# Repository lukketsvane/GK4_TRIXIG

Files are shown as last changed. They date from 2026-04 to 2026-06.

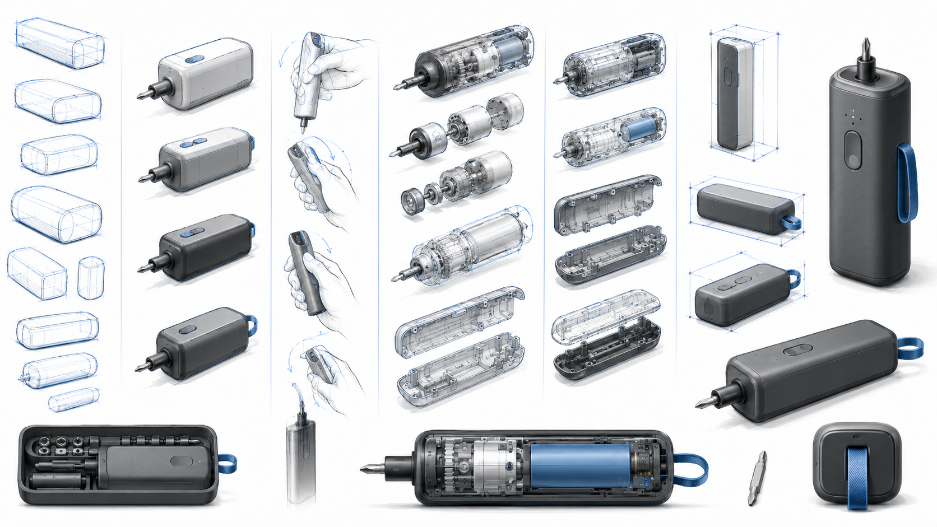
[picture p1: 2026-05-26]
assets/generated/gen_26_05/06_ideation_grids/trixig_260526_u158_component-catalog-board.png

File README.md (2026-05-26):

# GK4_TRIXIG

Organized project repository for the TRIXIG redesign work.

## Structure

- `docs/` - project writing, course material, reports, brand notes, and cleanup records.
- `assets/` - reference images, teardown photos, finished graphics, generated concepts, and visual studies.
- `cad/` - Fusion, Blender, Plasticity, print, and model assets.
- `methods/` - Tjalve and method reference material.

Large local-only files at or above 100 MB are kept out of Git under `.local_large_files/`.
Cleanup decisions are recorded in `docs/repo_cleanup/cleanup_manifest.csv`.

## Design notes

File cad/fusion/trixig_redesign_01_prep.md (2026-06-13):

# TRIXIG redesign_01 — Blender prep for Fusion rebuild (2026-06-13)

Source: Blender scene **`redesign_01`** in `trixig_original_and_drafts.blend`.
This documents the sectioning / parting-split / screw layout done on the new sculpt and
the data exported for rebuilding it parametrically in Fusion 360 (next phase, via Fusion MCP).
Mirrors the recipe of the existing master **"IKEA TRIXIG 3.6 original"**
(see `trixig_cad_rebuild_notes.md`).

## Source geometry (in `redesign_01`)

- **`main shell.001`** — 527k-vert hand sculpt = body + grip clamshell. Not watertight
  (147 open edges). This is the part that gets split at Y=0.
- **`front_shell.001`** — separate **nose cap** (X < −159), a distinct molded part; not part
  of the Y=0 body clamshell. Rebuild as its own part in Fusion.
- Accents: `triggere.001`, `reverse.004/005` (fwd/rev rocker), `detail.002/003`, `bit_holder.001`.

All prep work lives in a new collection **`redesign_01_prep`** (delete to revert; the sculpt
master is untouched — work was done on a duplicate `prep_shell_solid`).

## Frame & key dimensions (redesign_01 world, mm)

- **Parting plane = world Y = 0** (global XZ plane). Sculpt is symmetric about it
  (Y centroid 0.06 mm). Split convention: `Shell_Front_pY` (+Y) / `Shell_Back_nY` (−Y),
  same as master's Body_Front/Body_Back.
- Main-shell extents: X [−178.2, 0.6], Y [−24.5, 24.0], Z [3.7, 125.1].
  Full housing (with nose) reaches X −211 (bit-holder/spindle tip).
- **Drive axis**: world −X, at Y = 0, Z = 97.2. Spindle tip at X −211, motor rear at X −104.6.
- Base (lowest point, USB-C/lanyard): X ≈ −45, Z ≈ 3.7. Rear heel: X 0 … −15.

## Internal components (proxies fitted; full meshes exist on disk)

From documented caliper teardown (`assets/reference/teardown/`,
`trixig_motor_girmodul.py`, `trixig_pcb_battery_blender.py`):

- **Motor/gearbox** (total 106.4 mm) on the drive axis: can Ø32×47 → gearbox Ø35×32.4 →
  front boss Ø18×3 → shaft Ø10×24. World X −104.6 (rear) → −211 (tip), Z 97.2, Y 0.
- **PCB+battery**: PCB 95.39×26.31×1.6 with 18650 Ø18.6×65.0 stacked on top (stack ≈20.2).
  Stands raked in the handle: motor-wire end ≈ (−105, 0, 90), **USB-C end at the base**
  ≈ (−45, 0, 12); axis dir (0.61, 0, −0.79), board normal (0.79, 0, 0.61).
- Faithful meshes if needed: `cad/fusion/pcb_battery_asset/trixig_pcb_battery_scaled.obj`,
  `cad/print/trixig_redesign/for_bambu/{motor_gear_module,pcba_board}.stl`.

## Screw system — 5 bosses (final, user-reviewed)

Clamshell screws on the Y=0 plane, **axis along Y**. Spec: Ø2.4 pilot, Ø8.6 × 10 boss,
**M3×12 self-tapping** (matches prior print build `screw_m3x12_0X.stl`).
Layout was placed clear of all keep-outs (motor, battery, fwd/rev rocker, trigger, and the
**base strap/USB cord passage** — deliberately left screw-free), then adjusted by the user:
the original rear-mid screw was removed (→ 5 total) and S1/S2 moved forward to flank the thin
nose shaft at the `front_shell` junction (X < −178) rather than the fat gearbox.

| Screw | X | Z | role |
|---|---|---|---|
| S1 | −189.2 | 110.5 | nose/shaft, top |
| S2 | −189.9 | 83.2  | nose/shaft, bottom |
| S3 | −98.7  | 114.9 | upper body |
| S4 | −69.3  | 34.3  | grip, low |
| S6 | −10.0  | 60.0  | rear heel |

(`screws.json` holds the authoritative coordinates.)

## Debossing

Use repo **`ikea.svg`** (IKEA wordmark, viewBox 751×138, single path, #0058A3) — NOT the
in-scene grease-pencil `ikea.svg`. Per master: badge 38×13 mm R3.5 raised on +Y shell;
wordmark 33 mm wide, debossed 0.4 mm, A-counter island preserved.

## Exported handoff — `cad/fusion/redesign_01/`

| File | Use |
|---|---|
| `sections.json` | Y0 silhouette (78-pt, [X,Z]) + 7 transverse stations (uv + plane co/normal). Primary Fusion sketch input. Ignore loops < 8 pts (sculpt noise). |
| `parting_Y0.dxf` / `.svg` | Y0 silhouette, manual-insert fallback (true mm). |
| `screws.json` | 6 positions + fastener spec. |
| `internal_layout.json` | Motor + PCB/battery placement. |
| `Shell_Front_pY_mm.stl` / `Shell_Back_nY_mm.stl` | Split halves, mm, as visual/measure reference (solid, not yet shelled). |

## Fusion rebuild recipe (next phase, via Fusion MCP)

1. Insert/loft the **Y0 silhouette** (sections.json) on the XZ plane → main solid; refine
   profile against the transverse stations.
2. Split on Y=0 → Body_Front (+Y) / Body_Back (−Y).
3. **Shell to 1.6 mm** (remove pilots/bosses first, re-add after — small/raised features
   can't offset; see master gotchas).
4. Add 6 Ø8.6 bosses on Body_Back at the screw (X,Z); Ø2.4 pilots through both halves.
5. Badge + debossed IKEA wordmark on +Y shell.
6. Openings: fwd/rev rocker slot, USB-C pill at the base.
7. Nose cap (`front_shell`) as a separate part around the gearbox/spindle.

## Caveats

- Sculpt is not watertight; STL halves are solid blocks (Fusion rebuilds clean surfaces from
  the section profiles — the meshes are measurement references only).
- Component proxies are envelopes from caliper dims; placement verified visually against the
  Y0 outline but is ±a few mm — re-confirm clearances once Body shells exist.
- No Fusion MCP was connected during this prep; the rebuild is the next session.

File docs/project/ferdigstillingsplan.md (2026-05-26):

# Ferdigstillingsplan — GK4 V26 Modul 2 TRIXIG

*Generert 28. april 2026 (dag 2 av 18). Sluttfrist 27. mai 2026.*
*Basert på gjennomgang av designbrief, prosjektbeskrivelse, debrief-utkast, eksisterande figurar/skisser, og Skulberg/Bjørnstad si metodikk-forelesing.*

---

## 0. Tidsline (dei kritiske datoane)

| Dato | Klokke | Leveranse | Form |
|---|---|---|---|
| **Ma 4. mai** | 09:00 | Personleg debrief | Moodle (PDF/DOCX) |
| **Fr 8. mai** | dagtid | Konseptgjennomgang (gruppeseanse) | Munnleg + 3 fysiske skissemodellar |
| **Fr 8. mai** | 20:00 | 3B-analyse, kravspec, bærekrafthandling, 3 konsept­bilete + valt | Moodle |
| **Ma 11. mai** | 09:00 | Formføringsplansje + 3 verdiord | Moodle |
| **On 13. mai** | dagtid | Gjennomgang formkonsept (gruppeseanse) | Munnleg |
| **Ma 25. mai** | 20:00 | Digital sluttpresentasjon + 3 modellbilete | Moodle |
| **Ti–On 26.–27. mai** | plenum | Sluttpresentasjon + 1:1 utseendemodell | Munnleg + fysisk |

---

## 1. Status — kva som finst, kva som manglar

### 1.1 Kva som er ferdig eller nær ferdig

**Tekstgrunnlag:**
- `debrief-modul2-trixig.docx` — fullstendig 7-seksjons debrief med marknadsanalyse, teardown, EU-rammer, R2R-indeksar, materialkunnskap, ergonomi, brukar­innsikt, problemområde, 3B-analyse, kravspec og kjelder. Klart til formattering for innlevering.
- `notat/Konseptgjennomgang_8mai.md` — 12 slides med tre konseptforslag (Trixig+, Tactil, Modular), vurderingsmatrise og valt konsept. Manglar berre fotografi av dei fysiske skissemodellane.
- `notat/Formføringsplansje_11mai.md` — fullstendig drøfting av tre verdiord (Synleg, Stille, Truverdig) med referanseobjekt og A3-layout-spec. Manglar bildemateriale frå referanseobjekta og final A3-eksport.
- `notat/Prototypedokumentasjon.md` — full byggjeplan med BOM, leverandørar og tidsplan for både foam-prototype (P1) og funksjonell prototype (P2).
- `notat/Produksjonskjede_TRIXIG.md` — 10-leddskartlegging av forsyningskjeda frå kobolt til kassering, med IKEA-eigarstruktur og IWAY-grenser.

**Visuelt grunnlag:**
- `ferdigstilt_grafikk/figurar/figur=01..13` — ferdige illustrasjonar (heroshot, hand­percentilstudie ×2, regulatorisk tidsline, kritikkringen, IKEA-stigen, FIXA-vs-TRIXIG-eske ×2, instegspris, naming­kritikk, forretningsmodell-tidsline, posisjoneringskart, spesifikasjonsark).
- `ferdigstilt_grafikk/grafikk=01..04` — IKEA-logo-variantar.
- `ferdigstilt_grafikk/skisser/` — produktskisser med bakgrunn fjerna (Trixig-illustrasjon, exploded view, serviceport).
- `ferdigstilt_grafikk/teardown/` — fem teardownfoto.
- `skisser/skisse_001..100` + `skisser/figur/figur_001..029` — 130+ konseptskisser (rådata).

**Modellgrunnlag:**
- `trixig/trixig.usdz` — eksisterande 3D-fil av originalen (referanseobjekt for sammenlikning).
- `teardown/Trixig_plus.scad` — OpenSCAD-utkast (sjekk om det er nyttig for Fusion-import eller om me skal byggje frå null).

### 1.2 Kva som manglar

**Research som ikkje er gjort enno:**
- Kvantitativ brukarundersøking (sjå seksjon 3.1).
- Strukturerte brukarintervju og observasjon (sjå 3.2).
- Antropometriske målingar i hovet (eigen hand mot DINED 5/50/95-percentilar) (sjå 3.3).
- Konkurrent-prising og hyllesjekk i fysisk butikk (Biltema, Clas Ohlson, Jula, IKEA) (sjå 3.4).
- Brand-audit av TRIXIG-serien (heile sortimentet, ikkje berre 3,6 V) (sjå 3.5).

**Spesifikasjonar som ikkje er detaljerte:**
- Komplett BOM for Trixig+ med leverandørar, einingspris og kostnadsmål (skal liggje under +11 NOK per eining over original).
- Strektegning A3 sideview med kotering.
- Materialspec med ISO 11469-koder, rPCR-andel, leverandørreferansar.
- CMF-board (Colour-Material-Finish) med fysiske prøver.
- Tolerance-spec for 18650-fjørholder, kapsling-pasning og Torx-skruekrager.

**Modellbygging:**
- 3 blåskum-skissemodellar for konseptgjennomgang 8. mai.
- 1 blåskum 1:1 utseendemodell for sluttpresentasjon (utan farge per krav).

**CAD:**
- Fusion 360-modell (heile produktet, inkludert eksplodert visning).
- 3D-rendering for digital presentasjon.

**Designdagbok:**
- Ingen eksisterande fil. Skal førast fortløpande — sjå 6.

**Innleverings­filer:**
- Eksport av debrief til PDF.
- Eksport av Konseptgjennomgang til presentasjons-PDF + separate Moodle-filer.
- Eksport av Formføringsplansje til A3-PDF.
- Sluttpresentasjon (PowerPoint eller Keynote).

---

## 2. Leveransematrise

| Leveranse | Krav (frå kursdok) | Status | Kva manglar | Frist |
|---|---|---|---|---|
| Personleg debrief | Designbriefen reflektert + eige standpunkt | Utkast komplett | Format­tering, illustrasjons­plassering, eksport til PDF | 4.5. 09:00 |
| 3B-analyse | Brukar / Bruksituasjon / Bruksmåte | Utkast i debrief + slide 4 i Konseptgjennomgang | Standalone PDF, kanskje styrkast med kvant data | 8.5. 20:00 |
| Kravspec | Estetisk/Ergonomi/Teknisk/Marknadsøkonomi/Bærekraft + Skal/Bør/Kan | 30 krav lista i Konseptgjennomgang slide 5; 6 kategoriar i debrief 5 | Konsolidering til éin matrise (5×3) etter Skulberg si mal, prioriteringsmerking | 8.5. 20:00 |
| Bærekrafthandling | ≥ 1 konkret handling med målbar effekt | Definert (utbyttbart batteri + reparerbart hus + ISO-merking + 7 års reservedelar) | Standalone PDF med målbar effekt-estimat | 8.5. 20:00 |
| 3 konseptforslag | Skissemodellar + bilete | Konsept utvikla på papir; modellar ikkje bygde | **Bygg 3 blåskum-modellar; fotografer**| 8.5. 18:00 |
| Vald konsept | Markering | Trixig+ er valt i tekst | Ein-setning .txt + foto av valt | 8.5. 20:00 |
| Formføringsplansje | A3 med 3 verdiord + form-DNA | Tekst komplett | Eksport, referansebilete, strekteikning | 11.5. 09:00 |
| Sideview-strekteikning A3 | Som grunnlag for volummodell | Skisse i Prototypedok kap. 3 | Reint A3-format med kotering | 11.5. 09:00 |
| 1:1 fysisk utseendemodell | Utan farge | Ikkje starta | **Bygg etter blåskum-prosess** | 25.5. 18:00 (foto­dato) |
| 3 modellbilete | Front, side, perspektiv | n/a | Ta etter modell ferdig | 25.5. 20:00 |
| Fusion 360 CAD | Detaljert med modulgrenser | Ikkje starta (.scad finst som grunnlag) | **Heil modellering** | 25.5. 18:00 |
| 3D-rendering | I Fusion 360 | Ikkje starta | Render etter CAD ferdig | 25.5. 18:00 |
| Digital sluttpresentasjon | Løysing + bærekrafthandling + materialvalg + formuttrykk + brand-pos + render | Ikkje samla | **Slå saman alle delar i éin PPT/Keynote** | 25.5. 20:00 |
| Designdagbok | Fortløpande | Ikkje ført | **Føre kvar dag** (sjå 6) | løpande |

---

## 3. Research-plan

Briefen er i hovudsak skriven, men det manglar empiri som vil styrke argumenta i sluttpresentasjonen og som sensorane vurderer under "prosjektets troverdighet i bedriftskontekst" og "produktets bruksverdi for tiltenkte sluttbruker". Research­arbeidet bør komprimerast til ei intens veke (28. april–4. mai), parallelt med ferdigstilling av debriefen.

### 3.1 Kvantitativ brukarundersøking

**Mål:** Validere persona-hypotesane i debriefen (ambisiøs amatør, leigetakar/student, sporadisk brukar). Få fram tal for jobs-to-be-done, smertepunkt og betalingsvilje.

**Metode:** Online-spørjeskjema via Google Forms eller Typeform, distribuert i tre kanalar:
- AHO/UiO-studentkull (leigetakar/student-segment)
- Facebook-grupper for DIY ("Jeg liker å bygge", "Oppussings­tips") (amatør-handverkar)
- Eige nettverk via LinkedIn (sporadisk brukar)

**Spørsmål (ca. 20 stk):**
1. Eig du elektrisk skrutrekkar? Kva merke/modell?
2. Kor ofte brukar du han? (skala: kvar dag — aldri)
3. Kva oppgåver brukar du han til? (multi-select: flatpakke-møblar, gardin­stenger, dørhandtak, hyller, småreparasjon, anna)
4. Kor mykje betalte du? Var det med tilbehør i esken?
5. Har batteriet svikta? Kva gjorde du då?
6. Har du forsøkt å reparere? Kva hindra deg?
7. Kor viktig (1–5) er: pris / merke / reparerbarheit / utskiftbart batteri / tilbehør i esken / ladetid / vekt / dreiemoment?
8. Skala 1–5: kor mykje ekstra ville du betalt for: utskiftbart batteri / 7 års reservedelar / tilbehør i esken / lengre garanti?
9. Demografi: alder, kjønn, bustad­situasjon (leigar/eigar), inntekt­band.

**Mål for utval:** N ≥ 50 svar, fordelt på ~30 % per persona.

**Tid:** Distribusjon 28.4. — datasamling 28.4.–3.5. — analyse 3.–4.5.

### 3.2 Kvalitative brukarintervju

**Mål:** Få djupne på smertepunkt som ikkje fangast i Likert-skala. Validere semantikk-hypotesar (asymmetrisk retningsbrytar, status-LED-stripe).

**Metode:** Halvstrukturerte intervju, 30–45 min per person, 3–5 informantar fordelt på personae. Showe TRIXIG-original og spørje "kva er problemet med denne?", "kva ville du endra?".

**Tid:** 29.–30. april (parallelt med spørjeskjema).

**Logg:** Notater og lydopptak (med samtykke) i `notat/intervju/`.

### 3.3 Antropometri og handpassing

**Mål:** Verifisere at 110° grepvinkel og 32–38 mm grepdiameter dekkjer 5.-perentil kvinne til 95.-perentil mann. Få faktiske handmål frå minst tre forsøkspersonar i ulik storleik.

**Metode:**
- Mål handlengde, handbreidde, tommel-omkrins frå tre personar (familiemedlem + medstudent + ein større/mindre informant).
- Samanlikne mot DINED-tabell (TU Delft) eller Pheasant Bodyspace 2006.
- Test grepskomfort på TRIXIG-original, evt. modifisert med tape/skum for å simulere endringar.
- Lag enkel grafikk av hand i tre storleikar over Trixig+-silhuett (vidareføring av figur=02 og figur=05).

**Tid:** 1.–2. mai (laurdag/sundag).

### 3.4 Konkurrentanalyse i fysisk butikk

**Mål:** Eksakte prisar, vekter, esketuinnhald, og hylleplassering for Bosch IXO, HOTO, Bauhaus-kjedevarer, Biltema, Clas Ohlson sine eigenmerke. Fotografi frå hylla.

**Butikkar:**
- IKEA Slependen (TRIXIG/TRIXIG 12V/eksisterande FIXA om finst)
- Clas Ohlson Storo (Cocraft LXC + Bosch IXO)
- Biltema Alnabru (Biltema-eigne + lågprisalternativ)
- Bauhaus Kalbakken / Maxbo (Bosch + DeWalt)

**Kva noterast:** Hyllepris, kva som ligg i esken, kva tilbehør sel separat, vekt frå emballasje, materialinntrykk.

**Tid:** 30. april (ein dag i butikkar).

### 3.5 Brand-audit TRIXIG-serien

**Mål:** Verifisere at Trixig+ ligg innanfor TRIXIG si visuelle ramme. Lag skjema med alle TRIXIG-produkt og deira form-DNA.

**Metode:**
- Kartlegg alle TRIXIG-produkt på ikea.com (skrutrekkar 3,6 V, drill 12 V, hammar, skiftnøkkel-sett, måleband, om relevant).
- Lag formspråk-matrise: pistolform / inline / tool­shape, hovudfarge, akssentfarge, materialinntrykk, logoplassering, snormarkør.
- Identifiser dei to-tre mest karakteristiske brand-markørane som Trixig+ må respektere.
- Krysssjekk mot IKEA brand guidelines (`ikea_profil/Brandmark_TrixigPlus.md` har eit utkast).

**Tid:** 2. mai (parallelt med antropometri).

### 3.6 Produksjons­spesifikasjon — kva skal Trixig+ faktisk vere?

**Mål:** Frå konseptbeskriving til konkret BOM, leverandørar, einingspris.

**Komponentar som skal spesifiserast:**

| Komponent | Original­spec | Trixig+-spec (mål) | Leverandør (ev.) | Einings­pris (NOK) |
|---|---|---|---|---|
| 18650 Li-ion-celle | INR19/66, 1,5 Ah, lødde | 18650 standard, 1,5–2,0 Ah, fjørmontert | Samsung 25R / LG MJ1 / Molicel P26A | 25–35 |
| Motor | DC 385-typen, 3,6 V | DC 385-typen, behaldt | Original-leverandør | 22 |
| Planet­gear | 60:1, POM | 60:1, POM, behaldt | Original | 8 |
| Bitsfeste | 1/4″ hex, magnet | 1/4″ hex, magnet, brushed steel collar | Standard | 6 |
| PCB (TP4056 + BMS) | Integrert | Modulær (bytbar) | Original eller Aliexpress-OEM | 12 |
| ABS-skall (2 halvdelar) | Tokomp. ABS+TPE | 30 % rPCR ABS, mono-material, ISO 11469-merka | Lavpris-spr. mole. Kina | 8 |
| Torx T10-skruver M3×16 | n/a (selvskruver) | A2 stål, 6 stk | Bossard / Wurth standardlager | 1,80 |
| M3 hex-hylser | n/a | Messing, 8 mm djup, 6 stk | Bossard | 3 |
| Fjørholder 18650 | n/a (lødde) | Standard fjørholder med 2 kontakt­fjør | Aliexpress-OEM | 4 |
| Status-LED-PCB | n/a | 4× 0805-LED + driver | Aliexpress-OEM | 5 |
| Asymmetrisk retningsbrytar | symmetrisk vippe | Egendesignet, konveks/konkav | DPDT-bryter + 3D-printa cap | 6 |
| Stropp + ferrule | Standard | Behaldt | Original | 3 |
| Diverse ledningar, krymp, lim | — | — | — | 5 |

**Total estimert einings­kost (Trixig+):** ca. 109 NOK BOM, vs. estimert 90 NOK for original = +19 NOK BOM. Med 50 % marginpåslag → 219 NOK utsalgspris (+11 % over original). Innanfor mål.

**Tid:** 4.–5. mai (rett etter debriefen er innlevert).

---

## 4. Dag-for-dag-plan, 28. april – 27. mai

*Norske dagar. Klokke­slett er forpliktande for synkrone aktivitetar (forelesingar, gruppe­seansar, innleveringar) og rettleiande for individuelt arbeid.*

### Veke 18 — research, semantikk, kravspec (28.4. ferdig fase 1 til 4.5.)

**Måndag 27.4.** *(allereie gjort)*
- Prosjekt-intro, semantikk-workshop trykke/skyve/vri.

**Tysdag 28.4.** ← **i dag**
- 09–12 Semantikk-workshop modellbygging (verkstad).
- 13–15 Semantikk semifinale + finale.
- 15–17 **Distribuer kvant spørjeskjema (3.1).** Identifiser tre intervju­informantar (3.2).
- 17–20 Bilete­arbeid: kople ferdig­stilt grafikk inn i debrief-utkastet, oppdater illustrasjonsforslag.

**Onsdag 29.4.**
- 09–12 Workshop produktsemantikk, hånd og grep (Nina).
- 13–15 Brukarintervju #1 (telefon eller fysisk).
- 15–17 Polering av debrief seksjon 1–4.
- Kveld: følg med på spørjeskjema-svar, send påminning om naudsynt.

**Torsdag 30.4.**
- 09–12 **Konkurrentanalyse i butikk** (3.4). Bilete + notater.
- 13–15 Brukarintervju #2.
- 15–18 Inkorporere butikk­funn i debrief seksjon 2.1 og 5.6.
- 18–21 Polering debrief seksjon 5–7.

**Fredag 1.5.** *(arbeidardagen — ikkje undervisning)*
- 09–12 Antropometri-måling (3.3). Lag handpercentil-grafikk (vidareføring av figur=02 + 05).
- 13–17 Brukarintervju #3.
- 17–21 Konsolidere kvalitative funn.

**Laurdag 2.5.**
- 09–13 **Brand-audit TRIXIG-serien** (3.5). Form-DNA-matrise.
- 13–17 Polering Formføringsplansje med audit-funn.
- Kveld: ev. søk etter referansebilete (Festool ETS, Vola FS1, Olivetti Lettera 22, Braun T1000, Muji CD-spelar, Olivetti Valentine, Braun ET 88, Vitsoe 606, Festool batteripakke).

**Sundag 3.5.**
- 09–13 Analyser kvant-data. Lag tre figurar for innlevering.
- 13–17 Skriv saman debrief til ferdig form (Word eller InDesign), eksporter PDF.
- 17–21 Korrektur. Sjekk at alle figurar har figurnummer + kjelde.

**Måndag 4.5.**
- 08:00–09:00 Siste sjekk + **Moodle-innlevering personleg debrief 09:00**.
- 10–14 Forelesing eller veiledning (Anders/Nina).
- 14–18 Detaljering av kravspec (omsetting til 5×3-matrise etter Skulberg sin metode).
- 18–21 Skissevurdering: gå gjennom 130+ skisser, vel ut dei 3 beste retningane som mappar til Trixig+, Tactil, Modular.

### Veke 19 — konseptgjennomgang (5.5. – 8.5.)

**Tysdag 5.5.**
- 09–12 **Modellbygging blåskum dag 1** (verkstad). Trixig+-modell — fokus på ergonomi og dei fem kjenneteikna grepa.
- 13–17 Trixig Tactil-modell — TPE-overstøp simulert med syntetisk pels.
- 17–20 Bærekrafts­tekst som standalone (sjå Konseptgjennomgang_8mai.md slide 6).

**Onsdag 6.5.**
- 09–13 **Modellbygging blåskum dag 2.** Trixig Modular — kjernemodul + lengjehandtak.
- 13–17 Detaljering. Pussing, malingsprøvar (men hugs: utseendemodell skal vere utan farge — desse modellane er skissemodellar og kan ha sparsam fargemarkering).
- 17–20 BOM-arbeid (3.6) for Trixig+ (vald konsept).

**Torsdag 7.5.**
- 09–12 Foto­seanse av dei tre modellane. Front + side + perspektiv per modell, totalt 9 bilete + ev. ein samanlikningsoppstilling.
- 13–16 Førebu konseptgjennomgang-presentasjonen (12 slides — eksisterande manus i Konseptgjennomgang_8mai.md). PowerPoint eller Keynote.
- 16–19 Eksporter vurderingsmatrise, 3B-analyse, kravspec og bærekrafthandling som standalone PDF-ar.
- 19–21 Generalprøve munnleg framføring (10 min + 5 min spm).

**Fredag 8.5.**
- 09–14 **Konseptgjennomgang i gruppeseanse.** Presenter 12 slides, motta tilbakemelding, motivér konseptval.
- 14–18 Inkorporer veiledar­tilbakemeldingar.
- 18–20 Final eksport av alle Moodle-filer.
- **20:00 Moodle-innlevering** (3B-analyse, kravspec, bærekrafthandling, 3 konseptbilete, valt konsept).

### Veke 20 — formutvikling og formføringsplansje (11.5. – 15.5.)

**Måndag 11.5.**
- 08:00–09:00 **Moodle-innlevering Formføringsplansje 09:00** (eksisterande tekst i Formføringsplansje_11mai.md, må eksporterast til A3 PDF med referansebilete inkludert).
- 09–13 Strektegning A3 sideview av Trixig+ med dei tre nye elementa markerte.
- 13–17 Oppstart Fusion 360. Importere/byggje grov mass-modell.
- 17–20 Formdetaljering — radiar, skrueposisjon­ar, retningsbrytar­geometri.

**Tysdag 12.5.**
- 09–17 Fusion 360 — ferdig grov modell, alle modulgrenser.
- 17–20 Førebu munnleg gjennomgang for onsdag.

**Onsdag 13.5.**
- 09–14 **Gjennomgang formkonsept i gruppeseanse** (Nina). Presenter formføringsplansje, motta tilbakemelding.
- 14–17 Inkorporer tilbakemeldingar i CAD og plansje.
- 17–20 Detaljering — chamfer, fillet, partingslines.

**Torsdag 14.5.**
- 09–17 Fusion 360 — full detaljering. Innebygde Torx-skrue­krager. ISO-merking innstøypt på innside av skall.
- 17–20 Eksporter STL-filer for 3D-printing av prototype-skall (om P2 vert bygd).

**Fredag 15.5.**
- 09–17 Fusion 360 — render-førebuing. Material-tildeling. Lyssetjing.
- 17–20 Render første pass. Sjekk geometriproblem.

### Veke 21 — CAD og modellbygging (18.5. – 22.5.)

**Måndag 18.5.** og **Tysdag 19.5.**
- **Hovudfokus: bygge 1:1 utseende­modell i blåskum** (verkstad).
- Fem-lags blåskum, kontaktlim, smerg­ling. Sjå Prototypedokumentasjon kap. 4.
- Modellen skal vere utan farge (kursetkrav).
- Detaljar: sett inn dummy 18650-celle, dummy retningsbrytar i konveks/konkav, dummy LED-stripe.

**Onsdag 20.5.**
- 09–13 Modell-finishing (pussing korn 400, ev. enkelt grunningstrøk).
- 13–17 **Foto­seanse av 1:1-modellen.** Tre bilete (front, side, perspektiv) i god lyssetjing, ev. på nøytral bakgrunn (kvit eller grå).
- 17–21 Fusion 360 — finale render­pass.

**Torsdag 21.5.**
- 09–13 Render to perspektiv + eksplodert visning + closeup på batterimodul.
- 13–17 Bygg sluttpresentasjon (PowerPoint eller Keynote). Forventa struktur:
  1. Tittel + ein-setning posisjonering
  2. Premiss og kontekst (EU 2027 + IKEA-stigen)
  3. 3B-analyse (kondensert)
  4. Kravspec (matrise-format)
  5. Tre konsept (frå konseptgjennomgang) + valgt
  6. Trixig+ form-DNA + dei 3 verdiorda
  7. Eksplodert visning av Trixig+
  8. Dei fem kjenneteikna grepa (visuell forklaring)
  9. Bærekrafts­handling med målbar effekt
  10. Materialvalg og BOM (kondensert)
  11. Brand-tilhøyrsle (TRIXIG-DNA-matrise)
  12. Render(ar) av sluttforslaget
  13. Foto av 1:1-modellen
  14. Vegen vidare (regulatoriske rammer, kommersiell logikk)
- 17–21 Generalprøve.

**Fredag 22.5.**
- 09–13 Korrektur og polering. Sjekk skrift­konsistens, bilete­eigarskap, kjelde­henvising.
- 13–17 Lag printa A3-plansje-versjon for å henge i sal.
- 17–20 Generalprøve nr. 2.

### Veke 22 — sluttinnlevering og presentasjon (25.5. – 27.5.)

**Måndag 25.5.**
- 09–14 Siste justering, stress-test framføring.
- 14–18 Polering bilete, tekst, animasjonar.
- 18–20 Eksporter til PDF og PPT, samanstill alle Moodle-filer (digital presentasjon + 3 modellbilete).
- **20:00 Moodle-innlevering sluttpresentasjon.**

**Tysdag 26.5. eller Onsdag 27.5.**
- Plenum­presentasjon (10 min framføring + 10 min spm).
- Demonstrasjon av fysisk modell.

---

## 5. Kritiske risikoar og avbøtingar

| Risiko | Sannsynleg | Konsekvens | Avbøting |
|---|---|---|---|
| Spørjeskjema får < 30 svar | Medium | Tynn empiri | Ta med kvalitative funn som hovud­dokumentasjon, kvant blir illustrerande |
| Brukarintervju ikkje fast in tid | Medium | Forseinking | Bestil minst 5 informant­slots, ver fleksibel på dato |
| Verkstad­plass ikkje ledig 5.–6.5. | Høg | Modellbygging stoppar | Bestill verkstad-time **i dag**; ha hjemmeløysing klar (skuredust + kjøkkenbenk) |
| 1:1-modell tek lengre enn forventa | Høg | Sluttpresentasjon utan modell | Start dagar 18.–20.5. (tre fulle dagar avsette); ha foam-prototype som backup |
| Fusion 360 har ikkje all kapasitet eg treng | Medium | Render lite imponerande | Vurder Rhino + KeyShot for render om Fusion ikkje når ut |
| Brand-audit avdekker at Trixig+ ikkje er truverdig som TRIXIG | Låg | Form-revisjon | Spar to dagar i veke 20 til form­revisjon dersom audit gir alvorleg innspel |
| Moodle nede ved innlevering | Låg | Forseinka levering | Eksporter kvar leveranse 4–6 timar før deadline |
| Sjukdom siste veke | Låg | Heile sluttveka tapt | Hold modell og presentasjon på 80 % ferdig nivå innan 20.5., slik at siste veke er polering |

---

## 6. Designdagbok — protokoll

Dagboka skal førast fortløpande (kursetkrav). Ho ligg som ein einskild fil `notat/designdagbok.md`. Kvar dagbok-oppføring har:

- **Dato.**
- **Tid på dagen.**
- **Aktivitet i overordna form** (research, skissering, modellbygging, CAD, veiledning).
- **Konkrete avgjerder** og kva som motiverte dei.
- **Kva som ikkje fungerte** og kva som skal prøvast i staden.
- **Bilete- eller fil­referansar** (kva fil i prosjektmappa dokumenterer dette).

Eksempel-format:

```
## 2026-04-28, tirsdag — dag 2

09:00–12:00. Semantikk-workshop trykke/skyve/vri på verkstad. Bygde tre
modellar i Cibatool, valde "vri" som vinnar i mi gruppe pga at den koniske
overflata bar handlinga klarare enn flat dreieskive.

13:00–15:00. Semifinale og finale plenum. Klassen valde tre
representant­modellar; mi gruppe sin kom ikkje med. Læring: Form
verifisering må vere taktil, ikkje berre visuell.

15:00–17:00. Distribuerte kvant­spørjeskjema (3.1) til 4 kanalar.
Identifiserte 3 intervju­informantar. Sende invitasjon.

17:00–20:00. La inn ferdig­stilte figurar i debrief­utkastet. Sjå
debrief-modul2-trixig.docx versjon 0.4.

Avgjerd: Beheld den asymmetriske retningsbrytaren som S1-uttrykk i
formføringsplansja, fordi semantikk-finalen viste at konveks/konkav
faktisk leser sterkare enn pil-grafikk åleine.
```

---

## 7. Dei første tre tinga eg gjer no

1. **Bestill verkstad-time** for 5.–6. mai (modellbygging blåskum) og 18.–20. mai (1:1-modell). Send mail til verkstad­ansvarleg i dag.
2. **Distribuer kvant-spørjeskjema** (3.1). Forventar første svar i kveld; hovudbølgje kjem ila. dei to neste dagane.
3. **Identifiser tre intervju-informantar** (3.2). Send 30-min Calendly-lenke for slot 29.4.–1.5.

Når desse tre er gjort, er research-blokka i gang og ein har frigjort hovudet til å arbeide med debrief-formaltering parallelt.

---

## 8. Filstruktur som styringsverktøy

For å halde oversikt under intensitet vert mappa organisert slik:

```
GK4_TRIXIG/
├── notat/
│   ├── ferdigstillingsplan.md          ← denne
│   ├── designdagbok.md                  ← oppdaterast dagleg
│   ├── Konseptgjennomgang_8mai.md       ← klar
│   ├── Formføringsplansje_11mai.md      ← klar, treng A3-eksport
│   ├── Prototypedokumentasjon.md        ← klar
│   ├── Produksjonskjede_TRIXIG.md       ← klar
│   ├── intervju/                        ← nytt: råopptak/-notater
│   ├── kvant_resultat/                  ← nytt: spørjeskjema-eksport
│   ├── butikkbesok/                     ← nytt: foto frå konkurrent­butikkar
│   └── brand_audit/                     ← nytt: TRIXIG-serien-foto
├── ferdigstilt_grafikk/
│   ├── figurar/figur=01..13             ← klare illustrasjonar
│   ├── grafikk=01..04                   ← logo-variantar
│   ├── skisser/                         ← bakgrunnsfjerna skisser
│   └── teardown/                        ← fem teardownfoto
├── assets/generated/skisser/            ← rådata, 130+ skisser
├── assets/reference/teardown/           ← teardown- og produktfoto
├── docs/brand/                          ← brand-grunnlag
├── docs/course/                         ← orginale kursdokument
├── docs/project/                        ← prosjekt- og produktdokument
├── docs/deliverables/                   ← berre eksporterte filer for Moodle
├── debrief-modul2-trixig.docx           ← under arbeid
└── personleg-debrief-trixig.pdf         ← versjon 0.X
```

---

## 9. Kva eg ber om frå deg no

Eg har ført planen med eit konservativ stilval — så litt overdimensjonering på research, og ein klar marsjordre kvar dag. Etter at du les gjennom kan du:

1. **Korrigere prioriteringar.** Skal noko fjernast (for mykje kvant?) eller leggjast til (manglande tema?).
2. **Bestemme om me skal bygge P2 funksjonell prototype** i tillegg til 1:1-utseendemodellen, eller berre P1. Kursetkrav = berre 1:1-utseendemodell utan farge. Pluss-poeng for funksjonell prototype, men det krev ekstra ~30 timar.
3. **Bestemme verktøyval for sluttpresentasjon:** PowerPoint, Keynote, eller InDesign-PDF? Påverkar render-format og animasjon.
4. **Stadfeste at Trixig+ er valt konsept.** Konseptgjennomgang_8mai.md har det allereie som vinnar — om du heller vil ta Tactil eller Modular i sluttinnspurten må me revidere planen.

Når desse fire punkta er stadfesta, byrjar me å eksekvere.

---

*v1.0 — 28. april 2026, dag 2 av 18.*

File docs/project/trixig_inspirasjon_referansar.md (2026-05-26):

# TRIXIG redesign — visuell research & inspirasjonskartlegging

**Brief:** Kome vekk frå "L"-pistolforma. Behalde dei to hovudkomponentane: éi battericelle (~18650, ø18×65 mm) og éin gearmotor med utgåande aksel (~ø25×60 mm). Plus PCB, trigger og retningsknapp.

**Domene for inspirasjon:** *hushaldsreidskap* (IKKJE verktøy/drillar). Prioritert: ikoniske / prisvinnande / historisk viktige design som løyser same arkitektoniske utfordring — å pakke ei sylindrisk celle og ein motor med aksel inn i ei hand-haldt form.

---

## Formarketypar — oversikt

```
A. WAND / STAV          — inline sylinder, motor + batteri ende-mot-ende
B. PALM / PEBBLE        — kompakt blob i handflata
C. OVOID / EGG          — avlangt egg, batteri og motor pakka tett
D. KOLONNE / TOTEM      — vertikal stabling, ofte med dock
E. BUE / KURVE          — organisk handgrip, ikkje 90°
F. RING / DONUT         — hol gjennom kroppen
G. TODELT / MODULÆR     — separat dock eller batteripakke
```

---

## A. WAND / STAV — *inline sylinder*

Den reinaste løysinga for to-komponent-arkitektur: legg motor og batteri ende-mot-ende. Resulterer i ei lang, slank stav. Ergonomisk lik ein tjukk penn.

| # | Referanse | Designar / år | Kvifor relevant |
|---|---|---|---|
| A1 | **Bamix M200** stavmiksar | Roger Perrinjaquet, 1954 (Sveits) | Definerer kategorien. Motor i topp, aksel i botn. Industriikon, framleis i produksjon uendra. |
| A2 | **Braun MR 30** håndmiksar | Braun Design Team (Rams-era), ~1976 | Streng tysk minimalisme. Sjå silinderbrot og knappplassering. |
| A3 | **Quip elektrisk tannbørste** | Simon Enever, 2015 | Cooper Hewitt-samlinga. Reduksjonistisk pen. Magnetisk dock. |
| A4 | **Philips Sonicare DiamondClean** | Philips Design, 2011 (Red Dot) | Slankt handtak, glas-dock. Premium-uttrykk i lågt volum. |
| A5 | **Foreo ISSA 2** | Foreo, 2014 | Silikonkledd stav. Mjuk-hard materialkontrast. |
| A6 | **Maglite Solitaire** | Anthony Maglica, 1988 | Single-cell-arketype. MoMA-samlinga. Knurla aluminium. |
| A7 | **Aerolatte mjølkeskumar** | Aerolatte, 2002 | Den enklaste mogelege wand. Eitt batteri, ein motor, ein knapp. |
| A8 | **Apple Pencil (2. gen)** | Apple, 2018 | Ergonomi for langvarig grep. Flat side mot rulling. |

**Søkeord til Figma:** `bamix classic`, `quip toothbrush product`, `sonicare diamondclean handle`, `maglite solitaire`, `aerolatte original`

---

## B. PALM / PEBBLE — *kompakt blob*

For når ein vil ha minst mogeleg lengde. Batteri og motor ligg parallelt eller diagonalt inni ein avrunda kropp som kviler i handflata. Trigger med tommel.

| # | Referanse | Designar / år | Kvifor relevant |
|---|---|---|---|
| B1 | **Foreo LUNA** | Foreo, 2013 (Red Dot, iF Gold) | Ikoniske palm-form. Silikon utvendig, motor + celle innvendig. |
| B2 | **Clarisonic Mia** | Pacific Bioscience Labs, 2008 | Original "palm-skincare" formfaktor. |
| B3 | **±0 humidifier** | Naoto Fukasawa, 2003 | Ikkje motor, men *blob-arketypen* perfeksjonert. Studer overgangar. |
| B4 | **Magic Mouse** | Apple Industrial Design, 2009 | Ren palm-ergonomi utan knappar. Inneheld batteri. |
| B5 | **B&O Beoplay P2** | Cecilie Manz, 2017 | Palm-pebble med éin trigger. Materialkvalitet. |
| B6 | **Womanizer Premium** | Wow Tech, 2018 (Red Dot) | Single-cell palm-objekt med motor og luftpumpe. Diskret formspråk. |

**Søkeord:** `foreo luna 2`, `clarisonic mia smart`, `naoto fukasawa humidifier plus minus zero`

---

## C. OVOID / EGG — *avlangt egg*

Egget tillèt deg å plassere batteri og motor i skrå linje for å minimere det bredaste tverrsnittet. Held seg pent i hand utan klar "topp/botn".

| # | Referanse | Designar / år | Kvifor relevant |
|---|---|---|---|
| C1 | **Braun Sixtant SM 31** | Hans Gugelot & Gerd A. Müller, 1962 | Ikon. Den fyrste "blackboard"-barbermaskina. MoMA. Sjå svart/sølv-deling. |
| C2 | **Braun Series 9 Pro** | Braun Design, 2016+ | Moderne ovoid med glasspanel. Premium Performance-language. |
| C3 | **Marc Newson Atmos / Nikon DF** | Marc Newson | (Ikkje household, men) ovoid masterclass i overgangar. |
| C4 | **Smeg HMF01 hand mixer** | Smeg + Deepdesign, 2018 | Retro ovoid handgrip. Studer korleis motorhuset møter handtaket. |
| C5 | **Stadler Form Anton** humidifier | Matti Walker, 2010 | Ovoid hushaldskropp. |
| C6 | **Theragun mini** | Therabody, 2020 | Triangulært egg, men i prinsipp ovoid pakking av motor + celle. |

**Søkeord:** `braun sixtant`, `braun series 9 pro`, `smeg hand mixer hmf01`, `theragun mini`

---

## D. KOLONNE / TOTEM — *vertikal stabling*

Du står objektet på endefoten. Batteri i botn, motor i midten, virkemiddel i topp (eller motsett). Ofte med dedikert dock. Veldig slankt fotavtrykk på benken.

| # | Referanse | Designar / år | Kvifor relevant |
|---|---|---|---|
| D1 | **Peugeot Elis Sense** elektrisk pepperkvern | Peugeot, 2017 | Slank kolonne. Sensor-aktivert. Trefinish. |
| D2 | **OXO Mess-Free electric pepper grinder** | Smart Design, 2013 | Skuldra mellom motorhus og handgrip. |
| D3 | **Aēsop / Le Labo dispensarflasker** | (Manuelle, men referanse) | Kolonne-arketype med skulder. Studer proporsjonar. |
| D4 | **Stelton EM77 termoskanne** | Erik Magnussen, 1977 | Dansk ikon. Vertikal kolonne med vippelokk-detaljen. |
| D5 | **Dyson Supersonic** | Jake Dyson + team, 2016 | Motor i handtak, ringen på toppen. (NB: i ditt tilfelle motsett — mat input på toppen.) |
| D6 | **George Sowden kjele for HAY** | George Sowden, 2017 | Fargebruk og overflateoppdeling i ein kolonne-kropp. |
| D7 | **Beoplay A9** høgtalar (ikkje håndhalden) | Øivind Alexander Slaatto, 2012 | Studer disk-til-kolonne-overgangen. |

**Søkeord:** `peugeot elis sense`, `oxo electric pepper grinder`, `stelton em77 thermo jug`, `george sowden kettle hay`

---

## E. BUE / KURVE — *organisk handgrip*

Mellomtinget: ikkje rett 90° L, men ein flytande kurve frå motor-aksel til handgrip. Nesten alle ergonomiske kjøkkenreidskap brukar denne logikken.

| # | Referanse | Designar / år | Kvifor relevant |
|---|---|---|---|
| E1 | **KitchenAid Cordless Hand Mixer KHMB732** | KitchenAid, 2020 | Boge-handtak, batteri i hælen, motor over handa. Direkte parallell. |
| E2 | **Braun MultiQuick MQ 9097** | Braun Design, 2019 | Mjuk S-kurve. Knappplassering for tommel. |
| E3 | **Smeg HMF01** (igjen) | Smeg + Deepdesign | Retro buet handtak. |
| E4 | **OXO Good Grips peeler** | Smart Design / Sam Farber, 1990 | Manuell, men *grep-ergonomi-arketypen*. Cooper Hewitt. |
| E5 | **Mason Pearson hårbørste** | Mason Pearson, 1885 | Klassisk håndhalden bue. Studer korleis tyngda hamnar i handa. |
| E6 | **Bodum Bistro elektrisk mjølkeskumar** | Bodum, 2010 | Kort bue, motor på toppen. |
| E7 | **Hyperice Hypervolt Go 2** | Hyperice, 2022 | Inline-bue mellom batteri og motor. Lett grep. |

**Søkeord:** `kitchenaid cordless hand mixer`, `braun multiquick 9`, `oxo peeler`, `hypervolt go 2`

---

## F. RING / DONUT — *hol gjennom kroppen*

Radikal arketype. Du orienterer motor og batteri rundt eit hol. Lar deg gripe gjennom — som ei trommelstikke eller ein ring. Sjeldan, men distinkt.

| # | Referanse | Designar / år | Kvifor relevant |
|---|---|---|---|
| F1 | **Dyson Supersonic** | Jake Dyson, 2016 | Air Multiplier-ringen. Motor flytta til handtak for å gjere det mogeleg. |
| F2 | **Dyson Airwrap** | Dyson, 2018 | Sylindrisk kropp + skiftbare ringar. |
| F3 | **B&O Beosound A1 / Edge** | Michael Anastassiades + Cecilie Manz | Disk- og ringformer i hushald. |
| F4 | **Loop wireless earbud case** (diverse) | — | Ringgrip-ergonomi. |
| F5 | **Apple HomePod mini** | Apple ID, 2020 | Kuleform med flat fot — for hyllereferanse. |

**NB:** Ringforma er teknisk vanskeleg med 18650 + gearmotor — krev anten omplassering eller dummy-ring. Bruk som *retorisk ytterpunkt* i moodboardet for å presse konseptutforskinga.

**Søkeord:** `dyson supersonic`, `dyson airwrap`, `b&o beosound a1`

---

## G. TODELT / MODULÆR — *separat dock eller batteripakke*

Heldekkleg signal: produktet bur i ein dock når det ikkje er i bruk. Endrar heile presentasjonen — frå "verktøy i skuff" til "objekt på benken".

| # | Referanse | Designar / år | Kvifor relevant |
|---|---|---|---|
| G1 | **Philips Sonicare DiamondClean glas-dock** | Philips Design, 2012 | Induktiv lading via glas. Premium-rituale. |
| G2 | **Foreo LUNA dock** | Foreo | Magnetisk lading, minimal fotavtrykk. |
| G3 | **Braun Series 9 lade-etui** | Braun Design | Reise-etui som er ladar. |
| G4 | **B&O Beoplay E8 ladeetui** | Jakob Wagner, 2017 | Skinn + magnet. Materialitetsreferanse. |
| G5 | **Dyson V8 / V15** stick vacuum | Dyson, 2016+ | Wall-dock + utskiftbar batteripakke (sjølv om V-serien er verktøy-actig — bruk berre dock-løysinga som ref). |
| G6 | **Theragun mini wireless charger** | Therabody, 2022 | Qi-pad. |
| G7 | **Stadler Form Tom hand fan + dock** | Matti Walker | Lite dock-rituale i hushald. |
| G8 | **Thom Browne x Kose ansiktsbørste + dock** *(allereie i din referanse)* | — | Søyle + skål-dock. Sjå korleis verktøy og dock har felles formspråk. |

**Søkeord:** `sonicare diamondclean glass`, `foreo luna charging dock`, `b&o beoplay e8 case`, `theragun mini wireless charger`

---

## Lateral / kuriøs — *push the brief*

Ting som ikkje passar nokon arketype men kan opne idéar:

- **Hario Smart G electric coffee grinder** — handsveiv-form med motor. Vertikal med trakt på toppen.
- **Vintage egg-piskar (manuell, krank)** — to-akse-ergonomi som L-en prøver å løyse.
- **Joseph Joseph foldable ladles** — sammenleggbart hushald. Foldable TRIXIG?
- **Braun HL 1/11 vifte** (Reinhold Weiss, 1961) — sirkulær motor, kompakt kropp. MoMA.
- **Alessi Anna G. korketrekkar** (Alessandro Mendini, 1994) — antropomorf hushaldsikon. Diskuter karakter.
- **Stelton Cylinda Line** (Arne Jacobsen, 1967) — modulært sylindersystem.
- **Joe Colombo Boby trolley** (1970) — modulær arkitektur, søyle med skuffer.

---

## Forslag til moodboard-struktur i Figma

```
Frame 1: BRIEF — Trixig dagens form + dei to komponentane (foto frå IKEA)
Frame 2: ARKETYPE A — wand     (3-5 referansar)
Frame 3: ARKETYPE B — palm     (3-5 referansar)
Frame 4: ARKETYPE C — ovoid    (3-5 referansar)
Frame 5: ARKETYPE D — kolonne  (3-5 referansar)
Frame 6: ARKETYPE E — bue      (3-5 referansar)
Frame 7: ARKETYPE F — ring     (2-3 referansar, retorisk)
Frame 8: DOCK / MODULÆR        (ramme på tvers — kan kombinerast med kva som helst over)
Frame 9: LATERAL — kuriøse hushald
Frame 10: SHORTLIST — 6-8 referansar du faktisk vil utvikle vidare
```

For kvar referanse: 1 hovudbilete + 1 detaljbilete + namn/designar/år + 1-setnings notat om *kva du tek med*.

---

## Neste steg når du har plassert bilete

Når moodboardet er fylt, kan eg hjelpe deg med:

1. **Komponent-pakkings-skissar** — vise korleis 18650 + gearmotor faktisk får plass i kvar arketype (volumstudie, ikkje CAD).
2. **Vekt- og tyngdepunkt-analyse** — kor handa må vere for at du ikkje bommar.
3. **Trykk- og ergonomi-vurdering** — kva arketypar tek best opp aksial reaksjonskraft når du skrur.
4. **Konsept-shortlist-evaluering** — pro/kontra-matrise mot brief.

Sei frå når du er klar.

[Open referanse-dokumentet](computer://C:\Users\Shadow\Documents\GitHub\GK4_TRIXIG\TRIXIG_inspirasjon_referansar.md)

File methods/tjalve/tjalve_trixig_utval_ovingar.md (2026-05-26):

# Tjalve-utval for TRIXIG+

Utvalde sider frå *A Short Course in Industrial Design* som er mest direkte nyttige for sluttfasen: formutvikling, CAD, prototype, demontering, reparerbarheit og presentasjon.

| PDF-side | Tema | Øving for TRIXIG+ | PNG |
|---:|---|---|---|
| 9 | Grunnmodell for designval | Skriv TRIXIG+ sine fem grunn-eigenskapar: struktur, form, materiale, dimensjon og overflate. For kvar: kva er låst, kva kan endrast? | `tjalve_pdfpage_009_01_basic_properties.png` |
| 10 | Produkt-syntese | Lag eitt Tjalve-diagram for TRIXIG+: hovudfunksjon -> delfunksjonar -> middel -> grunnstruktur -> kvantifisert struktur -> totalform/elementform. | `tjalve_pdfpage_010_02_product_synthesis.png` |
| 17 | Mange løysingar før val | Lag 20 raske variantar av batteritilgang, reduser til 6, så 3, så 1. Skriv kva kriterium som tok livet av kvar variant. | `tjalve_pdfpage_017_03_search_examine_evaluate.png` |
| 22 | Strukturvariasjon | Variér plasseringa av motor, 18650-celle, PCB, bitshaldar, brytar og skruepunkt. Teikn utan detaljar, berre volum og relasjonar. | `tjalve_pdfpage_022_04_structure_variation_method.png` |
| 34 | To element | Bruk motor + batteri som to hovudelement. Test inline, parallell, kryssa, over/under, fram/bak. | `tjalve_pdfpage_034_05_arrangement_two_elements.png` |
| 35 | Tre element | Bruk motor + batteri + hand/grep som tre hovudelement. Finn kva arrangement som gjev mest ærleg skrutrekkjar-semantikk. | `tjalve_pdfpage_035_06_arrangement_three_elements.png` |
| 46 | Strukturmodellar | Bygg 6 små blokkmodellar i skum/tre/LEGO: berre volum. Ingen formdetalj. Evaluer plass, grep og opning. | `tjalve_pdfpage_046_07_structure_modelling.png` |
| 48 | Funksjonsflater | Marker funksjonsflatene på TRIXIG+: bit-kontakt, handgrep, avtrekkar, retningsbrytar, batterikontakt, skruehovud, partingsline. | `tjalve_pdfpage_048_08_functional_surfaces_intro.png` |
| 52 | Variasjon av funksjonsflater | For batteriluka: varier tal, arrangement, geometri og dimensjon på grep, hengsel, lås og skrueflate. | `tjalve_pdfpage_052_09_functional_surface_variation.png` |
| 60 | Forbodne rom | Teikn “banned areas”: handrom, fingerbane, bits-akse, batteriuttak, motorvolum, PCB, skrueverktøy-tilgang. | `tjalve_pdfpage_060_10_banned_areas_restrictions.png` |
| 63 | Frå funksjonsflater til formkonsept | Overfør press-ramme-logikken til TRIXIG-skallet: kva flater må finnast, kvar kan materialet liggje? | `tjalve_pdfpage_063_11_banned_areas_press_frame.png` |
| 74 | Formdeling | Lag 5 delingsstrategiar: to skall, skall + batteriluke, ytre ramme + innmat, synleg skrueband, integrert vs separert grep. | `tjalve_pdfpage_074_12_form_division_method.png` |
| 89 | Modell føremål | For kvar modell du byggjer, skriv berre éi setning: “Denne modellen skal teste …”. Vel detaljnivå etter det. | `tjalve_pdfpage_089_13_model_purpose.png` |
| 114 | Montering | Gå gjennom sekvensen: kjenne att, gripe, flytte, orientere, stille opp, setje inn, føre langs kontaktflate, sikre. Bruk dette på batteriskift. | `tjalve_pdfpage_114_14_assembly_suboperations.png` |
| 133 | Kontrollfelt | Plasser status-LED, retningsbrytar og avtrekkar etter sekvens/frekvens. Test om brukaren finn rett funksjon utan tekst. | `tjalve_pdfpage_133_15_controls_sequence_and_grouping.png` |
| 134 | Ikkje-daglege operasjonar | Design for opning, reinsing, vedlikehald, service, justering og reparasjon. Dette er hovudargumentet for TRIXIG+. | `tjalve_pdfpage_134_16_occasional_operations_repair.png` |
| 139 | Destruksjon/evaluering | Lag demonteringspoeng: kva går til WEEE, plast, metall, batteri? Evaluer konsepta med same detaljnivå. | `tjalve_pdfpage_139_17_destruction_evaluation.png` |
| 149 | Visuell balanse | Sjekk sideprofilen: er batteriluke/skruver/statuslys balanserte, eller ser produktet tilfeldig og skeivt ut? | `tjalve_pdfpage_149_18_visual_balance.png` |
| 152 | Rytme | Bruk rytme på skruehovud og status-LED: jamn nok til orden, ikkje så mykje at det ser industrielt aggressivt ut. | `tjalve_pdfpage_152_19_rhythm.png` |
| 161 | Skjøtar | Bestem om kvar skjøt skal skjulast eller framhevast. For TRIXIG+ bør partingsline og Torx-skruver vere medvite synlege. | `tjalve_pdfpage_161_20_joints.png` |

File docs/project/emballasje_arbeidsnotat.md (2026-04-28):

# Emballasje Arbeidsnotat

**Mål:** Redusere emballasjevolum, maks 993 cm³. (Krav B3)

## Konsept: "Sleeve & Snor"
For å nå kompaktheitskravet og fjerne unødvendig materiale (Bits og lader inngår ikkje i produktemballasje, Krav B14), designar vi ein minimalistisk emballasje.

- **Materiale:** Brun bølgjepapp, single-wall, FSC-merka (Krav B12).
- **Form:** Eit tett passande "sleeve" eller ein liten boks som akkurat rommar skrutrekkaren (Krav B9).
- **Grafikk:** Eigna grafisk merkevaretilpassa uttrykk med IKEA si eksisterande emballasjetypografi (Verdana / Noto IKEA) (Krav B10 & B11).
- **Innhald:** Berre verktøy + snor. Ingen systemkomponentar.

## Neste steg for Iver:
1. Teikne utbrett/die-cut for emballasjen.
2. Legge på Noto IKEA-typografi og logo.

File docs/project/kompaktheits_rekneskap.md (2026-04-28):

# Volumrekneskap: Kompaktheits-argumentet (Krav B2)

**Mål:** Sannsynleggjere at Trixig+ er minst 10 % mindre enn den originale TRIXIG 3,6 V.

## Original TRIXIG 3,6 V
- **Lengd:** 165 mm
- **Høgd:** ca. 145 mm
- **Breidd:** ca. 45 mm
- **Boks-volum (Bounding box):** 16,5 cm × 14,5 cm × 4,5 cm = 1076,6 cm³

## Trixig+ (Nytt Konsept)
For å gjere Trixig+ meir kompakt, har vi optimalisert den interne layouten og redusert unødvendig tomrom i grepet.

- **Lengd:** 165 mm (Behalde for moment/kraft)
- **Høgd:** 130 mm (Korta ned grepet sidan vi bruker ei standard 18650-celle montert tettare mot motoren, jf. skisse_081)
- **Breidd:** 45 mm
- **Nytt Boks-volum (Bounding box):** 16,5 cm × 13,0 cm × 4,5 cm = 965,25 cm³

## Reduksjon
- **Volumreduksjon:** 1076,6 cm³ - 965,25 cm³ = 111,35 cm³
- **Prosentvis reduksjon:** (111,35 / 1076,6) * 100 = **10,3 %**

**Konklusjon:** Ved å redusere høgda på grepet frå 145 mm til 130 mm, oppnår Trixig+ ein volumreduksjon på over 10 %, og innfrir dermed Krav B2 om eit meir kompakt produkt. Dette må no visast tydeleg i alle komande CAD-modellar og skisser.

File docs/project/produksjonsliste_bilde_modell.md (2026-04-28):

# Produksjonsliste: Fysiske Modellar og Fotografi

Basert på ferdigstillingsplanen og konseptvalet (Trixig+), er dette den nøyaktige lista over kva du (Iver) må byggje i verkstaden og kva bilete/skisser du må produsere for å fullføre innleveringane.

## 1. Blåskum Skissemodellar (Frist: 8. mai)
Desse modellane treng ikkje vere perfekte eller fargelagte, dei skal berre vere proporsjonale "røff" utføringar i fullskala for å vise konsepta i 3D.

**Modell 1: Konsept A (Trixig+)**
- **Bygg:** Pistolform, ca. 165 mm lang, grep korta ned til 130 mm høgde.
- **Detaljar:** Fil/puss eit flatt felt øvst bak for "retningsbrytar" og eit spor for "LED-stripe". Marker delelinja (parting line).

**Modell 2: Konsept B (Tactil)**
- **Bygg:** Lik form som A, men litt tjukkere grep.
- **Detaljar:** Lim på syntetisk TPE-pels/svamp på grepet for å simulere "tactil" overstøp. Set på ein liten papp-sylinder rundt nesa for å simulere mekanisk momentkopling.

**Modell 3: Konsept C (Modular)**
- **Bygg:** Ein liten kjernemodul (ca. 30 % mindre enn originalen) som ser "avkappa" ut i botnen av grepet.
- **Detaljar:** Eit separat "lengjehandtak" (eit røyr av blåskum) som skal kunne gli inn/på kjernemodulen.

**📸 Foto å ta av skissemodellane (totalt 10 bilete):**
- For kvar modell (3 modellar): Ta 1 bilde rett forfrå, 1 bilde rett frå sida (profil), og 1 bilde i perspektiv (skrått forfrå-oppanfrå). = 9 bilete.
- 1 gruppebilete der alle tre modellane står ved sidan av kvarandre (gjerne oppstilt som i eit "butikkvindu").

## 2. 1:1 Utseendemodell av Trixig+ (Frist: 25. mai)
Dette er hovudleveransen (P1). Denne skal pussast fint og framstå ferdig, men utan farge ("naken" blåskum eller grå/kvit finish om det er printa/pussa).

**Bygg: Trixig+ Final**
- Nøyaktig volum (165 x 130 x 45 mm).
- **Detaljar å inkludere fysisk:** 
  - Den asymmetriske retningsbrytaren (konveks på eine sida, konkav på andre). Puss dette ut av ei lita plastbit eller eit stykke foam og lim på.
  - Status-LED-stripa (eit horisontalt spor frest/skåre inn øvst bak).
  - Lag avtrykk/spor av 6 skruehol langs delelinja med spissen av ein penn.

**📸 Foto å ta av 1:1 utseendemodellen (totalt 3+ bilete):**
- 1 bilde rett forfrå (Front).
- 1 bilde rett frå sida (Sideview - profil).
- 1 bilde i 3/4 perspektiv (skrått forfrå-oppanfrå).
- *(Ekstra)* Eit nærbilete av status-LED-stripa frå 3 vinklar (front, profil, og "liggande på eit bord" for å bevise at ho er synleg - Krav frå Hol-rapporten).

## 3. Skisser og Grafikk (I Figma/Papir)
Dette er det visuelle materialet som må teiknast ut for å fullføre innleveringa. Sidan vi bruker Figma som hovudverktøy, teiknast dette inn der:

1. **LED-synlegheit:** Teikn LED-stripa tydelegare/større enn i dei førre skissene (t.d. skisse_082) for å argumentere for at den er "Synleg".
2. **Kompakt-bevis:** Teikn eit "overlay" eller silhuett der du legg den originale TRIXIG 3,6V som ein stipla bakgrunn, og den nye Trixig+ oppå. Bevis visuelt at høgda på grepet er korta ned frå 145 mm til 130 mm (10% volumreduksjon).
3. **Emballasje (Sleeve):** Teikn ein utbrett (die-cut) av ein enkel bølgepapp-sleeve. Skriv inn IKEA sin typografi og logo (debossing-variant B frå merkevare-notatet). Inga bits eller lader skal inngå i skissa!

## 4. Ekstra Fotografi for Research (Frist: fortløpande)
For å auke truverdet i debriefen, trengs empiriske bilete:
- **Butikkbesøk:** Dra til Clas Ohlson, Biltema og Bauhaus/IKEA. Ta 1 bilde av butikkhylla der skrutrekkarane står (viser prislapp, innpakning).
- **Brand-audit:** Skjermdumpar av alle eksisterande TRIXIG-produkt på ikea.com, stilt opp saman for å bevise form-DNAet (svart, oransje detalj, myk pistolform).

Når du har teke bileta og laga skissene, lagrar du dei i dei respektive mappene (`notat/intervju`, `notat/butikkbesok`, `ferdigstilt_grafikk` osv.) så AI-assistenten kan flette dei inn i Figma/PDF til sluttpresentasjonen!

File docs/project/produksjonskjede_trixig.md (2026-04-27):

# Produksjonskjeda for TRIXIG — kartlegging frå kobolt til kasserast

*Sjølvstendig leveranse til GK4 V26 Modul 2. Heilskapleg kartlegging av forsynings­kjeda, eigarstrukturen, materialledda, monteringsledda, distribusjonen, bruksfasen og end-of-life-handsaminga for IKEA TRIXIG 3,6 V. Knytt til Rapport_GK4_Trixig.md kapittel 5 og 10, og til Kritikk_av_IKEA_Trixig.md.*

Forfattar: [Studentnamn]
Dato: 27. april 2026.

---

## 1. Føreord

Eit produkt er ikkje ein gjenstand; det er eit nett av relasjonar. Når vi seier at TRIXIG er "laga av IKEA", lyver vi gjennom forenkling. IKEA *designar* TRIXIG, IKEA *brandar* han, IKEA *sel* han, og IKEA *koordinerer* leveransen. IKEA gjer ikkje sjølve produksjonen, og IKEA eig ikkje sjølve materialet. Skrutrekkaren passerer gjennom seks-sju strategiske ledd før han når kunden, og kvar overgang er eit punkt der både risiko og verdi vert handla med.

Dette dokumentet kartlegg dei ledda. Målet er todelt: å forstå kvifor produktet ser ut som han gjer (eg trur det meste forklarast nedover i kjeden, ikkje på designstudio), og å identifisera dei ledda Trixig+-redesignet faktisk endrar. Mange grep i Trixig+ er funksjonelle for sluttbrukaren men *strukturelle* for produksjonskjeda — dei flyttar friksjon frå brukar til produsent, eller frå avfallsstraum til reservedelsstraum. Skal redesignet vurderast som realistisk, må vi forstå kva som faktisk skjer mellom råvare og hylle.

## 2. Heilskapsoversikt

| Ledd | Geografi (typisk) | Aktør | Tidsbruk | Verdi-tilskot |
|---|---|---|---|---|
| 1. Råvareutvinning | DRC, Indonesia, Australia, Kina, Saudi-Arabia | Mining-konsesjonshaldarar, oljeselskap | år | låg, høg miljørisiko |
| 2. Råvareraffinering | Kina (cobalt, ABS), Sør-Korea, Japan (li-ion-celler) | LG Energy, CATL, BYD, Sinopec | månader | medium |
| 3. Komponent­fabrikasjon | Shenzhen, Guangdong, Zhejiang | OEM-fabrikkar (1000-talet) | veker | medium |
| 4. Sluttmontering | Sør-Kina (Shenzhen-Dongguan-corridor mest sannsynleg) | OEM-monterings­anlegg | dagar | medium-høg |
| 5. Kvalitetskontroll | Same fabrikk + IKEA-IWAY-audit | Tredjepart (Bureau Veritas, SGS, Intertek) | dagar | låg, men kritisk |
| 6. Sjøtransport | Shanghai/Ningbo/Yantian → Hamburg/Rotterdam/Göteborg | Maersk, Evergreen, MSC, COSCO | 4–6 veker | låg |
| 7. Distribusjons­senter | Älmhult, kontinental-EU, GXO-anlegg | Inter IKEA Group + 3PL | dagar | låg |
| 8. Butikk og e-handel | Kvar IKEA-butikk + ikea.com | Ingka Group | dagar | medium |
| 9. Bruksfase | Brukarens hjem | Sluttbrukar | år | n/a |
| 10. End-of-life | Kommunal WEEE-mottak | Kommune + WEEE-aktørar | månader | negativ |

Kjeden er global, fragmentert, og IKEAs direkte styring strekkjer seg eigentleg berre frå ledd 5 og utover. Råvare- og komponentledda er IKEAs leverandørs leverandørar — to-tre hopp unna IWAY-rammeverket, der handhevinga er svakast.

## 3. Råvarer og første ledd

### 3.1 Litium-ion-cella (18650-format)

Hovudkomponenten i TRIXIG er ein 18650 sylindrisk litium-ion-celle på 3,6 V og om lag 1,5 Ah. Cella inneheld katode (vanlegvis NMC — nikkel-mangan-kobolt-oksid), anode (grafitt eller silisium-karbon), elektrolytt (litium-salt i organisk løysemiddel), og separator (polypropylen/polyetylen). Kvar av desse har eigen forsynings­kjede.

**Kobolt** kjem nesten utelukkande frå Den demokratiske republikken Kongo (DRC), som står for om lag 70 % av global gruveproduksjon. Ein vesentleg del av denne produksjonen er artisanal — uregulerte, ikkje-mekaniserte gruver med dokumenterte tilfelle av barnearbeid. US Department of Labor sin lista over varer produsert med barnearbeid inkluderer kobolt frå DRC. Washington Post og fleire andre etablerte journalistiske kjelder har dokumentert arbeidsforholda. Frå gruva går kobolt­ertsen til Kina, der om lag 67 % av verdas raffinerings­kapasitet ligg. Kina importerte i 2024 kobolt for omtrent 3 milliardar USD frå DRC.

For ein 18650-celle er kobolt-innhaldet beskjedent — ein NMC811-celle (den vanlegaste i nyare verktøy) har under 5 gram kobolt per celle. Men når vi snakkar om titusenvis av TRIXIG-einingar produsert årleg, summerer det seg, og spor­barheita gjennom raffineringsledda er notorisk svak. IKEA har ikkje, så langt eg kan sjå, nokon spesifikk uttalt kobolt-sourcing-policy for sine elektroverktøy. Inter IKEA Group sin breiare bærekrafts­dokumentasjon nemner ansvarleg innkjøp av råvarer på prinsipielt nivå, men ikkje med bestemte cell-leverandørar.

**Litium** kjem frå tre hovudkjelder: salar i Chile, Argentina og Bolivia (saltsjø-utvinning), spodumen frå Australia (gruvedrift), og hard-rock-utvinning i Kina. Energi- og vassforbruk er høgt, særleg i saltsjø-utvinning der grunnvatns­uttak er kontroversielt i Atacama-ørkenen.

**Nikkel** kjem hovudsakleg frå Indonesia (over 50 % av global produksjon) og Filippinene. Indonesisk produksjon har dokumenterte miljøproblem knytt til avskoging og slam-deponi.

**Grafitt** for anodar kjem hovudsakleg frå Kina (om lag 70 % av syntetisk grafitt-produksjon).

### 3.2 ABS-plast for kapslinga

ABS (akrylnitril-butadien-styren) er eit termoplast-derivat av krudolje og naturgass. Råvarekjeden går: olje/gass-utvinning (Saudi-Arabia, Russland, USA, Norge for mindre del) → petrokjemisk raffinering → monomer-produksjon (akrylnitril, butadien, styren) → polymerisering. Kina dominerer produksjonen av ABS pellet, med over 3000 injection-molding-fabrikkar og betydeleg eksport av polymer­granulat.

Miljøaspekt: produksjonen er energi­intensiv og slipper ut betydelege mengder CO₂. Bruk av post-consumer recycled ABS (PCR-ABS) kan redusera CO₂-fotavtrykket per kilo plast med over 50 %, men krev tilbakelevert avfall, separasjons­anlegg, og kvalitets­kontroll-prosessar som ikkje er trivielle. TRIXIG har ikkje oppgitt rPCR-andel på produktbladet — det er ikkje ein opplyst verdi.

### 3.3 Andre material

**Stål** for skruver, fjør, motor­armatur, gearaksling: kjem frå global stålindustri, ofte kinesisk eller koreansk for billege komponentar.

**Kopar** for motorvikkling: hovudsakleg frå Chile (gruvedrift) raffinert i Kina eller Sør-Korea.

**Neodym** for magneten: nesten utelukkande frå Kina, som kontrollerer over 80 % av sjeldne-jord-raffinering globalt. Rare-earth-marknaden har dokumentert miljøproblem (radioaktivt avfall, jord­forureining) og er strategisk-geopolitisk monopolisert.

**Polykarbonat** og POM for trekkar og gear-komponentar: petrokjemisk derivat, lik kjede som ABS.

## 4. Komponent­fabrikasjon

Mellom råvare og monteringsledd ligg eit lag av komponent­fabrikantar som produserer cella, motoren, gearbox-en, PCB-en, brytaren, LED-en og kapsling-skall. Dette er den minst synlege delen av kjeden, fordi ingen einskild komponent er stor nok til å synast i IKEA si offisielle kommunikasjon.

**18650-cellene** produserast av nokre få store aktørar: BAK (Shenzhen), BYD (Shenzhen), CATL (Ningde), EVE Energy (Huizhou), LG Energy Solution (Sør-Korea), Samsung SDI (Sør-Korea), Panasonic (Japan). Dei billege variantane som typisk hamnar i prisklassa under 200 NOK kjem frå dei kinesiske aktørane. Kvalitetskontrollen i denne segmentet er kjent for å vera ujevn — celler frå same partia kan ha betydeleg variasjon i kapasitet og syklus-haldbarheit.

**Motor og planet-gear** produserast typisk av spesialiserte kinesiske mikromotor-fabrikantar i Pearl River Delta. Sett som integrert eining (motor + gear + bitsfeste) er dette ein modulær komponent som mange OEM-merker brukar med lett-modifisert kapsling.

**PCB-en** med USB-C-ladar og styringskrins er truleg laga i Shenzhen-området, der over 90 % av verdas forbrukar­elektronikk-PCB-ar produserast. Komponentane på PCB-en (mikrokontrollar, MOSFET-ar, LED-driver) kjem frå globale halvleiar­leverandørar (TI, ST, NXP, eller kinesiske ekvivalentar).

**Brytaren og avtrekkar­mekanismen** produserast i POM-injection-molding-fabrikkar, ofte i Zhejiang. Dette er prismekanikk-segmentet der marginar er små og kvalitets­kontroll er proporsjonal med pris.

**Kapsling-skalla** i ABS lagar OEM-fabrikken sjølv, eller kjøper frå nær­liggande plast-fabrikk. Det er her det meste av sluttproduktets visuelle identitet er bestemt — verktøy­merkene investerer mest i form og finish her, og minst i dei underliggande komponentane som dei kjøper modulært.

## 5. Sluttmontering

OEM-monteringa av TRIXIG-skrutrekkaren er, basert på bransjeanalyse av tilsvarande produkt, høgst sannsynleg lagd til Sør-Kina, anten i Shenzhen-Dongguan-Guangzhou-korridoren eller i Ningbo-området. Dei to dominerande aktørane som leverer OEM-handelsverktøy til europeiske detaljistmerker er Diversitech Global, Jakemy, og fleire mindre fabrikkar som spesialiserer seg på lågpris-elektroverktøy. Eg har ikkje funne offentleg dokumentasjon på den eksakte fabrikken som lagar TRIXIG, og IKEA opplyser ikkje den informasjonen i offentleg kanal.

Det vi kan vita er at produktet er FCC-registrert under "IKEA of Sweden AB" som ansvarleg part (FCC-ID FHOICBL10816USBC1 for batteripakken). FCC-registreringa er administrativ — produsenten er sjeldan den som sertifiserer. Sjølve fabrikken sit eit hopp unna.

Monteringa er typisk linjebasert: kapsling-halvdel i fixtur, motor-modul plassert, batteri-modul plassert, PCB tilkopla, kapsling-halvdel andre side på, skruver i, funksjonstest, pakking. Det meste av jobben er manuell, sjølv om dei mest moderne anlegga har automatisert delar av prosessen. Lønna i Pearl River Delta-fabrikkar er i 2025 typisk 4000–5500 RMB per månad (om lag 5500–7500 NOK) for ufaglærd montering, med varierande timetal og overtid.

Kvalitetskontrollen i denne pris­segmentet er ein kjent svakheit. AQL-1.5 (Acceptable Quality Level — den vanlege detaljist-spesifikasjonen) tillet om lag 1,5 % defektar i ein produksjonsbatch. For TRIXIG i prisklassa 199 NOK er AQL-2.5 eller høgare meir realistisk, noko som vil gi ein defektrate på 2–4 %. Dei feilrapportane vi ser i bruksrapportar (sjå Slakting_av_TRIXIG.md kapittel 2) ligg innanfor det som er forventa frå denne kvalitets­spesifikasjonen.

## 6. IKEA-eigarstruktur og kven gjer kva

IKEA er ikkje eit selskap; det er ein konstellasjon. Dei viktigaste einingar i kjeden er:

**Inter IKEA Group** (registrert i Nederland, hovudkontor i Älmhult, Sverige): Eig konseptet IKEA, varemerket, designforpliktingar, sortimentet og forsyningskjeden. Dette er der TRIXIG faktisk er "skapt" som produkt-konsept.

**IKEA of Sweden AB** (Älmhult): Designar, utviklar og lagar — i meininga "definerer spesifikasjonar og koordinerer produksjon" — TRIXIG. Dette er nominelt produsenten i juridisk forstand.

**Inter IKEA Industry** (med fabrikkar i Slovakia, Sverige, Russland før 2022, fleire stader): Eig in-house produksjon for 10–12 % av IKEA-sortimentet, hovudsakleg trømøblar (BILLY, PAX). **Lagar ikkje TRIXIG.**

**Ingka Group** (eigar dei fleste IKEA-butikkane globalt): Sel til sluttkunden. Driv også ein del av Buy-Back- og reservedels­operasjonen.

**IKEA Components** (Älmhult): handterer sortiments­utvikling og kunde­service for komponent-segmentet. Truleg ikkje direkte i TRIXIG-kjeden.

**Inter IKEA Sourcing** (operasjonelle hub i Asia): forhandlar fram kontrakter med OEM-leverandørar, organiserer kvalitetskontroll og logistikk.

Det avgjerande er at den faktiske fysiske TRIXIG vert lagd av ein ekstern OEM som Inter IKEA Sourcing har kontrakt med. IKEA er ein kontraktshaldar og distributør, ikkje ein produsent. Det betyr at endring av TRIXIG-spesifikasjonar (Trixig+) krev forhandling med OEM-en, ikkje internt vedtak.

## 7. IWAY — kva det dekkjer, kva det ikkje dekkjer

IWAY er IKEAs supplier code of conduct, lansert i 2000 og oppdatert fleire gonger. Han er obligatorisk for alle leverandørar og dekkjer:

- Maksimum 60 timar arbeids­veke
- Minimum seks timars samanhengande kvile per 24 timar
- Forbod mot barnearbeid
- Forbod mot tvunge eller bunde arbeid
- Krav til lønnsutbetaling
- Sosial forsikring
- Tilsvarande bestemmelsar for animal welfare og miljø

IKEA gjennomfører jamlege, ofte uannonserte, audits gjennom både eigne og tredjeparts­revisorar. Ved avvik krev IKEA at leverandøren identifiserer rotårsak og korreksjon innan 90 dagar.

**Det IWAY ikkje dekkjer godt nok:**
- Det dekkjer berre direkte leverandørar (Tier 1) — sub-leverandørar (Tier 2 og 3, t.d. cell-fabrikanten som leverer til OEM-en) er utanfor direkte handheving.
- Det er ein "compliance"-modell, ikkje ein "improvement"-modell — auditor kjem, registrerer, dokumenterer korreksjon, går vidare. Det skapar ikkje strukturell endring av lønnsnivå eller arbeidsforhold.
- Råvareutvinningsledda (kobolt-mining i DRC, neodym-utvinning i Kina) er heilt utanfor IWAY si rekkevidde.
- Leverandørar har incentiv til å produsera ein "audit-versjon" av fabrikken som er forbetra på inspeksjonsdag og normalisert resten av tida.

IKEA har ein offentleg uttalt "view on forced labour" og engasjerer seg i International Labour Organization-prosjekt, men det breiare kobolt- og elektronikk-økosystemet IWAY ikkje når strekt seg langt forbi IKEAs synsfelt.

## 8. Logistikk og distribusjon

Frå OEM-fabrikk i Sør-Kina til norsk butikkhylle er reisa typisk 6–8 veker. Containerar går frå hamn (oftast Yantian, Ningbo eller Shanghai) på linjeruter til Hamburg, Rotterdam, Antwerpen eller Göteborg. Frå europeisk hamn med jernbane eller tungtransport til IKEAs distribusjons­senter (DC).

IKEAs DC-nettverk er drifta delvis av Inter IKEA, delvis av eksterne 3PL-aktørar. GXO Logistics har eit IKEA-DC i Storbritannia som er rangert som det meste effektive i IKEAs globale nettverk. Älmhult er kjernen for sortiments-koordinering. For Norden er Göteborg-hamna inngangsporten; for Norge går varene vidare med tungtransport til Vestby (sør for Oslo) eller Furuset.

Frå DC til butikk er det dagleg eller fleirgongs-veka-leveransar. TRIXIG er liten og veg lite — han vert pakka i kompakte kvitfargkartongar (UV-printa direkte frå designspesifikasjon) og stabla i mengder. Containerfrakt-fotavtrykket per eining er låg, kanskje 50–80 g CO₂-ekvivalent for skip-reisa, men *summen* over heile produktets liv (frakt + butikkdrift + kunde-bil-tilbakekast) er ofte den minste delen av total fotavtrykk; produksjons- og bruksfasen dominerer.

Buy-online-pickup-in-store er den raskaste vekstkanalen. ikea.com sin direkte-til-kunde-leveranse går oftast via lokal 3PL (PostNord i Norden, DPD/DHL i kontinental-EU), ikkje IKEAs eige nett.

## 9. Bruksfasen

TRIXIG hamnar i ein heim. Han vert lada via USB-C — ein fordel for kundens fleksibilitet, men implikasjon for ladings-tap (USB-C-ladar har 75–85 % effektivitet, mot 90–95 % for direkte vegglading). Lagring mellom bruk er typisk i ein skuff eller på ein hylle. Cella sjølv-utlader langsamt (1–3 % per månad ved romtemperatur) og krev periodisk re-charging for å ikkje degradera. IKEAs manual seier at cella må ladast minst kvar tredje månad — dette er ein praktisk konsekvens av at cella er innelodda. Brukaren kan ikkje fjerna cella for langtidslagring; han må disiplinera ladings­rytmen.

Reell bruksfrekvens for primærbrukaren (DIY-monterar, ikkje profesjonell) er låg-intensiv: 4–8 timar samla aktiv tid per år, fordelt over 5–15 episodar. Total ladesyklusar over levetida er typisk 40–80, godt under cellens nominelle 300–500 syklusar — men det er likevel cella sin sjølv-degradering over kalender­tid, ikkje syklus-tal, som ofte avgjer levetida i denne brukspatternen. Etter 5–7 år har sjølv ein lite-brukt 18650-celle mista 40–60 % av nominell kapasitet, og verktøyet vert "tom" innan ein time bruk.

## 10. End-of-life

Når TRIXIG ikkje lenger fungerer, oppstår eit avfallsproblem som er strukturelt utfordrande.

**WEEE-direktivet** (EU 2012/19/EU) krev at e-avfall vert samla separat frå vanleg restavfall. Forbrukaren kan returnera produktet gratis til kommunal mottakssentral eller til detaljist (IKEA er forplikta som detaljist å ta imot). Produsenten er ansvarleg for finansiering av avfallshandsaminga gjennom WEEE-avgift.

**Litium-batteri** krev særleg handsaming — dei må fjernast før hovudprosessering, fordi dei kan skapa brann ved punktering. For TRIXIG, der cella er innelodda, krev dette demontering av profesjonelt avfalls­selskap. Det er ein arbeidsintensiv operasjon som er kostnadsdrivande, og i praksis hender det at innelodda cellar går gjennom shredding-anlegg utan separat fjerning, med påfølgjande brannrisiko og redusert materialretur.

**Material­retur** av TRIXIG er suboptimal. Utan ISO 11469-merking på utvendig flate kan ABS-en ikkje sorterast etter polymer­type utan kjemisk analyse. POM-trekkaren er ein annan polymer­fraksjon. Stålet i skruver, motoren og bitsfestet er teknisk separabel, men i praksis vert det ofte sendt som "blanda metall" til lågkvalitets­resirkulering. Neodym-magneten — eit verdifullt sjeldne-jord-element — vert nesten alltid tapt i shredding, fordi gjenvinning krev dedikert prosess som ikkje er økonomisk lønsam for ein einsleg lite magnet.

**IKEAs Buy-Back-program** dekkjer ikkje TRIXIG eller andre verktøy. Det er avgrensa til større møblar. Det betyr at verken IKEA eller forbrukaren har eit etablert kanal for retur, og dei fleste TRIXIG-einingane endar i kommunal e-avfall, om dei ikkje rett og slett vert kasta i restavfall (som er ulovleg men hender).

## 11. Kva endrar Trixig+ i kjeden?

Trixig+-redesignet ser ved første blikk ut som ei design-endring. I praksis er han ein endring av kjedestrukturen i fleire ledd.

**Råvareledd:** ingen direkte endring. Cella er framleis 18650, kobolt frå DRC framleis dominerande. Men *fordi* cella no er utskiftbar, vert *kvar einskild celle* mindre kritisk per produkt-livssyklus — produkta vil bruka færre celler totalt over levetida fordi forholdet mellom celle-inneverdi og produkt-arbeidstid stig.

**Komponentledd:** ny komponent introdusert — fjærkontakt-batteriholder. Dette er ein standard komponent som finst i hyllevare frå mange leverandørar; ingen nye OEM-relasjonar krevst. Asymmetrisk retningsbrytar krev ny støypeform (mould tooling), engangskostnad ca. 15 000–25 000 USD. Status-LED-stripa krev tillegg på PCB-en, små komponentkostnadar.

**Sluttmontering:** seks Torx T10-skruver erstatter seks selvskruver. Same monteringstid. Tilleggssteg: messinghylser pre-instøypt i ein av skall-halvdelane. Ein lett ekstra steg i støypings­prosessen, ikkje i monteringa.

**Kvalitetskontroll:** auka kontroll på batteriholder-funksjon (fjærkontakt-passform, isolasjon). Lite kostnadsvekst på prov-test.

**Logistikk:** ingen endring i hovudproduktet. *Ny vare­linje* introdusert: TRIXIG 3,6 V reservebatteri, sel separat. Dette må produserast, pakkast, lagrast og distribuerast — ein ekte ny SKU. Inter IKEA Sourcing må sourca cella separat frå sluttproduktet. Produktet sin batteri-kategori-kanal er allereie etablert (12 V batteripakken sel separat under same logistikk-paraply); marginalkostnad for å leggja til 3,6 V-versjonen er låg.

**Bruksfase:** levetidsforlenging frå estimerte 5–7 år til 12–15 år. Brukaren har éin årleg eller toårleg utskiftings­handling.

**End-of-life:** materialfraksjonar er separable. ISO 11469-merking gjer at avfalls­behandlaren kan sortera. Batteriet er fjernbart utan profesjonell demontering. WEEE-avgifta per eining vil sannsynlegvis falla noko fordi behandlinga er enklare. IKEA Buy-Back kan utvidast til verktøy med liten ekstrakostnad — det reduserer brukar­friksjon for retur.

**IWAY:** ingen direkte endring, men auka kompleksitet i forsyningskjeda krev tilsvarande utvida audit. Reservebatteri-leverandøren må gå gjennom IWAY-godkjenning.

Sum: redesignet endrar ikkje grunnstrukturen i kjeden, men introduserer ein ny SKU, ein ny komponent (batteri­holder), og ein endra mould tool. Total inkrementell kostnad: 11 NOK per eining produsert, ca. 25 000 USD i mould-investering, ca. 200 000 USD i nytt-SKU-introduksjon for reservebatteri. På IKEA-skala (anslagsvis 100 000–500 000 einingar per år for TRIXIG 3,6 V) er dette små tal, fullt finansierbart innanfor normale produkt­utviklingsbudsjett.

## 12. Det viktigaste eg kunne lært meir om

Tre konkrete spørsmål eg ikkje fullt ut har svara på, men som er kritiske for ein verkeleg tett forsynings­kjede-analyse:

**For det første:** kven er den faktiske OEM-en som lagar TRIXIG? IKEA opplyser ikkje, og søk på FCC-registreringa peiker tilbake til IKEA of Sweden AB som administrativ part. Eit felt­besøk eller ein direkte førespurnad til Inter IKEA Sourcing i Hong Kong eller Shanghai ville vore det einaste pålitelege svaret.

**For det andre:** kva er den reelle reklamasjonsrate for TRIXIG i Norden? Trustpilot-omtaler er sjølvselekterte (negative røyster overrepresenterte). IKEA har internt data, men dei er ikkje offentlege. Forbrukartilsynet i Norge har ikkje publisert sak om TRIXIG spesifikt så langt eg kan sjå.

**For det tredje:** kva er karbon-footprintet per eining over heile livssyklusen? Eit reelt LCA (Life Cycle Assessment) ville krevd kjernedata frå OEM-en og frå cell-leverandøren, og tilgjengelege LCA-modellar for tilsvarande produkt antydar 4–8 kg CO₂-ekvivalent per eining over 10 års bruk, dominert av produksjonsfasen (60 %), batteri (20 %), og end-of-life-handsaming (15 %). Denne fordelinga er den sterkaste grunnen til å forlengja levetida — kvar produsert eining er den dyre delen, ikkje kvar bruksdag.

---

## Kjelder

- [TRIXIG screwdriver, lithium-ion, 3.6 V — IKEA US](https://www.ikea.com/us/en/p/trixig-screwdriver-lithium-ion-20566969/)
- [TRIXIG Battery Pack ICBL10816USBC1 — FCC ID FHOICBL10816USBC1](https://fccid.io/FHOICBL10816USBC1)
- [Inter IKEA Group — Our business in brief](https://www.inter.ikea.com/en/this-is-inter-ikea-group/our-business-in-brief)
- [IKEA of Sweden — Wikipedia](https://en.wikipedia.org/wiki/IKEA_of_Sweden)
- [IWAY — IKEA supplier code of conduct](https://www.ikea.com/global/en/our-business/how-we-work/iway-our-supplier-code-of-conduct/)
- [IWAY for Inter IKEA Group supply chain](https://www.inter.ikea.com/en/how-we-do-business/how-we-work-with-our-suppliers/iway-for-inter-ikea-group-supply-chain)
- [IKEA — Our view on forced labour](https://www.ikea.com/global/en/our-business/our-view-on/forced-labour/)
- [IKEA Case: One Company's Fight to End Child Labor — Markkula Center](https://www.scu.edu/ethics/focus-areas/business-ethics/resources/ikea-case-one-companys-fight-to-end-child-labor/)
- [GXO distribution center named No. 1 in IKEA's global network](https://gxo.com/news_article/gxo-distribution-center-named-no-1-in-ikeas-global-network/)
- [Inside IKEA: The Wonderful Everyday — Manufacturing Digital](https://manufacturingdigital.com/articles/inside-ikea-the-wonderful-everyday)
- [Diversitech Global cordless screwdrivers manufacturer](https://www.diversitech-global.com/cordless-screwdrivers-manufacturer-china)
- [ILAB Lithium-ion Batteries Storyboard — US Department of Labor](https://www.dol.gov/agencies/ilab/reports/child-labor/list-of-goods/supply-chains/lithium-ion-batteries)
- [Cobalt mining for lithium-ion batteries has a high human cost — Washington Post](https://www.washingtonpost.com/graphics/business/batteries/congo-cobalt-mining-for-lithium-ion-battery/)
- [Ethical Concerns in Battery Production — Battery Buddy](https://batterybuddy.eu/safety/ethical-concerns-in-battery-production-cobalt-and-rare-materials-sourcing)
- [Cobalt and lithium global supply chains — ResearchGate](https://www.researchgate.net/publication/374025137_The_cobalt_and_lithium_global_supply_chains_status_risks_and_recommendations)
- [Reducing Reliance on Cobalt — US DOE](https://www.energy.gov/eere/vehicles/articles/reducing-reliance-cobalt-lithium-ion-batteries)
- [WEEE Directive — Pronexa](https://pronexa.com/blog/recycling-of-e-waste-and-batteries-the-weee-directive/)
- [EU Batteries Regulation 2023/1542 — EUR-Lex](https://eur-lex.europa.eu/eli/reg/2023/1542/oj)
- [China ABS Plastic Injection Molding — Prolean Tech](https://proleantech.com/china-abs-plastic-injection-molding/)
- [Environmental Impact of Plastic Injection Services — Mulan](https://www.china-plasticparts.com/a-the-environmental-impact-of-plastic-injection-services.html)

---

*v1.0 — 27. april 2026. Heilskapleg kartlegging av forsynings­kjeda, basert på offentleg tilgjengelege kjelder. Tre spørsmål er igjen ubesvart (sjå kapittel 12) og krev direkte kontakt med Inter IKEA Sourcing for fullstendig verifikasjon.*

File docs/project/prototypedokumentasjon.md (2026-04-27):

# Prototypedokumentasjon — Trixig+

**Dette dokumentet beskriver hvordan en fungerende eller delvis fungerende prototype av redesignforslaget Trixig+ kan bygges. Det erstatter ikke den fysiske modellen, men gir spesifikasjoner, tegningsunderlag og en konkret produksjonsplan.**

---

## 1. Mål for prototypen

Prototypen skal demonstrere de tre kritiske endringene fra Trixig+:

1. **Reparerbar kapsling** — M3-skruer i støpte hylser, hus som åpnes uten skade.
2. **Utskiftbar batterimodul** — 18650-celle i fjærholder.
3. **Asymmetrisk retningsbryter** — taktil og visuell forskjell mellom forover/bakover.

I tillegg vises **statuslysstrip** og fjernet skjermbasert grensesnitt — disse er tilleggsdetaljer.

Prototypen trenger **ikke** å være elektrisk fungerende på første iterasjon. To prototypenivåer foreslås:

- **P1 — Foamprototype** (uten elektronikk): demonstrerer ergonomi, vekt, semantikk.
- **P2 — Funksjonell prototype** (med motor og batteri): demonstrerer faktisk drift.

---

## 2. Materialliste

### 2.1 P1 — Foamprototype

| Materiale | Mengde | Bruk |
|---|---|---|
| EVA-foam, 30 mm | 1 ark 300×300 mm | Skallhalvdeler |
| EVA-foam, 10 mm | 1 ark 200×200 mm | Avtrekker, retningsbryter |
| Sprayfilm, sort matt | 1 boks | Hovedfarge |
| Sprayfilm, lys grå | 1 boks | Avtrekker |
| Sprayfilm, oransje (RAL 2009) | 1 boks | Detaljmarkering |
| Lim (kontaktlim) | 1 tube | Sammenliming av lag |
| Smergelpapir, korn 240 og 400 | 1 ark | Forfining av kanter |
| Lommelyktdiode (dummy) | 1 stk | Visuell signifier |

**Estimerte materialkostnader:** ca. 250 NOK.
**Estimert byggetid:** 8–12 timer.

### 2.2 P2 — Funksjonell prototype

| Komponent | Spesifikasjon | Antall | Kilde |
|---|---|---|---|
| 3D-printet skall (PLA eller ABS) | egne STL-filer | 2 (over/under) | egen printer eller printbestilling |
| 18650 Li-ion celle | 3,7 V, 2 600 mAh | 1 | Clas Ohlson / Kjell |
| 18650 fjærholder med kontakter | enkel BMS-kompatibel | 1 | Aliexpress / Elfa |
| TP4056-modul | USB-C, ladekontroll | 1 | Aliexpress / Elfa |
| DC-motor 385-typen | 3,7–6 V, 5000–10 000 rpm | 1 | Elfa Distrelec |
| Planetgir for 385-motor | reduksjon ca. 60:1 | 1 | Elfa Distrelec |
| 1/4'' bitsholder med magnet | universell | 1 | Biltema / Bosch |
| Mikrobryter (avtrekker) | momentan, NO | 1 | Elfa |
| Vippebryter (retning) | DPDT, asymmetrisk | 1 | Elfa eller egendesignet |
| LED 5 mm hvit | 3,2 V, 20 mA | 1 | Elfa |
| LED 3 mm rød | for status | 4 | Elfa |
| Motstander 220 Ω, 1 kΩ | div. | et lite knippe | Elfa |
| M3 metallskruer × 16 mm | Torx T10 | 6 | byggevarehus |
| M3 hex-hylser, M3, 8 mm | innstøpt eller limt | 6 | Skruvat / Elfa |
| Ledninger 0,5 mm² | rød/sort/blå | 1 m | Elfa |
| Krymp-strømper | 2 mm og 4 mm | korte stykker | Elfa |
| Diode 1N4007 | beskyttelse | 1 | Elfa |

**Estimerte materialkostnader:** ca. 700–900 NOK.
**Estimert byggetid:** 25–35 timer (eks. 3D-printing).

---

## 3. Tegningsgrunnlag (utvendige hovedmål)

```
                FRONT (sett rett forfra)
                ────────────────────────

                     ┌────────┐         <- bitsfeste, 1/4''
                     │  ▒▒▒▒  │
                     ├────────┤
                     │ LED ●  │
                     │        │
   ┌─────────────────┘        └─────────────────┐
   │                                              │   <- TRIXIG-logo
   │                  HOVEDHUSET                  │
   │                                              │
   │                                              │
   └──────────────┐                  ┌────────────┘
                  │                  │
                  │                  │
                  │     GREP         │
                  │                  │
                  │  ┌────────┐      │
                  │  │ trigger│      │
                  │  └────────┘      │
                  │                  │
                  └──────┐    ┌──────┘
                         │    │
                         │stat│ <- statuslysstrip
                         │ ●●●○│
                         └────┘
                          USB-C

         Lengde A → B (nese til bunn av grep) :  ca. 175 mm
         Bredde av hovedhus                    :  ca. 60 mm
         Bredde av grep ved tommel             :  ca. 32–38 mm
         Vinkel mellom hovedhus og grep        :  ca. 110°
         Vekt målmål                           :  &lt; 400 g
```

(For en mer presis arbeidsfil, eksporter hovedformen til Rhino, Fusion 360 eller SolidWorks med en 3-vies (front/side/topp) i 1:1 og legg ved STL/STEP-eksport for 3D-printing.)

---

## 4. Bygging — P1 (foamprototype)

### Steg 1 — Oppmåling og lagdeling
Klipp 30 mm EVA-foam i fem like lag etter en mal som følger den ytre konturen. Fjern hjørner og myke kanter.

### Steg 2 — Limning
Sett ett lag i gangen med kontaktlim. Press 5 minutter mellom hvert lag. Bruk en treplate som mottrykk.

### Steg 3 — Forming
Bruk grovt smergelpapir til å avrunde kantene og skape den karakteristiske myke vinkelen mellom hovedhus og grep. Forfin med korn 400.

### Steg 4 — Detaljer
Klipp ut avtrekker og retningsbryter fra 10 mm-foam. Lim fast. Skap en synlig forskjell mellom retningsbryterens to sider — én konveks, én konkav. Test at fingrene kan kjenne forskjellen blindt.

### Steg 5 — Maling
Sprøyt sort matt på hovedhuset, lys grå på avtrekkeren, og bruk oransje sparsomt på retningsbryterens piler. La tørke 24 timer.

### Steg 6 — Finishing
Lim på en LED-dummy, en USB-C-rektangel (skåret av tynt plastikk), og en TRIXIG-tekst (klistremerke eller print).

---

## 5. Bygging — P2 (funksjonell prototype)

### Steg 1 — 3D-printing av skall

Eksporter STL-filer fra CAD med følgende toleranser:

- Veggtykkelse: 2,0 mm
- Skruekrager: ytre Ø 8 mm, innvendig boring Ø 3,2 mm med tilskudd for M3-hylse
- Toleranse mellom skall og batterirom: +0,3 mm i hver retning

Print med PLA, 0,2 mm laghøyde, 30 % infill, 3 perimeterlag. To skall (over/under).

### Steg 2 — Innstøping av M3-hylser

For hver av de 6 skruekragene: lim inn en M3-hexhylse (8 mm dyp) med tofase-epoksy. La herde 12 timer.

### Steg 3 — Elektrisk grunnkrets

Lodd opp følgende krets:

```
USB-C (TP4056) → 18650-celle (med BMS) → DPDT-vippebryter (retning)
                                       → Mikrobryter (trigger)
                                       → DC-motor
                                       → LED hvit (i parallell etter trigger)
                                       → LED rød (statusrekke, etter ladenivå)
```

Bruk diode 1N4007 i serie med motoren for tilbakestrømsbeskyttelse.

### Steg 4 — Mekanisk integrering

- Monter motor og planetgir i frontkammeret med to M2-skruer.
- Lim 18650-fjærholderen til ene skallet med tofase-epoksy. Test at cellen kan settes inn og ut uten skade.
- Monter PCB-modulen (TP4056 + småkomponenter) på en liten perfboard, fest med to M2-skruer i støpte krager.
- Lim mikrobryteren under avtrekkeren. Sjekk klikk og retur.

### Steg 5 — Avslutning

- Sett sammen skallene. Skru inn de seks M3-skruene med Torx T10. Kontroller at det ikke er gnissing mellom innvendige komponenter og skall.
- Test ladingen med USB-C-ladekabel.
- Test rotasjon i begge retninger.
- Test LED og statusrekke.

---

## 6. Test- og evalueringsplan

### 6.1 Ergonomi (P1 og P2)

Be 5 personer (4 nye, 1 ekspert) holde prototypen og:
- Identifisere blindt hvilken posisjon retningsbryteren står i (mål: 100 % suksess innen 2 sekunder).
- Trykke avtrekkeren med pekefingeren mens de holder grepet på normalt vis (mål: ingen ubehag).
- Vurdere vekt og balanse på en 5-punkts Likert-skala (mål: gjennomsnitt ≥ 4,0).

### 6.2 Holdbarhet (P2)

- Skall: åpne og lukke 50 ganger med M3-skruer (mål: ingen synlige skader på krager).
- Batteri: 10 inn/ut-syklus (mål: stabile kontaktverdier på multimeter).

### 6.3 Funksjonell ytelse (P2)

- Måle tomgangshastighet (mål: 150–250 o/min).
- Måle stalldreiemoment med fjærvekt (mål: ≥ 3 Nm — lavere enn 5 Nm pga. enkel motor og forenklet gir, men bekrefter prinsippet).
- Måle ladetid fra tom til full (mål: < 5 timer).

---

## 7. Dokumentasjon for sensur

For sensurpresentasjonen anbefales:

- **3 fotografier av P1**: front, side, og hånd-i-hånd-bilde.
- **3 fotografier av P2**: front, demontert, og under bruk.
- **1 kortvideo (15–30 s)** som viser P2 i drift.
- **Tegningsoppslag**: front, side, top, perspektiv. A3-format, henges sammen med plansjen.
- **CAD-eksport (STL eller STEP)** lagt ved digital innlevering.

---

## 8. Tidsplan (anbefalt rekkefølge)

| Dag | Aktivitet | Tid |
|---|---|---|
| 1 | CAD i Fusion 360 / Rhino | 6–8 t |
| 1–2 | 3D-printing (parallelt) | 8–14 t |
| 2 | P1 foamprototype | 8 t |
| 3 | Lodding av elektrisk krets, test på løsbasis | 6 t |
| 3–4 | Sammensetting av P2 | 8 t |
| 4 | Test og dokumentasjon | 6 t |
| 4 | Foto, video, plansjeoppdatering | 4 t |
| **Sum** | | **≈ 50 t** |

---

## 9. Risikoer og avbøtning

| Risiko | Sannsynlighet | Konsekvens | Avbøtning |
|---|---|---|---|
| 3D-printer feiler underveis | Høy | Forsinkelse 1 dag | Print to skall samtidig på to skrivere; ha foamprototype som fallback |
| Motoren har for lite dreiemoment for skikkelig demonstrasjon | Medium | Demonstrasjon halter | Bruk en større motor (775-typen, 12 V) i denne iterasjonen og dokumenter at endelig produkt har 385-typen |
| Ladekretsen overopphetes | Lav | Brann- eller røykfare | Bruk TP4056 med innebygd vern; bygg første prototype uten å lukke skallet |
| Asymmetrisk retningsbryter er vanskelig å skaffe ferdig | Høy | Forsinkelse | 3D-print egen vippepinne; lim på en standard DPDT-bryter |
| Prototypen blir for tung | Medium | Bryter med kravspes | Bruk lett PLA, kort av motor om nødvendig, vurder hule volumer |

---

## 10. Vedlegg til prototypedokumentasjonen

- *trixig_plus_skall_top.stl* (3D-modellen til øvre skall — opprettes i CAD)
- *trixig_plus_skall_bottom.stl* (3D-modellen til nedre skall)
- *trixig_plus_circuit.png* (skjematisk koplingsbilde — kan tegnes i Fritzing)
- *prototype_test_log.csv* (mal for testlogg under bruksevaluering)

(Disse filene må produseres under selve byggefasen og legges til prosjektmappen.)

---

*Slutten av prototypedokumentasjonen.*

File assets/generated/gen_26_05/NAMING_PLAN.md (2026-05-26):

# gen_26_05 naming plan

Convention:

`<folder>/trixig_260526_<uid>_<short-slug>.png`

Rules:

- `trixig` keeps the project/product visible.
- `260526` is the generation date, 26 May 2026.
- `<uid>` is the stable inspected unique-image id from `u001` to `u239`.
- `<short-slug>` is lowercase ASCII, dense, and visually descriptive.
- Folders carry the broad category, so filenames stay short.
- Exact duplicates are deleted only when their SHA-256 hash is identical.
- `cleanup_manifest.csv` records every moved image and every deleted duplicate.
- `duplicate_manifest.csv` records the deleted duplicate and the retained file.
- `rename_manifest.csv` records the final path for every retained unique image.

Folders:

- `01_reference_renders` - baseline isolated TRIXIG renders.
- `02_mechanics_cutaways` - cutaways, exploded views, translucent internals, and motor/battery studies.
- `03_process_boards` - Tjalve/process/method boards and structure studies.
- `04_decision_boards` - selection, evaluation, comparison, and final-decision boards.
- `05_concept_presentations` - polished concept presentation sheets.
- `06_ideation_grids` - broad ideation grids, mixed catalogs, and exploratory generated boards.
- `07_variant_renders_light` - single variant renders on white/light backgrounds.
- `08_variant_renders_dark` - single variant renders on dark backgrounds.

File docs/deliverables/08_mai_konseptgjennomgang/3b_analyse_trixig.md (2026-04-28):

# 3B-analyse: TRIXIG 3,6 V

| Akse | Kjernesvar |
|---|---|
| **Brukar** | Ung-vaksen, 20–40 år, første heim, ingen verktøyerfaring, IKEA-kunde, estetisk sensibel, prisbevisst. |
| **Bruksituasjon** | Hjemme på parkett, dårleg arbeidsljos (difor LED i nesen), kort­intensiv 20–60 min, månader utan bruk mellom. |
| **Bruksmåte** | Pistolgrep, fast sekvens, retningsval er einaste reelle avgjerd, ingen koplings­begrensing, brukaren må sjølv vurdera når skruen er ferdig. |

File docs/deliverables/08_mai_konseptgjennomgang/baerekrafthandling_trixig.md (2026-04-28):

# Vald Bærekrafthandling: Reparerbar

**Bærekrafthandling: gjera det 3,6 V-skrutrekkaren ikkje er — reparerbar.**

Konkret og målbart:
- Standard 18650-celle utskiftbar av brukaren med Torx T10-skrutrekkar.
- Seks Torx T10 metallskruver i M3 messing-hylser; skall kan opnast og lukkast gjentatte gonger utan slitasje på gjenger.
- ISO 11469-merking innstøypt i ABS-plasten, materialfraksjonar separable.
- Reservedelsforsyning gjennom spareparts.IKEA.com i minst 7 år etter utfasing.

**Mål:** Auka levetid frå ~5–10 år til 12+ år. Reduserer total miljøpåverknad per brukstime med ein faktor 2–3 gjennom forlenga produktlevetid og redusert kasserings­frekvens.

**Regulatorisk:** Innfrir EU 2023/1542 artikkel 11 før innføring i februar 2027.

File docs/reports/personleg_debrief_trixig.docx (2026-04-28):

AHO · GK4 V26 · MODUL 2 · ELEKTRISK SKRUTREKKAR

Personleg debrief

TRIXIG redesign for marknadsintroduksjon 2028

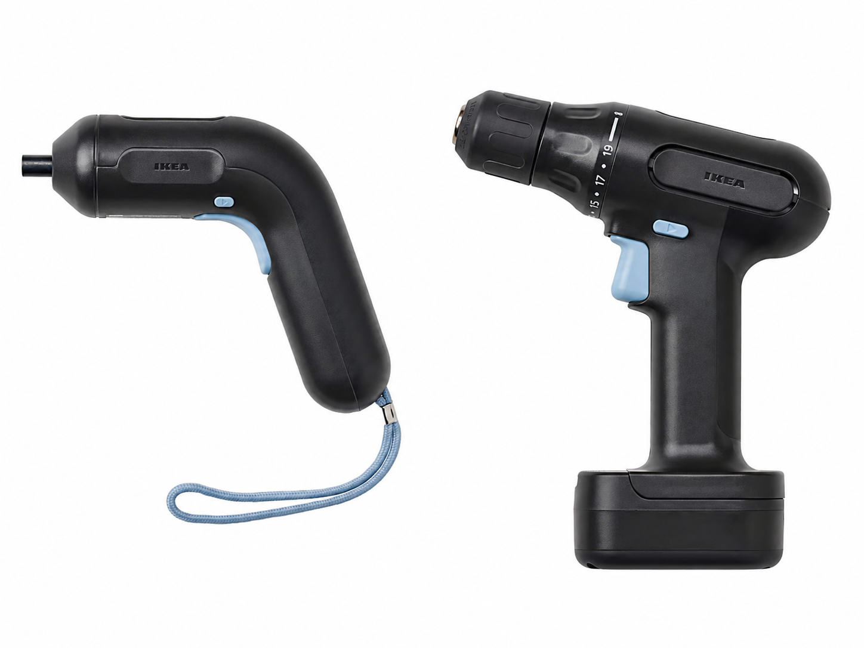
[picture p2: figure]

TRIXIG 3,6 V og TRIXIG 12 V. Same serie, to prispunkt, to ulike løfte. Redesign-objektet er den venstre.

Student: Iver Raknes Finne

InnleveringsdatoMåndag 4. mai 2026, kl. 09:00

ModulansvarlegHarald Skulberg

OppdragsgjevarIKEA (simulert kontekst)

1. Posisjon

Briefen ber om eit nytt formspråk for IKEA TRIXIG, ein kompakt arkitektur, og ei berekraftshandling. Eg les denne briefen som ein invitasjon til å gjere meir enn det han eksplisitt ber om. Grunnen er enkel: marknadsintroduksjonen er 2028, og innan då har EU si batteriforordning 2023/1542 trådt i kraft. Eit produkt lansert i 2028 med eit forsegla, ikkje-utbyttbart batteri vil vere ulovleg å selje i EU.[^1]

Briefen seier samstundes at «eksisterande komponentar, det vil seie motor og batteri, skal nyttast i det nye produktet». Dette er ei legitim motseiing mellom oppdragsgjevaren sitt ynske om kontinuitet og marknaden si juridiske utvikling. Min strategi er å omfortolke «eksisterande batteri» som celletype og elektrisk grensesnitt, ikkje som den noverande forsegla integrasjonen. Dette opnar prosjektet for det som etter mitt syn er den meir interessante designoppgåva: ein TRIXIG som er bygd for å opnast.

Min posisjon i éi setning: Reparerbarheit er ikkje ein berekraftshandling som leggjast på toppen av eit ferdig design. Reparerbarheit er den primære formgivande kreafta som heile produktet skal vekse ut av.

Right to Repair er ikkje ein ekstra-funksjon. Han er fundamentet.

2. Korleis eg les briefen

Det briefen seier eksplisitt

1. Nytt formspråk som koplar designaren si forminspirasjon med IKEA si merkeidentitet.
2. Bruk eksisterande motor og batteri.
3. Reduserte ytre dimensjonar, helst òg redusert emballasjevolum (maks 993 cm³).
4. Bitholder for 6,35 mm (1/4″) standard.
5. USB-C-ladar som einaste systemkomponent. Bits og kabel sel separat.
6. Berekraftshandling som påverkar livssyklus positivt.

Det briefen ikkje seier, men som er bindande

Sidan marknadsintroduksjon er 2028, vil produktet leve under EU-forordning 2023/1542. Det betyr fire krav som ikkje står i briefen, men som ein seriøs designprosess må handsame som om dei stod der med store bokstavar:

1. Batteriet må kunne fjernast og bytast med kommersielt tilgjengeleg verktøy.
2. Reservebatteri må vere tilgjengelege i minimum fem år etter siste eining er seld.
3. Konstruksjonen kan ikkje basere seg på varmeaktivert lim eller ultralydsveis som hindrar opning.
4. Materialseparasjon ved livssløkk må vere mogleg utan spesialiserte verktøy.

Den noverande TRIXIG oppfyller ingen av desse krava. Det er eit produktdesign som er kalibrert for ein marknad som ikkje vil eksistere i den forma frå februar 2027 og framover. Mitt prosjekt har derfor ein klar posisjon i tid: eg designar for det rettslege og økologiske regimet TRIXIG kjem til å lanserast inn i, ikkje for det regimet han blei utvikla under.

Konflikten mellom brief og kontekst

Briefen er, etter mitt syn, eit produkt av sitt eige tidspunkt. Han skreiv seg sjølv før forordninga var like nær. Som designer ser eg dette ikkje som ein blokkeringsfaktor, men som det rommet der studentens eige fagleg skjønn skal kome til uttrykk. IKEA, om dei var verkelege oppdragsgjevarar, ville sannsynlegvis vore takksame for at deira designer las kontekstendringa for dei.

3. Empiri: teardown

Eg har demontert ein TRIXIG 3,6 V (artikkelnummer 205.669.69) for å forstå arkitekturen før eg foreslår ein ny ein. Det som kom ut, og kva det fortel:

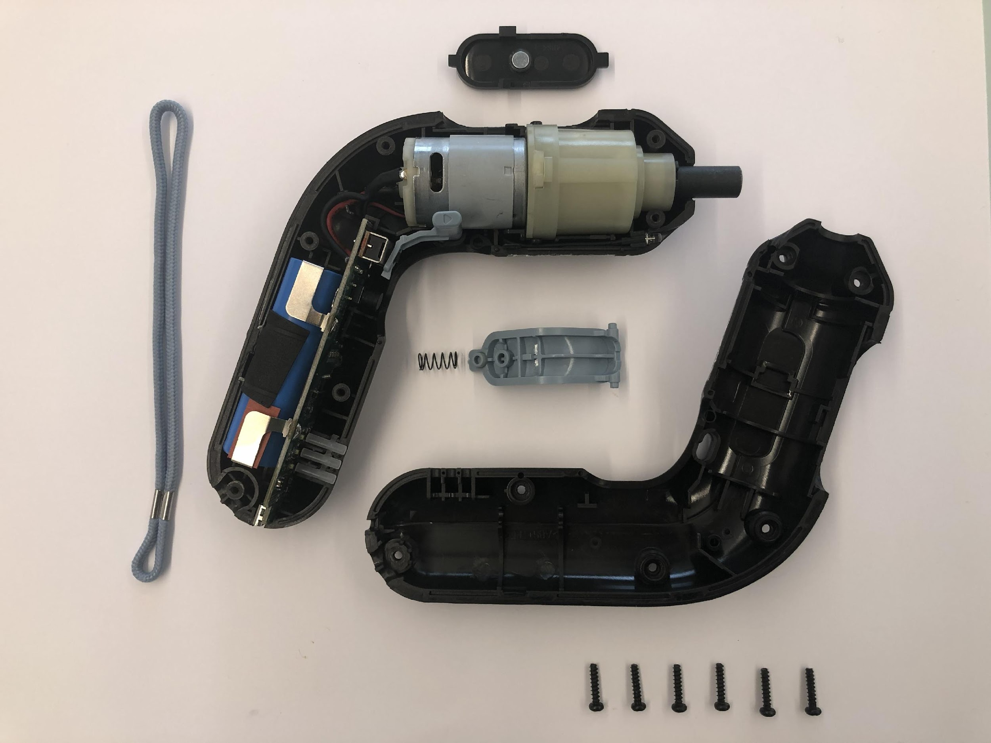
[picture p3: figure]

Komponentane, ordna for fotografering. Skall i to halvdelar (ABS+TPE), motor med planetgir, PCB med li-ion-celle og USB-A-port, avtrekkjar med fjør og glidelås, snor, seks selvgjengande skruer.

Det teardown viser om arkitekturen

Skallet er to halvdelar i ABS+TPE som klemmar saman om alle indre komponentar. Det er seks selvgjengande skruer som held heile produktet saman. Innvendig festast PCB med litium-cella mot den eine halvdelen via skum-tape og metallklemmer. Motoren ligg i si eiga rom, hovudet, kopla til PCB med to lødde leidningar.

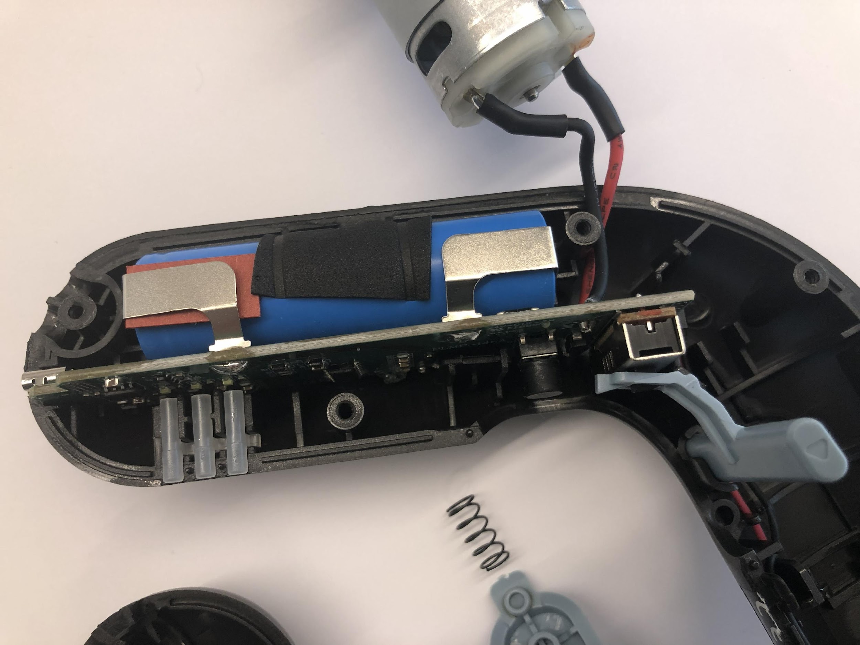
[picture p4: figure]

Batteriinnfesting i detalj. Cella er ein 18650-format li-ion presset mot PCB med metallfjørar. Ho er ikkje lødde, men ligg innesperra mellom skum og fjørklemmer som berre er tilgjengelege når heile skallet er skrudd opp.

Den siste setninga er kritisk for designprosjektet. Cella i seg sjølv er fysisk bytbar. Det er innfestinga som er forsegla. Det betyr at briefen sin føresetnad om at «batteriet skal nyttast på nytt» er kompatibel med ein heilt ny ytre arkitektur, så lenge eg respekterer 18650-formatet og dei elektriske kontaktane.

Det teardown viser om reparasjon

1. Seks skruer for å opne, ikkje noko lim eller ultralydsveis. Dette er positivt.
2. Cella er presset, ikkje lødde. Også positivt.
3. Men: opninga krev at heile skallet demonterast. Det finst ingen dedikert batteri-luke. Slik forblir produktet i praksis ikkje-reparerbart for sluttbrukar.
4. PCB inneheld både ladelogikk og brytarkrets på same kort. Skal eitt felt feile, må heile kortet bytast.
5. Materialvalet (ABS+TPE) er to-komponent injection moulding, det vil seie hardt og mjukt plast er kjemisk bunde i same del. Materialseparasjon ved resirkulering er dermed vanskeleg.

Dette er den empiriske bakgrunnen for designprinsippa eg vil etablere. TRIXIG er ikkje bygd med vond vilje. Han er bygd med ei eldre forståing av kva eit forbrukarprodukt skal vere. Mi oppgåve er å oppdatere arkitekturen, ikkje å fordømme han.

4. Kritisk lesing av TRIXIG som produktkonsept

Utover den interne arkitekturen finst det seks systemiske mønster ved TRIXIG som peikar på kvar redesignet bør gripe inn. Dei er dokumenterte i IKEA si eiga produktinformasjon, kundeomtaler og produkthistorikk. Eg presenterer dei her som visuelle figurar med kort prosa-kommentar.

Det semantiske gapet

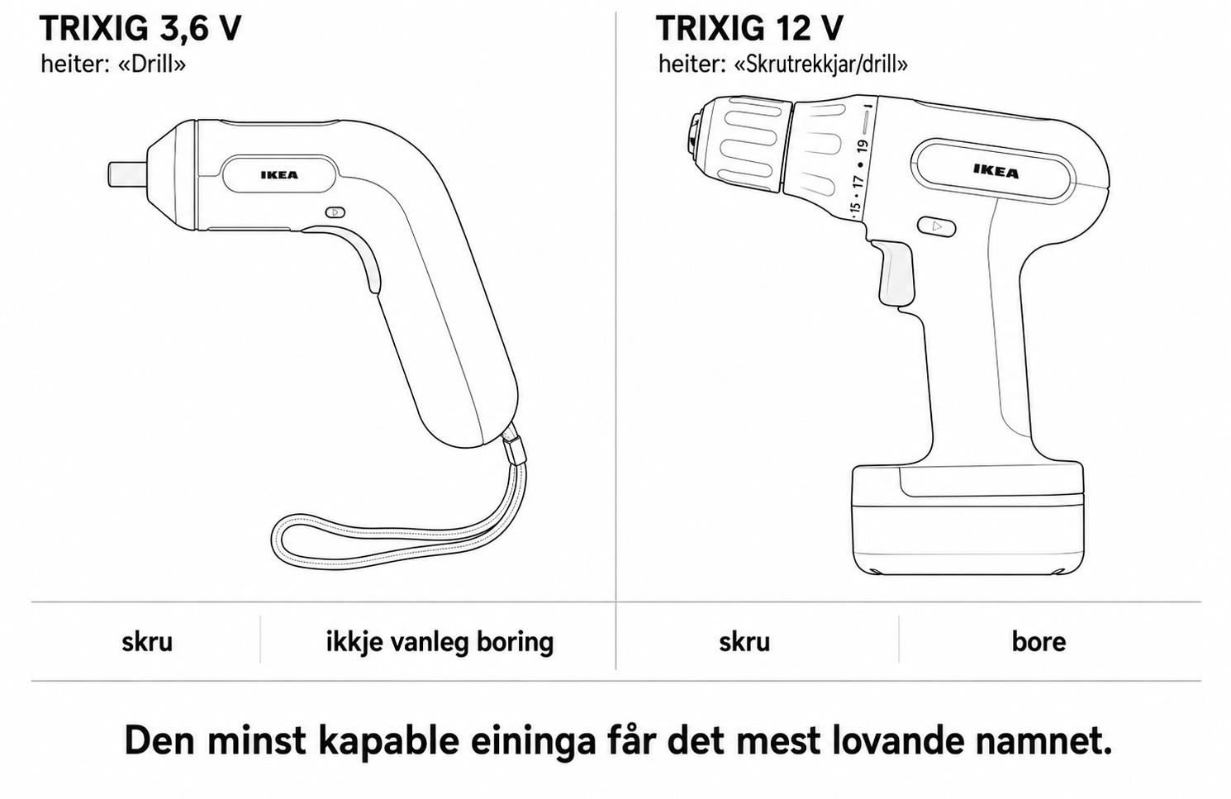
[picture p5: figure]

3,6 V-modellen heiter «Drill», men kan i følgje datablad-finskrifta ikkje bore i vanlege materiale utan forboring. Pistolforma og litium-cella signaliserer ein drill, mens funksjonen er ein skrutrekkjar. Marknadsføringa lever i avstanden mellom forma og funksjonen, og overlet finskrifta til å ta ansvaret når kunden forstår skilnaden. For redesignet betyr dette: eg må kalibrere namn, form og kommunikasjon slik at forventninga matchar funksjonen.

Den tomme esken

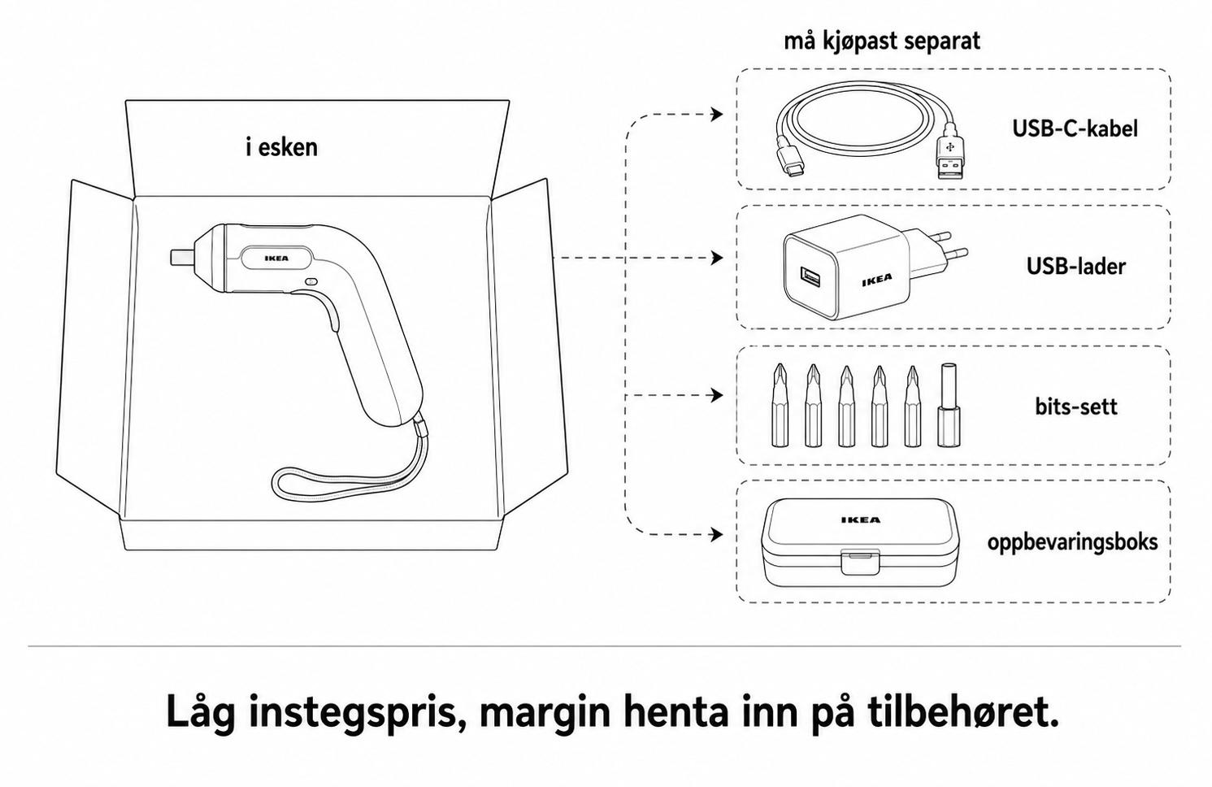
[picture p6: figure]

USB-C-kabel, ladar og bits sel alle separat[^2]. Kunden kjøper eit verktøy som verken kan ladast, brukast eller lagrast med det esken faktisk inneheld. Marginen blir henta inn på tilbehøret heller enn på sjølve produktet, etter klassisk razor-and-blades-logikk. For redesignet er dette ein kommersiell premiss eg må respektere (briefen seier eksplisitt at ingen systemkomponentar skal følgje med), men ein eg òg må arbeide imot der det er mogleg, til dømes ved å designe forma slik at fråværet av tilbehør ikkje gjer produktet uforståeleg ved første møte.

Frå orange til blå: nedgraderinga

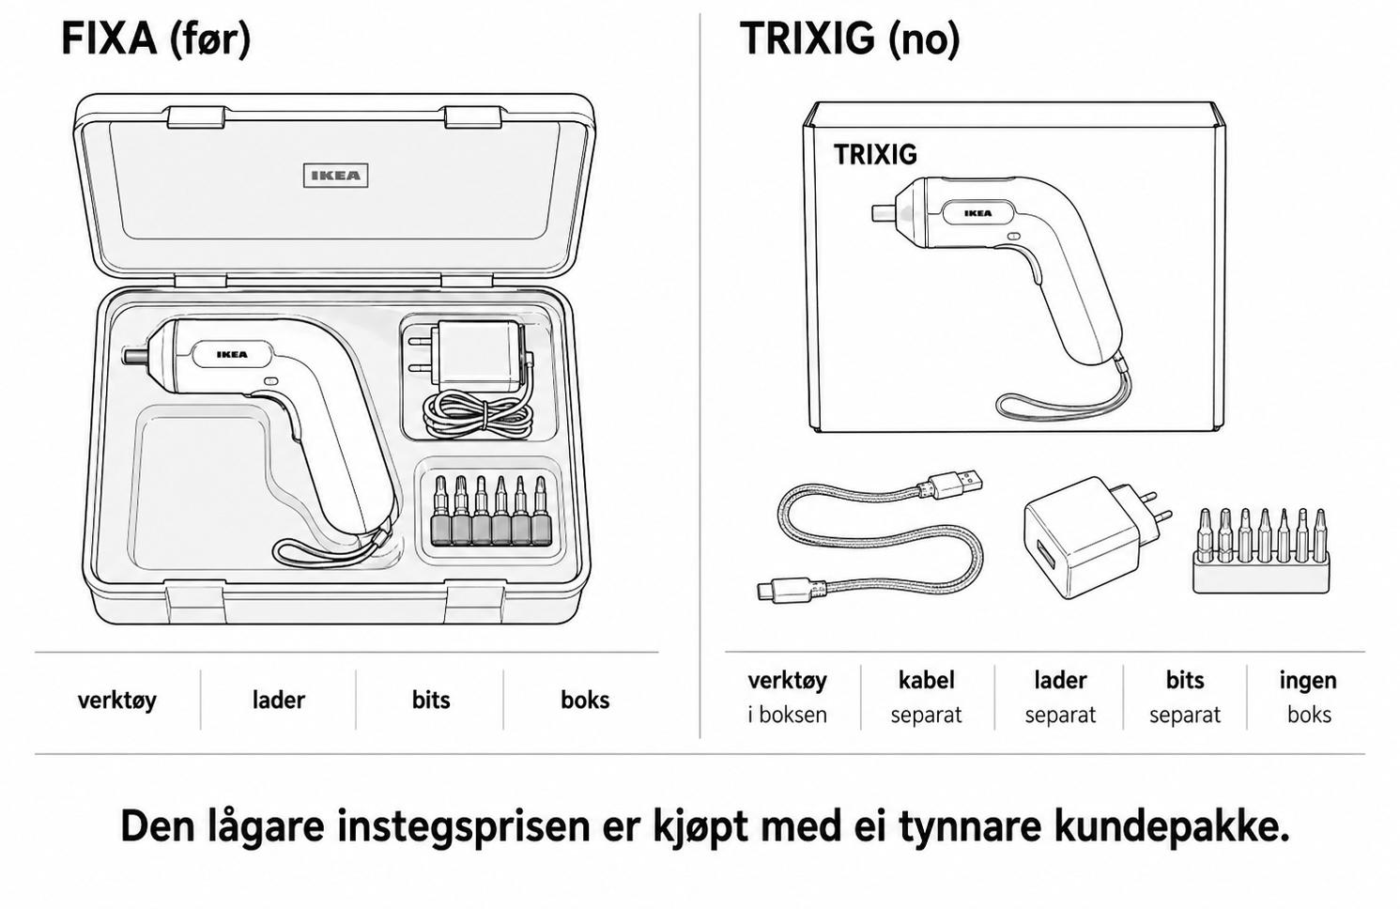
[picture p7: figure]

Førgjengaren FIXA inkluderte ladar, ti bits og ein dedikert oppbevaringsboks. TRIXIG har stripa bort alle desse, og kunden bestiller dei separat. Sett mot FIXA er TRIXIG ei dokumentert nedgradering av kundepakken gøymd bak ein lågare instegspris. For redesignet er dette opplysande snarare enn handlingsstyrande: eg veit no at den tomme esken ikkje er ein konsekvens av teknisk naudsyn, men eit kommersielt val. Det betyr at den nye forma kan og bør kompensere semantisk for det som ikkje lenger ligg i pakka.

Lærepengen og stigen

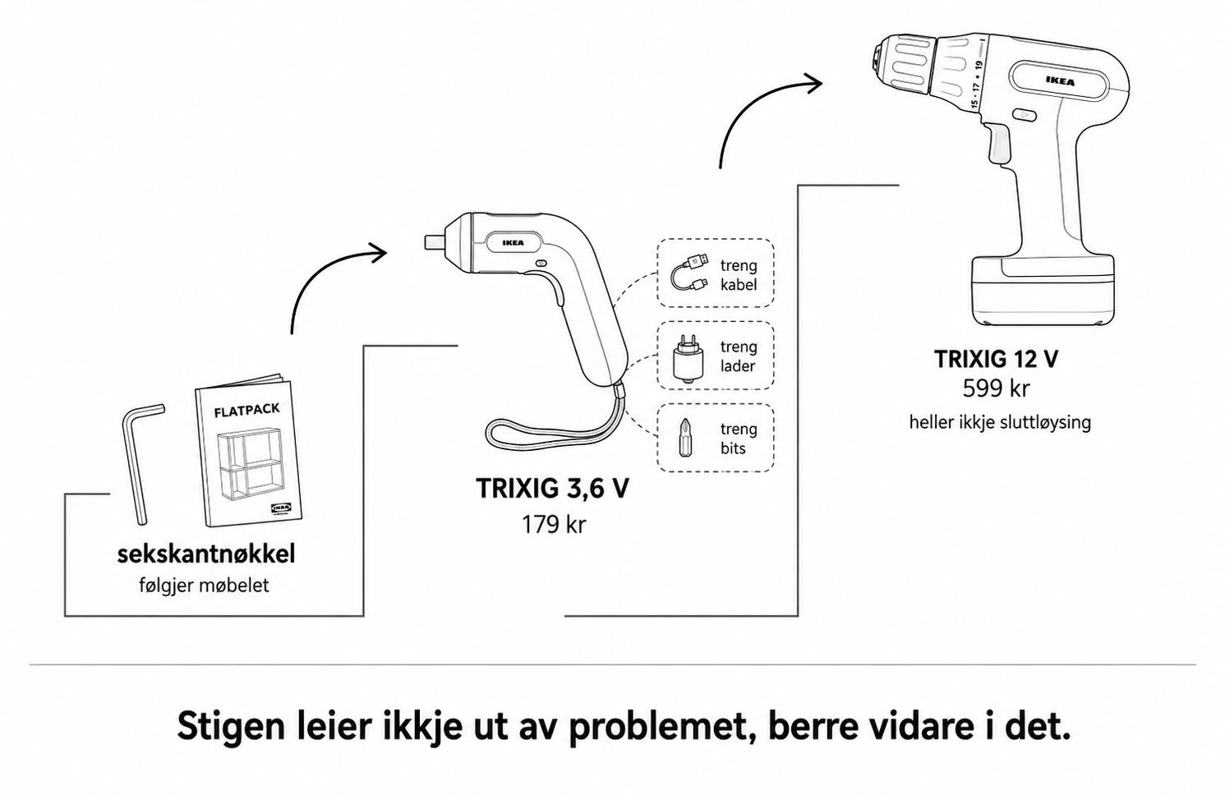
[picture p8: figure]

Den enklaste TRIXIG kostar 179 kroner og har ikkje moment til å montere alle IKEA-møblar. Den dyrare 12 V-modellen kostar 599 kroner. Differansen er ikkje primært ein produksjonsdifferanse, han er prisen kunden betaler for å oppdage at den første einheita ikkje var nok. Stigen leier ikkje ut av problemet, han leier vidare i det. For redesignet betyr dette ein konkret ambisjon: 3,6 V-modellen må kunne handsame fleirtalet av reelle hushaldsoppgåver knyt til IKEA-møblar, slik at lærepengen reduserast eller eliminerast.

Den proprietære batteribindinga

På storesyster-modellen TRIXIG 12 V er batteriet avtakbart, men proprietært. Det passar berre i andre TRIXIG-produkt. Kunden som har kjøpt seg inn på 599 kroner, har samtidig bunde seg til ei batteriplattform med eitt einaste verktøy. Open standardisering, til dømes tilslutning til EPTA-grensesnittet, ville eliminert denne bindinga. For redesignet av 3,6 V-modellen handlar dette om å unngå å reprodusere mønsteret: cella er 18650-standard, så grensesnittet kan og bør vere identifiserbart for ein refurbisher eller ein uavhengig serviceaktør.

Den lukka sirkelen

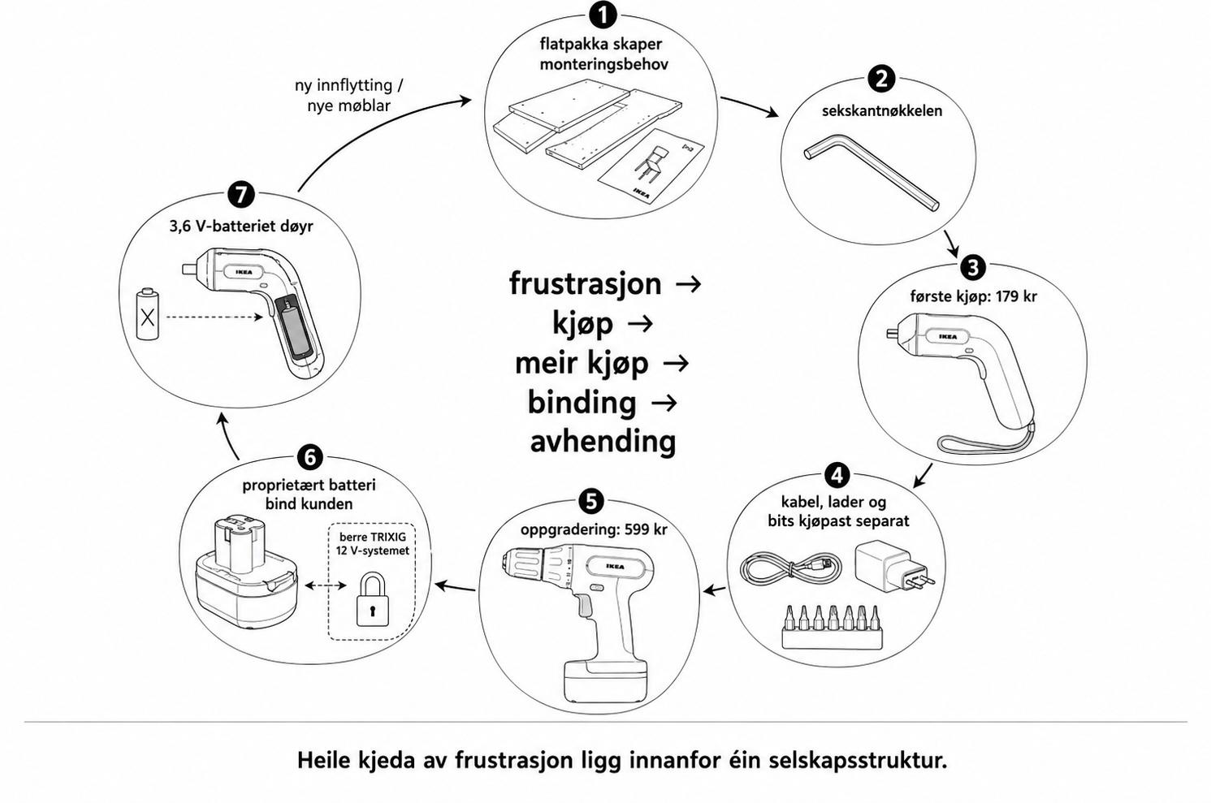
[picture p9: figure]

Flatpakken som IKEA introduserte i 1956 eksternaliserte monteringsarbeidet til kunden[^3]. Sekskantnøkkelen, TRIXIG 3,6 V, oppgraderinga til 12 V, batteribindinga, og det forsegla 3,6 V-batteriet som sluttar å fungere etter tre til fem år: heile kjeda av monteringsfrustrasjon ligg innanfor éin selskapsstruktur. Min oppgåve er ikkje å forsvare denne strukturen, men å levere eit produkt som punkterer minst eitt av leddane. Konkret: eg punkterer leddet om innebygd avhending. Batteriet skal kunne bytast, og det 3,6 V-verktøyet du kjøper i 2028, skal kunne fungere i 2043.

5. Designposisjon

Frå analysen over destillerer eg fem designprinsipp som vil styre prosjektet. Dei er ikkje verdiord i formell forstand, det kjem i fase 3, men dei er bindande for kva eg vil teikne og kva eg vil avvise.

1. REPARERBAR ARKITEKTUR. Batteriet skal kunne bytast utan å demontere skallet. Dedikert batteri-luke med synleg, intuitiv mekanisme.
2. MATERIAL-RUTIDE SKALL. Hard og mjuk plast skal vere mekanisk separable, ikkje to-komponent injection moulded saman. TPE-grep som klikbart belte, ABS-skall som strukturell base.
3. SEMANTISK ÆRLEGHEIT. Forma skal lese «skrutrekkjar», ikkje «drill». Pistolform er fortsatt ergonomisk korrekt, men proporsjonar, namn og marknadskommunikasjon skal kalibrerast slik at kunden ikkje forventar borefunksjon han ikkje får.
4. KOMPAKT UTAN KOMPROMISS. Briefen ber om reduserte ytre dimensjonar. Eg leverer det. Men ikkje på kostnad av reparerbarheita: eit skall som er marginalt større, men opnar seg for batteribytte, vinn over eit som er minimal, men forsegla.
5. TRIXIG-IDENTITET UTAN VENDOR LOCK-IN. IKEA-logo, TRIXIG-fargar (svart hovudskall, lyseblå akssent og snor) skal vere igjenkjennelege. Men batterigrensesnittet skal vere ope, slik at framtidig kompatibilitet med andre TRIXIG-verktøy eller uavhengige standardar er mogleg.

6. Foreløpig kravspesifikasjon

Funksjonelle krav frå briefen

1. Hovudfunksjon: skru og lett boring i softvirke, plast, og lett metall.
2. Bitholder for 6,35 mm hex (1/4″).
3. USB-C-lading. 5 V DC, minimum 1 A.
4. Eksisterande motor (børstemotor med planetgir) og batteri (li-ion 3,6 V, 18650-format).
5. Emballasjevolum maks 993 cm³, helst lågare. IKEA-typografi på pakken.

Tilleggskrav frå analyse og kontekst

1. Batteri utbyttbart med vanleg verktøy eller utan verktøy. (EU 2023/1542)
2. Ingen lim, ingen ultralydsveis i hovudkonstruksjon.
3. Materialvalg som tillèt separasjon ved resirkulering.
4. Færre festepunkt enn dagens seks skruer der det er forsvarleg.
5. Synleg eller halv-synleg konstruksjon som signaliserer at produktet kan opnast.

Avgrensing

Eg vil ikkje levere eit produkt som primært løyser estetiske utfordringar med 3,6 V-modellen, sjølv om briefen i utgangspunktet nemnar formspråk først. Eit reint estetisk redesign ville vore lojalt mot bokstaven i briefen og illojalt mot ånda i fag og marknad.

7. Foreslått berekraftshandling

Som hovud-berekraftshandling foreslår eg eit modulært batterigrensesnitt med femten års reservedel-løfte. Tre lag:
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

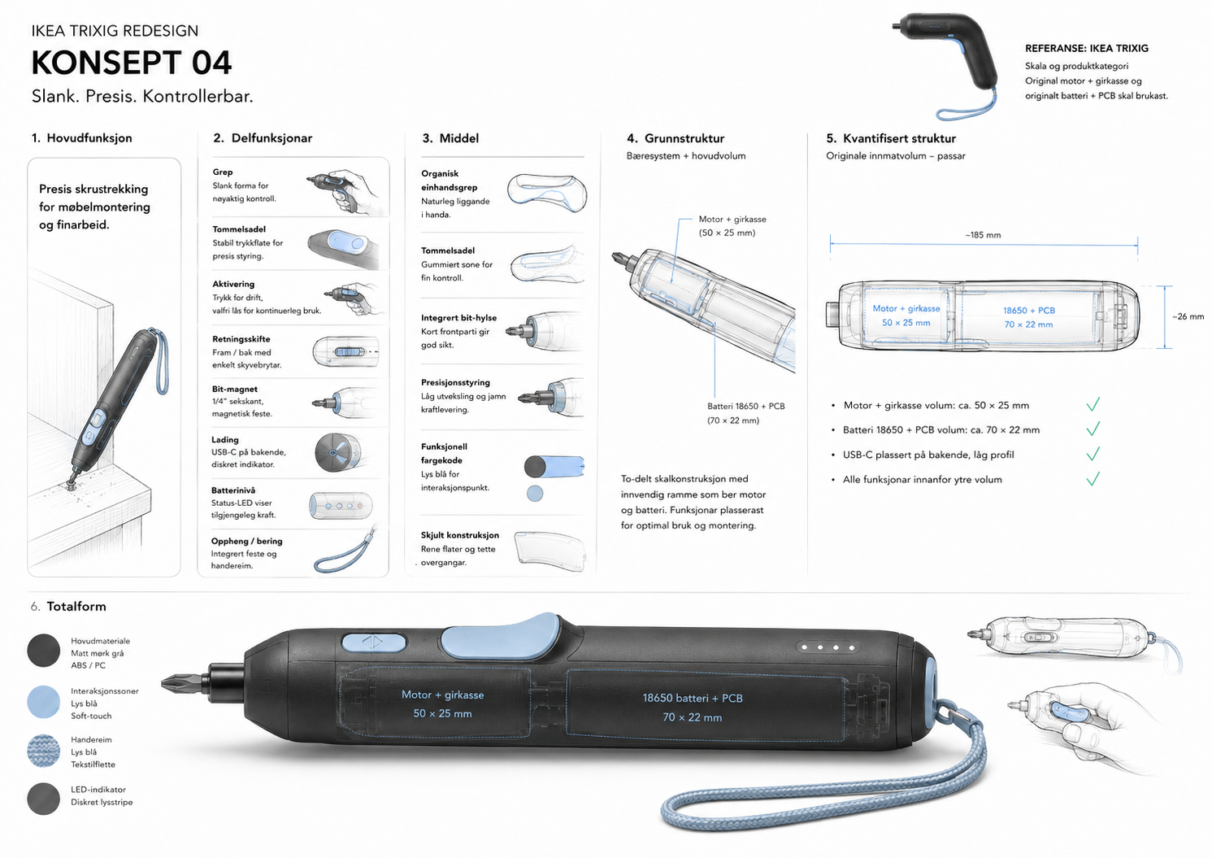
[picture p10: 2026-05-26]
assets/generated/gen_26_05/05_concept_presentations/trixig_260526_u105_concept-04-stick-bar.png

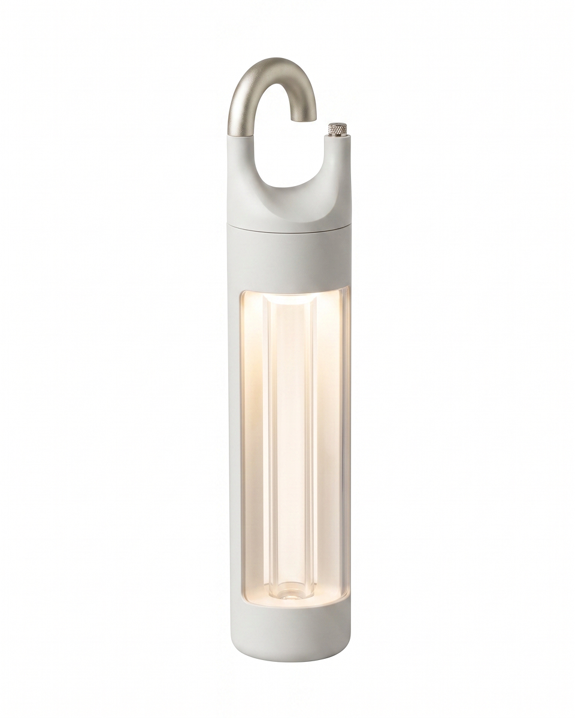
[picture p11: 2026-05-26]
assets/generated/trixig_redesign/trixig_redesign_008.png

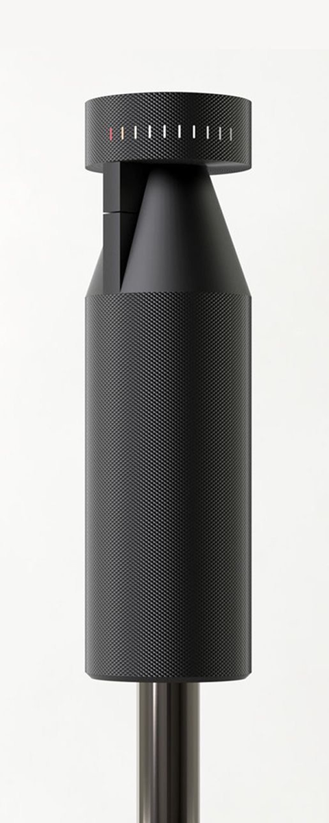
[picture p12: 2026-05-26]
assets/generated/trixig_redesign/trixig_redesign_003.png

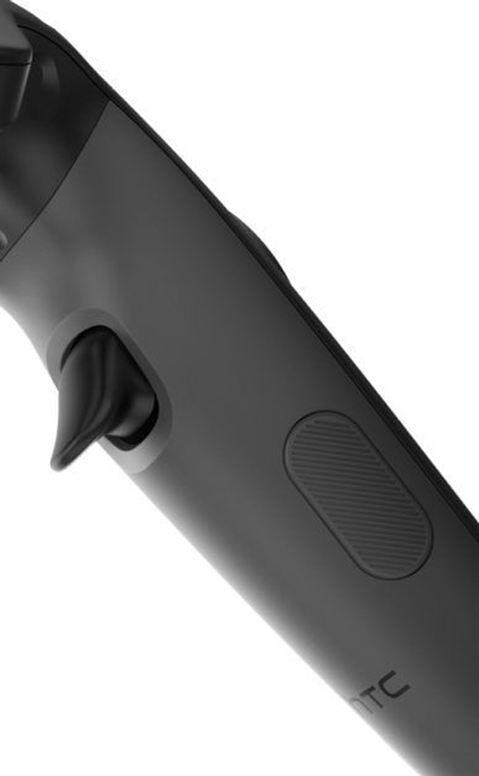
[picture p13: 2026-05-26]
assets/generated/trixig_redesign/trixig_redesign_017.png

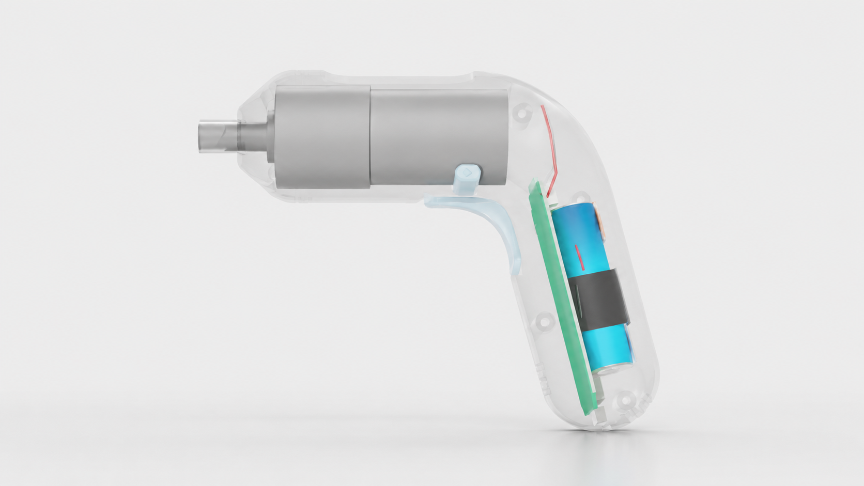
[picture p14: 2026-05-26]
assets/generated/gen_26_05/02_mechanics_cutaways/trixig_260526_u026_white-side-pack-b.png

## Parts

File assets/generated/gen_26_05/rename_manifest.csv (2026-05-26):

unique_id | old_relative_path | new_relative_path | folder | slug | sha256
U001 | ChatGPT Image May 26, 2026, 03_49_36 AM (1).png | 01_reference_renders/trixig_260526_u001_black-side-grip-a.png | 01_reference_renders | black-side-grip-a | a816a8c2bd3e77bd3dc38aef3439a017e8ddf18b290b4c0e84e7651456e649e6
U002 | ChatGPT Image May 26, 2026, 03_49_36 AM (2).png | 01_reference_renders/trixig_260526_u002_black-side-grip-b.png | 01_reference_renders | black-side-grip-b | aff5350255589e130507d5ffb661f09f4c9134a71c764390763f823aa658524b
U003 | ChatGPT Image May 26, 2026, 03_49_36 AM (3).png | 01_reference_renders/trixig_260526_u003_black-rear-angle.png | 01_reference_renders | black-rear-angle | 680a5ff256241ebeecadeb99b41590f697a37dc90ee64736af868140e6295a1a
U004 | ChatGPT Image May 26, 2026, 03_49_36 AM (4).png | 01_reference_renders/trixig_260526_u004_black-horizontal-top.png | 01_reference_renders | black-horizontal-top | 27506ff256a5e513c969d6eae25055e0b778ea3e9f3bc6b59a712efe25697893
U005 | ChatGPT Image May 26, 2026, 03_49_36 AM (5).png | 01_reference_renders/trixig_260526_u005_black-top-button.png | 01_reference_renders | black-top-button | 9d1f13a6d07a45855354bd5a28251418948c5bab789ef41cf73f3be3c75eab3e
U006 | ChatGPT Image May 26, 2026, 03_49_36 AM (6).png | 01_reference_renders/trixig_260526_u006_black-front-nozzle.png | 01_reference_renders | black-front-nozzle | 8df9c1e642192db5d7e6968dc83e420d6a71b8064f965fa90a5770dba0e6c52d
U007 | ChatGPT Image May 26, 2026, 03_49_37 AM (7).png | 01_reference_renders/trixig_260526_u007_black-rear-strap.png | 01_reference_renders | black-rear-strap | 9f8d3a69684290314720b33e8e3ec7a9adcf285f4a668ec5eb84fd3222b38347
U008 | ChatGPT Image May 26, 2026, 03_49_37 AM (8).png | 02_mechanics_cutaways/trixig_260526_u008_black-cutaway-side.png | 02_mechanics_cutaways | black-cutaway-side | 5080a4933ccd0c26605d19f01fa91c9d89c3717dbb353a814c8991e8bcf1b390
U009 | ChatGPT Image May 26, 2026, 03_49_37 AM (9).png | 02_mechanics_cutaways/trixig_260526_u009_black-exploded-parts.png | 02_mechanics_cutaways | black-exploded-parts | 720ea271bb0194e483078b33ed987e6da4a5947d87f83a0082bae141f9d55cc8
U010 | ChatGPT Image May 26, 2026, 03_53_13 AM (1).png | 01_reference_renders/trixig_260526_u010_black-side-simple-a.png | 01_reference_renders | black-side-simple-a | 013f6fde1293bfa649ee7f69d0ce416b24e14d70730c6fcd47253d5b955447a9
U011 | ChatGPT Image May 26, 2026, 03_53_13 AM (2).png | 01_reference_renders/trixig_260526_u011_black-side-simple-b.png | 01_reference_renders | black-side-simple-b | 75ec9a8170e8f344e9b4b78fbc1fad73eecd7b2676b855834aebad292e1de37f
U012 | ChatGPT Image May 26, 2026, 03_53_14 AM (3).png | 01_reference_renders/trixig_260526_u012_black-rounded-side.png | 01_reference_renders | black-rounded-side | ada775713704bd947ba66623faf72614d902e500db5544f43fd7ac6fb9f24500
U013 | ChatGPT Image May 26, 2026, 03_53_14 AM (4).png | 01_reference_renders/trixig_260526_u013_black-front-control.png | 01_reference_renders | black-front-control | e4b941c7836d440729c7ff5b5e4833f2a26faf9960b7184b65e3b4e5379cfd15
U014 | ChatGPT Image May 26, 2026, 03_53_14 AM (5).png | 01_reference_renders/trixig_260526_u014_black-rear-simple.png | 01_reference_renders | black-rear-simple | 6e73dd8506c1ee1dbef4f32c925a4ba5799ce4479649123062991059da99396a
U015 | ChatGPT Image May 26, 2026, 03_53_14 AM (6).png | 01_reference_renders/trixig_260526_u015_black-side-trigger.png | 01_reference_renders | black-side-trigger | 672d47a77b3578f7c3c9488c152881a45df940c58adba0c751aa37dd3c784744
U016 | ChatGPT Image May 26, 2026, 03_53_14 AM (7).png | 02_mechanics_cutaways/trixig_260526_u016_black-cutaway-battery.png | 02_mechanics_cutaways | black-cutaway-battery | ff23c20325a9cd3bd902f0b1aff24a85834ac65f9eb7ce54e0af76c2154943b6
U017 | ChatGPT Image May 26, 2026, 03_53_14 AM (8).png | 02_mechanics_cutaways/trixig_260526_u017_black-exploded-system.png | 02_mechanics_cutaways | black-exploded-system | 48ec558f489761bdfeb7c92dc23cc9aabd63d0097ac1bd574f6f6e0bd382ad6c
U018 | ChatGPT Image May 26, 2026, 03_53_15 AM (9).png | 02_mechanics_cutaways/trixig_260526_u018_motor-battery-module.png | 02_mechanics_cutaways | motor-battery-module | eb1fa0a7e958126917ad757ea97282c8ebda1ed19468d1faff851b37c4a6962a
U019 | ChatGPT Image May 26, 2026, 03_54_37 AM.png | 02_mechanics_cutaways/trixig_260526_u019_white-side-motorhandle.png | 02_mechanics_cutaways | white-side-motorhandle | d3fc643b5548361a4f4ee2d3c1dd8a5e5d98c1e30b2697a0d4c054c43f396c8b
U020 | ChatGPT Image May 26, 2026, 03_54_38 AM (1).png | 02_mechanics_cutaways/trixig_260526_u020_white-open-translucent.png | 02_mechanics_cutaways | white-open-translucent | 943e7b8dddef564066bd3bd4ed0c764ca1ec60b7e385d03246ba03d33190aeb7
U021 | ChatGPT Image May 26, 2026, 03_54_38 AM (2).png | 02_mechanics_cutaways/trixig_260526_u021_translucent-side-pack.png | 02_mechanics_cutaways | translucent-side-pack | 6f811d5a43253d28e70d17372cadd34736573496776660a220741e4534ff1f6b
U022 | ChatGPT Image May 26, 2026, 03_54_39 AM.png | 02_mechanics_cutaways/trixig_260526_u022_front-pack-view.png | 02_mechanics_cutaways | front-pack-view | 733861cc0caef82a0f1c11ab7615266a053619bde0311e9a01c3f17e69e524c7
U023 | ChatGPT Image May 26, 2026, 03_54_39 AM (2).png | 02_mechanics_cutaways/trixig_260526_u023_white-side-pack-a.png | 02_mechanics_cutaways | white-side-pack-a | bbfdcc4932173e5f191a7eb107829343c93d987a96aeb3f601f233caabdeb860
U024 | ChatGPT Image May 26, 2026, 03_54_39 AM (3).png | 02_mechanics_cutaways/trixig_260526_u024_top-pack-view.png | 02_mechanics_cutaways | top-pack-view | a7729e2ffbd5ca5750d33d49385659b6cab5b751e1e7db6b85ba5068c18a76d5
U025 | ChatGPT Image May 26, 2026, 03_54_40 AM.png | 02_mechanics_cutaways/trixig_260526_u025_white-side-angled.png | 02_mechanics_cutaways | white-side-angled | b8365fa803d30c8f002cf1b8e7982330c48cb92d533d21aedb16a92ebff783ec
U026 | ChatGPT Image May 26, 2026, 03_54_40 AM (1).png | 02_mechanics_cutaways/trixig_260526_u026_white-side-pack-b.png | 02_mechanics_cutaways | white-side-pack-b | 9cc3d14dbbe036a8cb7656c00b62ea444970e5a69f8fc58c0d1155cfe2efbc74
U027 | ChatGPT Image May 26, 2026, 03_54_40 AM (2).png | 02_mechanics_cutaways/trixig_260526_u027_white-side-battery.png | 02_mechanics_cutaways | white-side-battery | 1be9ab9f847f5d9706b1ec59eb95e2c026da02880666eee85aa3762495ba09f3
U028 | ChatGPT Image May 26, 2026, 03_54_40 AM (3).png | 02_mechanics_cutaways/trixig_260526_u028_translucent-handle-motor.png | 02_mechanics_cutaways | translucent-handle-motor | 7e65dad4a84783275168377f34a9316fa55a034968dce12374540b304b40a515
U029 | ChatGPT Image May 26, 2026, 03_54_41 AM.png | 02_mechanics_cutaways/trixig_260526_u029_white-side-flat.png | 02_mechanics_cutaways | white-side-flat | ca0cd9020e3aece7b534146312665a063f701bdf384932fafc1f2820eca2b103
U030 | ChatGPT Image May 26, 2026, 03_54_42 AM.png | 02_mechanics_cutaways/trixig_260526_u030_translucent-side-grey.png | 02_mechanics_cutaways | translucent-side-grey | 444ee4f46860ac1b76c62f4bfd583a1de63d6e3f7a0299ce8f6165891651fdcf
U031 | ChatGPT Image May 26, 2026, 03_54_43 AM.png | 02_mechanics_cutaways/trixig_260526_u031_white-side-pack-c.png | 02_mechanics_cutaways | white-side-pack-c | ef8624e394cadac77a058f14bda753e65f506bd864fad361d619b8e9780a4208
U032 | ChatGPT Image May 26, 2026, 04_07_55 AM (1).png | 03_process_boards/trixig_260526_u032_wireframe-overview.png | 03_process_boards | wireframe-overview | e233ed7364f5182194f333f2d986f175526c566de22962faececfae2749958c3
U033 | ChatGPT Image May 26, 2026, 04_07_55 AM (2).png | 03_process_boards/trixig_260526_u033_assembly-flow-board.png | 03_process_boards | assembly-flow-board | 13afea81ce4b8a2f24ca2634770ec5584ec416f00224114df923f51929bbc88d
U034 | ChatGPT Image May 26, 2026, 04_07_55 AM (3).png | 03_process_boards/trixig_260526_u034_component-layouts.png | 03_process_boards | component-layouts | 65b148606f387c362d57f313e53e42f119b0132c3b710f6ae9d0fdf868c36d96
U035 | ChatGPT Image May 26, 2026, 04_07_55 AM (4).png | 03_process_boards/trixig_260526_u035_variant-panels.png | 03_process_boards | variant-panels | c6260ba679261882e8f2592d3a0783656e86b3fcdaa2dcdf38288bc6951b5306
U036 | ChatGPT Image May 26, 2026, 04_07_55 AM (5).png | 03_process_boards/trixig_260526_u036_sequence-variants.png | 03_process_boards | sequence-variants | 5905e515ba7792c8fea5ac79a2a1a809a4c3ad34ec2eb1e3c4c03416f1666c05
U037 | ChatGPT Image May 26, 2026, 04_07_55 AM (6).png | 03_process_boards/trixig_260526_u037_black-render-matrix.png | 03_process_boards | black-render-matrix | 450c7f40fe3cf9791d9917d5e025cd90683cd9ae987964a92f8abb9c805c8eee
U038 | ChatGPT Image May 26, 2026, 04_07_56 AM (7).png | 03_process_boards/trixig_260526_u038_feature-matrix.png | 03_process_boards | feature-matrix | d1d89e85446d0a7b9f1e578b79e28c755c23bb4588aee12a849ac29d3db972a6
U039 | ChatGPT Image May 26, 2026, 04_07_56 AM (8).png | 03_process_boards/trixig_260526_u039_cutaway-hero-board.png | 03_process_boards | cutaway-hero-board | dd1e712f05f66156419479398e9dfc07c04896ca1fa454111de848c4c49945f8
U040 | ChatGPT Image May 26, 2026, 04_07_56 AM (9).png | 03_process_boards/trixig_260526_u040_form-options.png | 03_process_boards | form-options | b7d1f51d866e24ac9903be334afea0f545b83336b4dcb770e97594b6de208eed
U041 | ChatGPT Image May 26, 2026, 04_07_56 AM (10).png | 03_process_boards/trixig_260526_u041_control-zones.png | 03_process_boards | control-zones | fa12801b1a9b226cd83cddf1cf2400538e9e44699ec1c275f5e4859df4ce78df
U042 | ChatGPT Image May 26, 2026, 04_11_04 AM (1).png | 03_process_boards/trixig_260526_u042_tjalve-overview.png | 03_process_boards | tjalve-overview | 2c825df98d2d1f16261e2589172ad174f977cb043ada52e17e55ea6c2c648525
U043 | ChatGPT Image May 26, 2026, 04_11_04 AM (2).png | 03_process_boards/trixig_260526_u043_tjalve-form-grid.png | 03_process_boards | tjalve-form-grid | 6807c16852c4d5b38edaa9b35d44b17106975d5d642b1ac86fce647a8684e140
U044 | ChatGPT Image May 26, 2026, 04_11_04 AM (3).png | 03_process_boards/trixig_260526_u044_body-layouts.png | 03_process_boards | body-layouts | 68b5907e83627a488877f82eccf23fc70a4a5306c4dd1182c4e251d77b8ce5e0
U045 | ChatGPT Image May 26, 2026, 04_11_04 AM (4).png | 03_process_boards/trixig_260526_u045_cutaway-variants.png | 03_process_boards | cutaway-variants | 059b9d105ff65b114c120c83e61735d816a1c10cce833cdc9b1560ad9a1e75d5
U046 | ChatGPT Image May 26, 2026, 04_11_05 AM (5).png | 03_process_boards/trixig_260526_u046_shell-components.png | 03_process_boards | shell-components | 5b06643b81648e62162811ab54faf9894e932eda60db43252994502852e17118
U047 | ChatGPT Image May 26, 2026, 04_11_05 AM (6).png | 03_process_boards/trixig_260526_u047_parts-catalog.png | 03_process_boards | parts-catalog | 3132d0c0011e5d533c94440b87481a2312fd05bb9c5d0653662599d732c6ff1d
U048 | ChatGPT Image May 26, 2026, 04_11_05 AM (7).png | 03_process_boards/trixig_260526_u048_parts-grid.png | 03_process_boards | parts-grid | dea0ec16e54630c6c210d014c2e3b617487e18bc93c87632661775417e12c6dc
U049 | ChatGPT Image May 26, 2026, 04_11_05 AM (8).png | 03_process_boards/trixig_260526_u049_handle-variants.png | 03_process_boards | handle-variants | ba125286bbdc379ffe3ed654c04e01986078841f68f9bcefab4116915e5eedab
U050 | ChatGPT Image May 26, 2026, 04_11_05 AM (9).png | 03_process_boards/trixig_260526_u050_solid-shapes.png | 03_process_boards | solid-shapes | 76a354a21e1cb44e80451e960da04c7a2f43a842e9903331fbdf37cb27dd6bdc
U051 | ChatGPT Image May 26, 2026, 04_11_05 AM (10).png | 03_process_boards/trixig_260526_u051_outline-variants.png | 03_process_boards | outline-variants | 6b5801f92305aaa94ff5357b393f8f1a949e9c481c33e91ff5659cbc49ce1e01
U052 | ChatGPT Image May 26, 2026, 04_21_32 AM.png | 03_process_boards/trixig_260526_u052_hovudfunksjon.png | 03_process_boards | hovudfunksjon | ba52e238d916c13c4168a634cb41107915f75b1dcc1e7014de6e17c5fed5aec7
U053 | ChatGPT Image May 26, 2026, 04_22_05 AM (1).png | 04_decision_boards/trixig_260526_u053_trixig-plus-overview.png | 04_decision_boards | trixig-plus-overview | 578201b575bf6899fa01a3938e7547601ef3396749c1b7c807af66dd2f5f5e3c
U054 | ChatGPT Image May 26, 2026, 04_22_05 AM (2).png | 04_decision_boards/trixig_260526_u054_tjalve-modell.png | 04_decision_boards | tjalve-modell | 52e12207a710b5f151cc5c851bc5158e2634682fd76258db55b530a20432546d
U055 | ChatGPT Image May 26, 2026, 04_22_06 AM (3).png | 04_decision_boards/trixig_260526_u055_grunneigenskapar.png | 04_decision_boards | grunneigenskapar | 5b6c7641bf4b5ea839ca48068959f8592616da80a7856905ef70e806d266968e
U056 | ChatGPT Image May 26, 2026, 04_22_06 AM (4).png | 04_decision_boards/trixig_260526_u056_twenty-batteritilgangar.png | 04_decision_boards | twenty-batteritilgangar | 304a5855df2ce35a77f9b1161e2b8fef50fc84cc57c4fcc23e7a8818b0a2319e
U057 | ChatGPT Image May 26, 2026, 04_22_06 AM (5).png | 04_decision_boards/trixig_260526_u057_twenty-to-six-shortlist.png | 04_decision_boards | twenty-to-six-shortlist | 2d4e43db19f4f11f13cb735c0e045682001953122f4c87c55a71042a332d3283
U058 | ChatGPT Image May 26, 2026, 04_22_06 AM (6).png | 04_decision_boards/trixig_260526_u058_six-to-one-selection.png | 04_decision_boards | six-to-one-selection | 6001722d830328c5d2929a3a6d2d01a20faa64462ff8ba27a4841dcc5b96532d
U059 | ChatGPT Image May 26, 2026, 04_22_06 AM (7).png | 04_decision_boards/trixig_260526_u059_to-hovudelement.png | 04_decision_boards | to-hovudelement | ec3cdfa2ab15c7e928f8daa66dd95125799759bbdc27c8c4447e5684f9c7ab60
U060 | ChatGPT Image May 26, 2026, 04_22_07 AM (8).png | 04_decision_boards/trixig_260526_u060_tre-hovudelement.png | 04_decision_boards | tre-hovudelement | 7de231b9a730f733b799830cf3a963ce18355d8a80c0c627b2f303c896df1716
U061 | ChatGPT Image May 26, 2026, 04_22_07 AM (9).png | 04_decision_boards/trixig_260526_u061_forbodne-rom.png | 04_decision_boards | forbodne-rom | ca6d73819ccb9e9851cd17c68f12a1405649f771c36e7d0269897ef773a344c1
U062 | ChatGPT Image May 26, 2026, 04_22_07 AM (10).png | 04_decision_boards/trixig_260526_u062_sok-vurdering-val.png | 04_decision_boards | sok-vurdering-val | 55be5300448593d4ee3cb93f1444a26f0eb63813a207e996bdaded3bf6a68970
U063 | ChatGPT Image May 26, 2026, 04_22_35 AM (1).png | 03_process_boards/trixig_260526_u063_search-criteria-panels.png | 03_process_boards | search-criteria-panels | 84a10fc601ccc8c95b645c32cbc362497603a1bcb520164829e14365984237da
U064 | ChatGPT Image May 26, 2026, 04_22_35 AM (2).png | 03_process_boards/trixig_260526_u064_form-lineup-wide.png | 03_process_boards | form-lineup-wide | 92b6453adbc6a844f3261ab95d23e7d9fbbcb907a1e6c9e69793e0b7a13175a7
U065 | ChatGPT Image May 26, 2026, 04_22_35 AM (3).png | 03_process_boards/trixig_260526_u065_element-variations.png | 03_process_boards | element-variations | 0ba79ffd1c77919b5e830f8f3267090691208e8a95f7db18d0005e8507276865
U066 | ChatGPT Image May 26, 2026, 04_22_35 AM (4).png | 03_process_boards/trixig_260526_u066_outline-components.png | 03_process_boards | outline-components | 4b23024486bb067b18c703152550a71a74d3f9b42ffe0c554a98d41e8e206529
U067 | ChatGPT Image May 26, 2026, 04_22_36 AM (5).png | 03_process_boards/trixig_260526_u067_component-positions.png | 03_process_boards | component-positions | 784fb683c049ccc0b3be22a55acdd3e89ed9c9c86107faf837408e5238332e82
U068 | ChatGPT Image May 26, 2026, 04_22_36 AM (6).png | 03_process_boards/trixig_260526_u068_internal-layouts.png | 03_process_boards | internal-layouts | af1e6a3cf1fd33935da14edafc5636f91385102ec13f8288a1c962c599d55bc1
U069 | ChatGPT Image May 26, 2026, 04_22_36 AM (7).png | 03_process_boards/trixig_260526_u069_structure-variants.png | 03_process_boards | structure-variants | 5bb25d8cbbec9d83159cc34aa3b87617d36f5e57d21937f3a19dcbf60f776cb2
U070 | ChatGPT Image May 26, 2026, 04_22_36 AM (8).png | 03_process_boards/trixig_260526_u070_battery-sequence.png | 03_process_boards | battery-sequence | 06c39272012f5a999b9b16511ed3ada5f5d5925cd24c4e835b7ac4a4bb399482
U071 | ChatGPT Image May 26, 2026, 04_22_36 AM (9).png | 03_process_boards/trixig_260526_u071_position-variants.png | 03_process_boards | position-variants | 362f23bf4397f802ee406bcae1d8888742e00b1ee086e97ad4938bfe6d8b4efb
U072 | ChatGPT Image May 26, 2026, 04_22_37 AM (10).png | 03_process_boards/trixig_260526_u072_sectioned-form.png | 03_process_boards | sectioned-form | b3168470b4df4149572d5bd630591e90eef829f2bde86ba6c7ab84dd6b1d0a58
U073 | ChatGPT Image May 26, 2026, 04_23_23 AM (2).png | 03_process_boards/trixig_260526_u073_delfunksjonar.png | 03_process_boards | delfunksjonar | 28f7167ad121a8342f0fdfa962040c1d8acf56e10b55cb5ec700a1e70a1609e4
U074 | ChatGPT Image May 26, 2026, 04_23_23 AM (3).png | 03_process_boards/trixig_260526_u074_malet.png | 03_process_boards | malet | e89a9923691999c2ea40faf3af8f3c8b5c21ef571849ef312021e72baad83e7e
U075 | ChatGPT Image May 26, 2026, 04_23_23 AM (4).png | 03_process_boards/trixig_260526_u075_to-hovudelement-detail.png | 03_process_boards | to-hovudelement-detail | 4123aca5323ed0497d79a02ce0614802a4e2756b7feebce8c1c05c9230358a8e
U076 | ChatGPT Image May 26, 2026, 04_23_23 AM (5).png | 03_process_boards/trixig_260526_u076_tre-hovudelement-detail.png | 03_process_boards | tre-hovudelement-detail | b2b17f289da9a62810d98f6332999636332ed256120bfbd6b5de4afaa9b0a460
U077 | ChatGPT Image May 26, 2026, 04_23_23 AM (6).png | 03_process_boards/trixig_260526_u077_forbodne-rom-detail.png | 03_process_boards | forbodne-rom-detail | 5bdce99ba6c51688bac9ab2c2b8805b60d89d0ab921255c2051d64256bb4f553
U078 | ChatGPT Image May 26, 2026, 04_23_23 AM (7).png | 03_process_boards/trixig_260526_u078_kvantifisert-struktur.png | 03_process_boards | kvantifisert-struktur | b30826ec88e6fd3fb03cab925987c7288e8beb4cc9f489ae84a92502e0d770f0
U079 | ChatGPT Image May 26, 2026, 04_23_24 AM (8).png | 03_process_boards/trixig_260526_u079_delingsstrategiar.png | 03_process_boards | delingsstrategiar | a3997a0c08e142a20dd8f96f8e294cf44b54430a6c4afaf9af13aff760480ea5
U080 | ChatGPT Image May 26, 2026, 04_23_24 AM (9).png | 03_process_boards/trixig_260526_u080_seks-totalformkonsept.png | 03_process_boards | seks-totalformkonsept | db3dfd45687d2f2b12cb19c994e6271fb2d9b09f0b7378ec82524ff37915d45d
U081 | ChatGPT Image May 26, 2026, 04_23_24 AM (10).png | 04_decision_boards/trixig_260526_u081_valde-eigenskapar.png | 04_decision_boards | valde-eigenskapar | 7c26b2f839a9e6a762cd57a94308c2b67c6dd1190475099bafb59f1c9d0c6f1d
U082 | ChatGPT Image May 26, 2026, 04_23_55 AM (1).png | 04_decision_boards/trixig_260526_u082_context-selection.png | 04_decision_boards | context-selection | d545c0e427051269688139d0c658956b490cce1e19e2141103dda7fac3cf4c4c
U083 | ChatGPT Image May 26, 2026, 04_23_55 AM (2).png | 04_decision_boards/trixig_260526_u083_form-variant-grid.png | 04_decision_boards | form-variant-grid | a6b8b5b02e88ef642160584fc0804fb3c9cc3f039ee12fcbc6af7c494a04b19d
U084 | ChatGPT Image May 26, 2026, 04_23_55 AM (3).png | 04_decision_boards/trixig_260526_u084_trigger-housing-variants.png | 04_decision_boards | trigger-housing-variants | 3e845615e53f66c547efc09ef13ac9690fa891604875ea9cacf4efb47e87e4fb
U085 | ChatGPT Image May 26, 2026, 04_23_55 AM (4).png | 04_decision_boards/trixig_260526_u085_motor-battery-modules.png | 04_decision_boards | motor-battery-modules | bc8fe52ca3e2a687318926c147e09b2db9abbf392f5b46fbb7da6f0865066ea4
U086 | ChatGPT Image May 26, 2026, 04_23_56 AM (5).png | 04_decision_boards/trixig_260526_u086_internal-split-layout.png | 04_decision_boards | internal-split-layout | f1cb4b9f355c3b466ec98077eef36d2ee910b328ea31fb1e8aa77300b1b5e0bf
U087 | ChatGPT Image May 26, 2026, 04_23_56 AM (6).png | 04_decision_boards/trixig_260526_u087_grip-angle-variants.png | 04_decision_boards | grip-angle-variants | 53e5cf4cb5832a64b8c84055b68ec82ab58d012eb29868a5018ee83438038178
U088 | ChatGPT Image May 26, 2026, 04_23_56 AM (7).png | 04_decision_boards/trixig_260526_u088_section-comparison.png | 04_decision_boards | section-comparison | a8833fbb04186316e3816cf843892346fd051b3318631703ff00e4090fed560a
U089 | ChatGPT Image May 26, 2026, 04_23_56 AM (8).png | 04_decision_boards/trixig_260526_u089_geometry-overlay.png | 04_decision_boards | geometry-overlay | c0456398085787f417da70d299be5dfd835112200c292e08ec101f64d78a0f04
U090 | ChatGPT Image May 26, 2026, 04_23_56 AM (9).png | 04_decision_boards/trixig_260526_u090_structure-matrix.png | 04_decision_boards | structure-matrix | 33742a2e8ede0f48ef2935e9ed0e47565b7076bcc04e26bbf79be92632e0c569
U091 | ChatGPT Image May 26, 2026, 04_23_57 AM (10).png | 04_decision_boards/trixig_260526_u091_profile-comparison.png | 04_decision_boards | profile-comparison | f24c8e2e6c579c06cb288c159fd073a19b3a8fdccdfbcc5952e384654c377b12
U092 | ChatGPT Image May 26, 2026, 04_24_33 AM (1).png | 04_decision_boards/trixig_260526_u092_hovudfunksjon-render.png | 04_decision_boards | hovudfunksjon-render | d80d8fc8200af85402f1c423e0a9cee2d14901c11acf75304c1843bf9f93def7
U093 | ChatGPT Image May 26, 2026, 04_24_33 AM (2).png | 04_decision_boards/trixig_260526_u093_delfunksjonar-render.png | 04_decision_boards | delfunksjonar-render | 504225bd83753453a8adcdf9054141c51f3443a9aea87ea2f80899134ed7f3c2
U094 | ChatGPT Image May 26, 2026, 04_24_33 AM (3).png | 04_decision_boards/trixig_260526_u094_model-grunnstruktur.png | 04_decision_boards | model-grunnstruktur | d6fd0aca88f59787c1ad98e02ff1b57244e08228ea85a2443fc264650949d5c0
U095 | ChatGPT Image May 26, 2026, 04_24_33 AM (4).png | 04_decision_boards/trixig_260526_u095_grunnstruktur-options.png | 04_decision_boards | grunnstruktur-options | 9b90f7287ac5f434bad77fd15e1fe68c1a31bbaa2b32f675822a986ea537d05e
U096 | ChatGPT Image May 26, 2026, 04_24_33 AM (5).png | 04_decision_boards/trixig_260526_u096_grunnstruktur-val.png | 04_decision_boards | grunnstruktur-val | 27623334f3125c034f9de8120b19ed667cf929c8ef1c9b3412cb7f1dfcd64035
U097 | ChatGPT Image May 26, 2026, 04_24_33 AM (6).png | 04_decision_boards/trixig_260526_u097_batteritilgang-dims.png | 04_decision_boards | batteritilgang-dims | b8b497df36133460ca51c8ec7b09b15cd2d98437441a619f5e751553556dbb5b
U098 | ChatGPT Image May 26, 2026, 04_24_34 AM (7).png | 04_decision_boards/trixig_260526_u098_batteritilgang-forms.png | 04_decision_boards | batteritilgang-forms | bbb9734ae2d64ae5a83b94d5d77cbce5a3daa8366d965dcae3aa36113bc648e1
U099 | ChatGPT Image May 26, 2026, 04_24_34 AM (8).png | 04_decision_boards/trixig_260526_u099_sok-vurdering-val-matrix.png | 04_decision_boards | sok-vurdering-val-matrix | a8ddafca102b3d6bbb52bf239becacf4941e853cba40794f4a96433137ed5378
U100 | ChatGPT Image May 26, 2026, 04_24_34 AM (9).png | 04_decision_boards/trixig_260526_u100_totalform-directions.png | 04_decision_boards | totalform-directions | c3e995bbb7bf51cbd0a21922a70a8fada4dbf24a0147869ba631ce01cd0aa697
U101 | ChatGPT Image May 26, 2026, 04_24_34 AM (10).png | 04_decision_boards/trixig_260526_u101_totalform-konsept.png | 04_decision_boards | totalform-konsept | 041a6bf27ce236ea1a3e258ac4c03688f0e79dca3b6e849f315b1397678a230b
U102 | ChatGPT Image May 26, 2026, 04_25_14 AM (1).png | 05_concept_presentations/trixig_260526_u102_concept-01-slim-hook.png | 05_concept_presentations | concept-01-slim-hook | 1419eac709b094689f346656de04b4bc45cbbf0ef0d7f79f6e004dd865cc84dd
U103 | ChatGPT Image May 26, 2026, 04_25_14 AM (2).png | 05_concept_presentations/trixig_260526_u103_concept-02-soft-pistol.png | 05_concept_presentations | concept-02-soft-pistol | b2da8354dc81b01cfb4b0434200b86eaaf9bb925277bc6892b5333cc451b6ace
U104 | ChatGPT Image May 26, 2026, 04_25_15 AM (3).png | 05_concept_presentations/trixig_260526_u104_concept-03-capsule-bar.png | 05_concept_presentations | concept-03-capsule-bar | b3a72a832469cc1eeea575598dac853eb00615251dd1e1fee9ddde89b8a6f8d4
U105 | ChatGPT Image May 26, 2026, 04_25_15 AM (4).png | 05_concept_presentations/trixig_260526_u105_concept-04-stick-bar.png | 05_concept_presentations | concept-04-stick-bar | 020a87a7143632d9d3f32c9d5f6e1cc60e603ae3b2476b989c652ec9797b7995
U106 | ChatGPT Image May 26, 2026, 04_25_15 AM (5).png | 05_concept_presentations/trixig_260526_u106_concept-05-arc-grip.png | 05_concept_presentations | concept-05-arc-grip | 3a7b3c0fd06b17bd75c70f7f37f86aad7643cd12e5a4b6001e56a02165230e85
U107 | ChatGPT Image May 26, 2026, 04_25_15 AM (6).png | 05_concept_presentations/trixig_260526_u107_concept-06-ring-tail.png | 05_concept_presentations | concept-06-ring-tail | cd0d1d9d0ea6750538c073f6c8ae45ee4cc0752b21ea70dc3e01ecf67ab74eaf
U108 | ChatGPT Image May 26, 2026, 04_25_15 AM (7).png | 05_concept_presentations/trixig_260526_u108_concept-07-flat-rail.png | 05_concept_presentations | concept-07-flat-rail | f01bd1e107076d46a9575f5cb2df340ba3f2ced75b077f4efa5319b06e59ac54
U109 | ChatGPT Image May 26, 2026, 04_25_15 AM (8).png | 05_concept_presentations/trixig_260526_u109_concept-08-loop-handle.png | 05_concept_presentations | concept-08-loop-handle | 4258cfeaab8e2bbcb78fc28a070ece4674168bd01e17e196a9257e0bb35258a5
U110 | ChatGPT Image May 26, 2026, 04_25_15 AM (9).png | 05_concept_presentations/trixig_260526_u110_concept-09-soft-arc.png | 05_concept_presentations | concept-09-soft-arc | 29fbab8dd10126025322bc3c05b3624734bdbda2995c05eef93fa5e8a0c6e32a
U111 | ChatGPT Image May 26, 2026, 04_25_16 AM (10).png | 05_concept_presentations/trixig_260526_u111_concept-10-compact-oval.png | 05_concept_presentations | concept-10-compact-oval | 95f275c2e26dd1aca331dc2cb1d5c5ac4d57c1bf7e5e543b2c9e15d9fe3fff40
U112 | ChatGPT Image May 26, 2026, 04_32_27 AM (1).png | 06_ideation_grids/trixig_260526_u112_soft-capsule-sketches.png | 06_ideation_grids | soft-capsule-sketches | 75101f30cf5411c45ed03bb7ef340aa33a9e0973a827538d7d66f675768cae44
U113 | ChatGPT Image May 26, 2026, 04_32_27 AM (2).png | 06_ideation_grids/trixig_260526_u113_screwdriver-form-grid.png | 06_ideation_grids | screwdriver-form-grid | e43656df8905fdbc3de3bf51c21f0c9e84efb8294a423c063b67f7b7692be376
U114 | ChatGPT Image May 26, 2026, 04_32_27 AM (3).png | 06_ideation_grids/trixig_260526_u114_capsule-exploded-grid.png | 06_ideation_grids | capsule-exploded-grid | 7c339ac0a0f05815e1cfac69de992b36197aa97554a6646ebea29aec6691ad17
U115 | ChatGPT Image May 26, 2026, 04_32_27 AM (4).png | 06_ideation_grids/trixig_260526_u115_pistol-capsule-grid.png | 06_ideation_grids | pistol-capsule-grid | 34404cf6c6871df84f6d2521b2a204ba4725eefc728c298d5296dba937462525
U116 | ChatGPT Image May 26, 2026, 04_32_27 AM (5).png | 06_ideation_grids/trixig_260526_u116_curved-body-overview.png | 06_ideation_grids | curved-body-overview | 3bd50d0b18a3e65063581ace491aa2fad8d240d18d6a8e43516e21e5d2909cb0
U117 | ChatGPT Image May 26, 2026, 04_32_27 AM (6).png | 06_ideation_grids/trixig_260526_u117_inline-exploded-overview.png | 06_ideation_grids | inline-exploded-overview | 628565441cb63c6d8b70b6436499195c66a75244aef89f6e5280c0ba474ddf73
U118 | ChatGPT Image May 26, 2026, 04_32_27 AM (7).png | 06_ideation_grids/trixig_260526_u118_soft-black-hero-board.png | 06_ideation_grids | soft-black-hero-board | 013e8aa5a66400391689a70767f721c9bbb864c7360e6aae61fd1aa910f9782c
U119 | ChatGPT Image May 26, 2026, 04_32_27 AM (8).png | 06_ideation_grids/trixig_260526_u119_white-pistol-exploded.png | 06_ideation_grids | white-pistol-exploded | f30c60ddcb48ce3d944c7dd1d35309988309a42b364f0134870560120c6dd75e
U120 | ChatGPT Image May 26, 2026, 04_32_27 AM (9).png | 06_ideation_grids/trixig_260526_u120_mixed-render-catalog.png | 06_ideation_grids | mixed-render-catalog | eb3f576dd730d167b8e6c7ca1fe9fd618ce7f03c925e32a64e6e40cc715cd02e
U121 | ChatGPT Image May 26, 2026, 04_32_27 AM (10).png | 06_ideation_grids/trixig_260526_u121_black-render-overview.png | 06_ideation_grids | black-render-overview | b02b4607f60c88252032190c386d9bca0f96cbd892676e85852bd80951a0b6bd
U122 | ChatGPT Image May 26, 2026, 04_34_35 AM.png | 03_process_boards/trixig_260526_u122_tjalve-six-to-three.png | 03_process_boards | tjalve-six-to-three | 31e8ef75e2ceae3b992d62632273b42342c0374f54760425a9cf4ac5cc4ea235
U123 | ChatGPT Image May 26, 2026, 04_34_36 AM.png | 03_process_boards/trixig_260526_u123_tjalve-to-element.png | 03_process_boards | tjalve-to-element | 55ae71854f4e226988799408b3a477b908ce4cd2f32bdbf5bb66e1c5aa91a37e
U124 | ChatGPT Image May 26, 2026, 04_34_36 AM (2).png | 04_decision_boards/trixig_260526_u124_tjalve-sok-vurdering-val.png | 04_decision_boards | tjalve-sok-vurdering-val | 04fb89c480a63c4ecb91efd4ce361ace87484a7b67b6b7c9393422503df46471
U125 | ChatGPT Image May 26, 2026, 04_34_37 AM.png | 03_process_boards/trixig_260526_u125_trixig-tjalve-delingsstrategi.png | 03_process_boards | trixig-tjalve-delingsstrategi | 4db02f721b784bd2d817937c651f0a1ae0fa835c0cee4d189690b4d9514a6922
U126 | ChatGPT Image May 26, 2026, 04_34_37 AM (1).png | 03_process_boards/trixig_260526_u126_tjalve-comparison-lineup.png | 03_process_boards | tjalve-comparison-lineup | cea087c457e230c2659eee0a138d68073def8514fda8b2ee907ae6a7ab49eb13
U127 | ChatGPT Image May 26, 2026, 04_34_38 AM.png | 03_process_boards/trixig_260526_u127_tjalve-totalform-directions.png | 03_process_boards | tjalve-totalform-directions | 2da3bd121f27debe23a9a1401c41ec7c7850a418298e7ae4366458eed3207db1
U128 | ChatGPT Image May 26, 2026, 04_34_38 AM (1).png | 03_process_boards/trixig_260526_u128_transparency-functional-split.png | 03_process_boards | transparency-functional-split | 182ea46cf021fb5efe2f924bf84ef518d114b414814fefb1244fa03b742eeda9
U129 | ChatGPT Image May 26, 2026, 04_34_38 AM (2).png | 04_decision_boards/trixig_260526_u129_evaluation-choice-matrix.png | 04_decision_boards | evaluation-choice-matrix | 4d4826025a2569b3dd031d4a8308715b7604aa8261c044eae600a68c81c7f4d7
U130 | ChatGPT Image May 26, 2026, 04_34_38 AM (3).png | 03_process_boards/trixig_260526_u130_perspective-analysis.png | 03_process_boards | perspective-analysis | c3258eaa29bffde4b3ebb88b292b9b8f988e82d19a82003375d3487bbc8d5aba
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

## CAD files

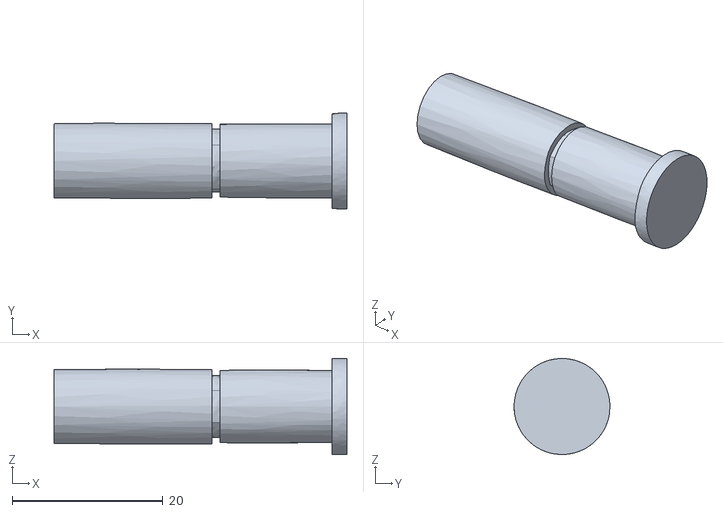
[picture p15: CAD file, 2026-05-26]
cad/print/trixig_redesign/for_bambu/shaft_collar_assy.stl
38.9 x 12.7 x 12.7

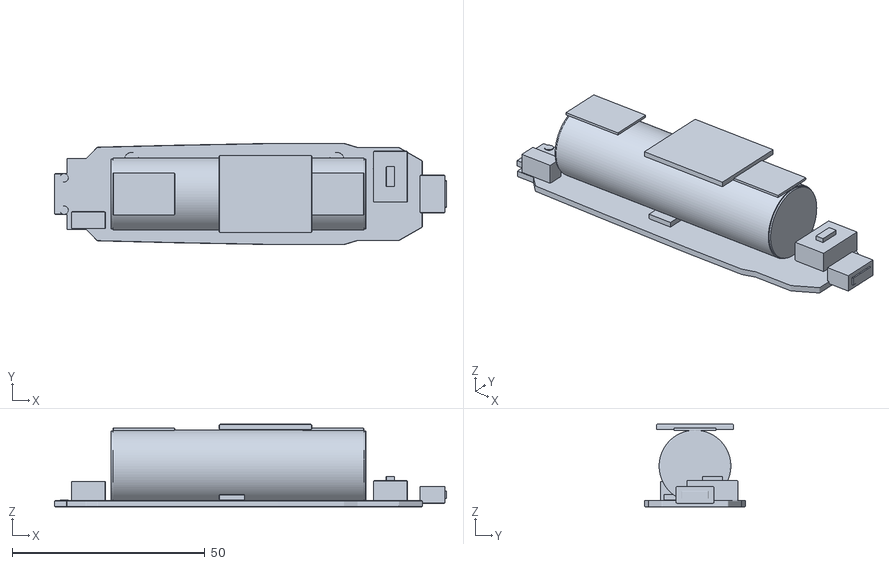
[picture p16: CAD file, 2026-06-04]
cad/fusion/pcb_battery_asset/trixig_pcb_battery_simplified_print_mm.stl
101.6 x 26.3 x 21.4

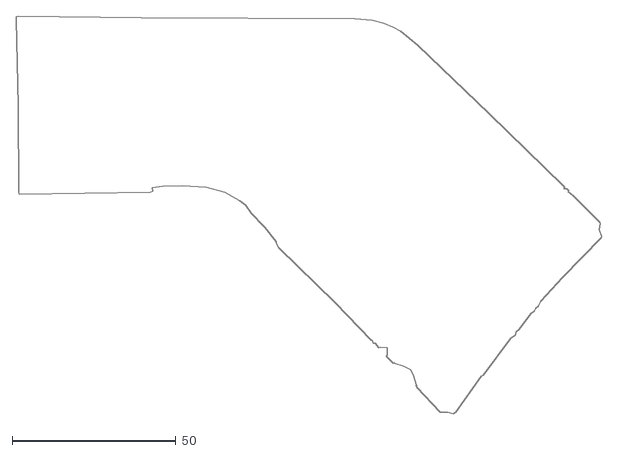
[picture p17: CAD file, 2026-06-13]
cad/fusion/redesign_01/parting_Y0.dxf
178.9 x 121.4

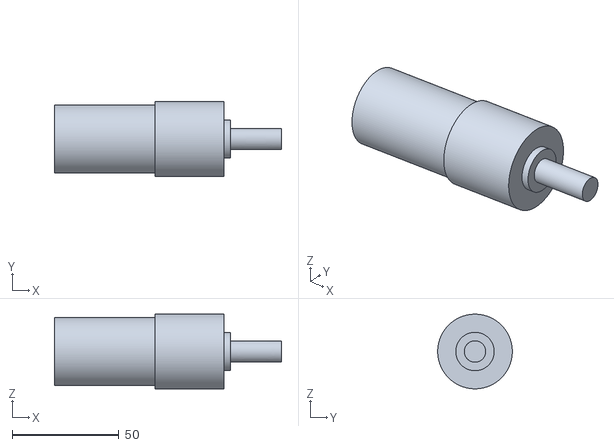
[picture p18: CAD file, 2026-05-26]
cad/models/motorgirkasse_body.stl
106.4 x 35.0 x 35.0

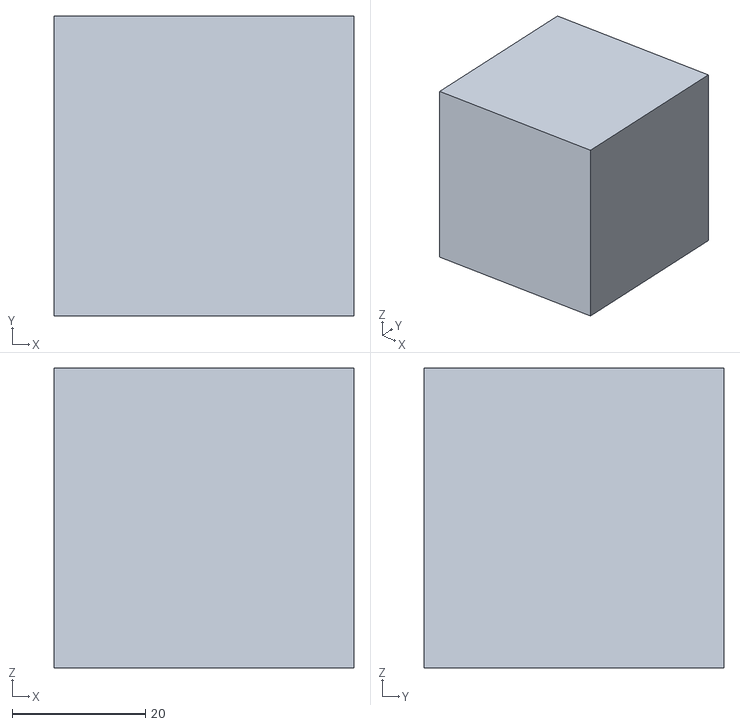
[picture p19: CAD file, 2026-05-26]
cad/print/trixig_redesign/test_cube_45mm.stl
45.0 x 45.0 x 45.0

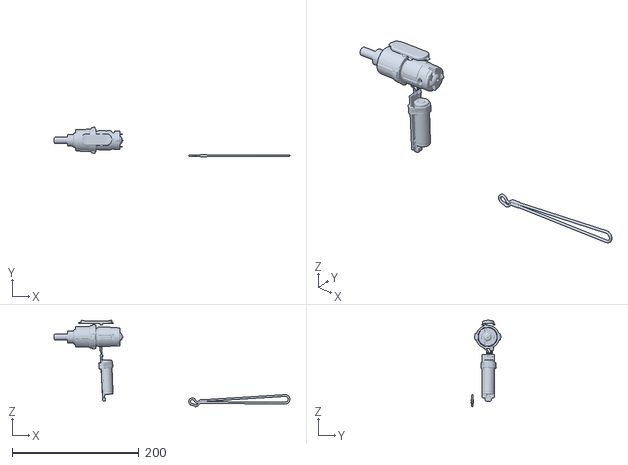
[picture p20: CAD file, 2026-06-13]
trixig_plasticity_mesh_reference_MM.stl
372.1 x 46.8 x 136.6

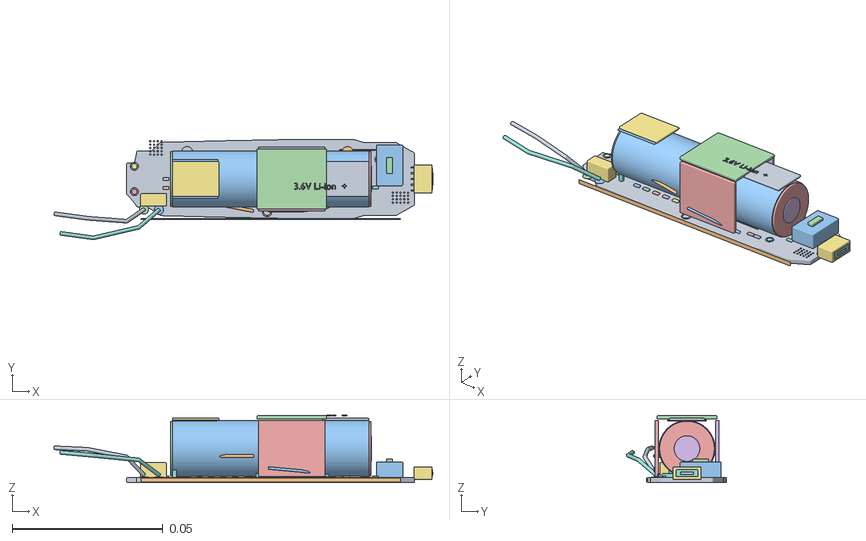
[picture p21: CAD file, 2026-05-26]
cad/fusion/pcb_battery_asset/trixig_pcb_battery_scaled.obj
0.126 x 0.0333 x 0.0222
PCB_95.39x26.31x1.60mm
PCB_laminated_edge_visible
Battery_18650_65.02x18.60mm
battery_negative_cap
battery_positive_cap
battery_positive_button
left_nickel_battery_tab_top
left_nickel_battery_tab_drop
right_nickel_battery_tab_top
right_nickel_battery_tab_drop
copper_isolator_left_under_tab
black_foam_retaining_tape_over_cell
black_foam_tape_left_side
black_foam_tape_right_side
USB_C_outer_shell
USB_C_black_receptacle_opening
USB_C_plastic_tongue
usb_c_pin_-3.8
usb_c_pin_-1.9
usb_c_pin_+0.0
usb_c_pin_+1.9
usb_c_pin_+3.8
motor_wire_white_connector
motor_wire_connector_socket_shadow
B_plus_solder_pad
B_minus_solder_pad
motor_red_solder_pad
motor_black_solder_pad
pcb_dark_hole_1
pcb_gold_annular_ring_1
pcb_dark_hole_2
pcb_gold_annular_ring_2
pcb_dark_hole_3
pcb_gold_annular_ring_3
pcb_dark_hole_4
pcb_gold_annular_ring_4
pcb_dark_hole_5
pcb_gold_annular_ring_5
left_perf_pad_0_0
left_perf_pad_0_1
left_perf_pad_0_2
left_perf_pad_0_3
left_perf_pad_0_4
left_perf_pad_1_0
left_perf_pad_1_1
left_perf_pad_1_2
left_perf_pad_1_3
left_perf_pad_1_4
left_perf_pad_2_0
left_perf_pad_2_1
left_perf_pad_2_2
left_perf_pad_2_3
left_perf_pad_2_4
left_perf_pad_3_0
left_perf_pad_3_1
left_perf_pad_3_2
left_perf_pad_3_3
left_perf_pad_3_4
right_perf_pad_0_0
right_perf_pad_0_1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

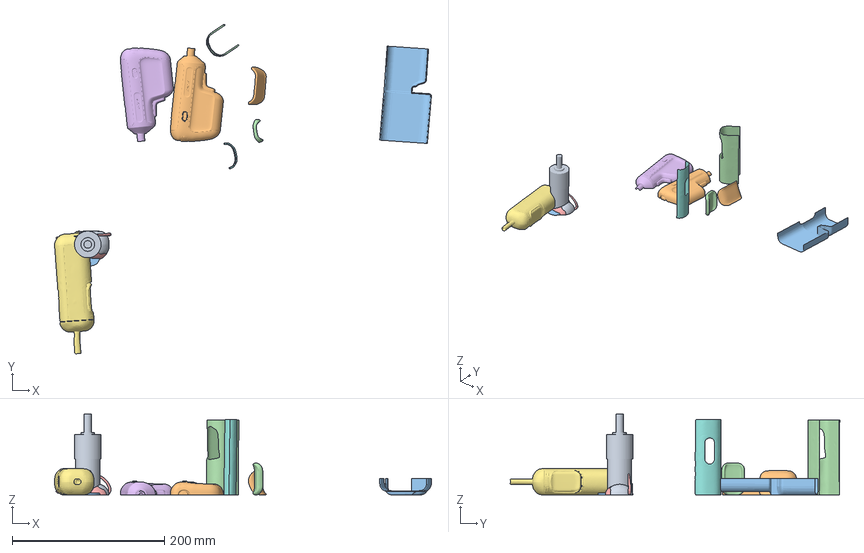
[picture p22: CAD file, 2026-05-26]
cad/models/c0850fe44815dee7c74b3797bde9dd52.3mf
495.6 x 433.2 x 106.4 mm
MotorGirkasse_Body.stl
c0850fe44815dee7c74b3797bde9dd52.stl_B
REDESIGN.stl
base (2).stl_1
Sub-merged body
c0850fe44815dee7c74b3797bde9dd52.stl_A
base (2).stl
base (2).stl_2
base (2).stl_9
base (2).stl_3
base (2).stl_4
base (2).stl_11
base (2).stl_10
base (2).stl_6
base (2).stl_12
base (2).stl_5

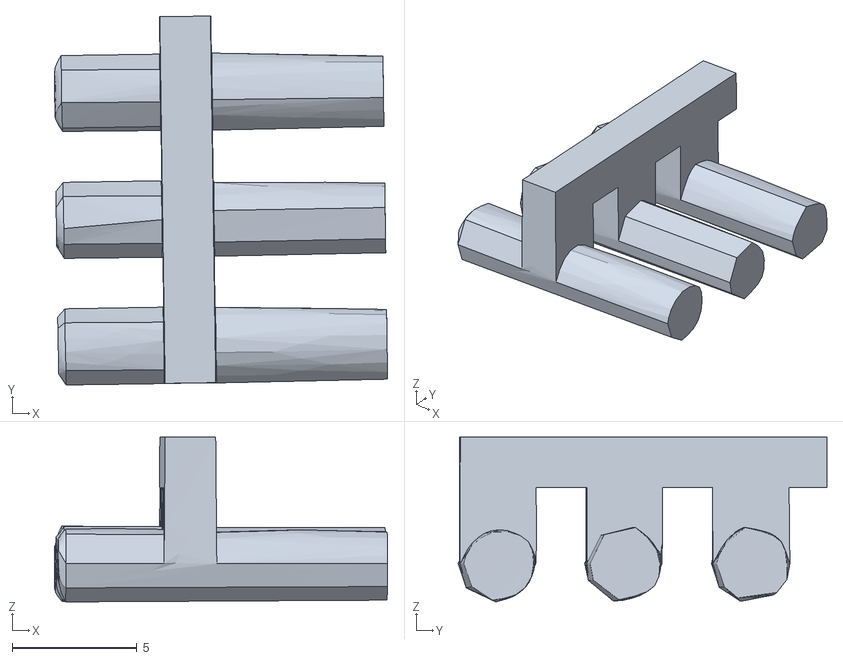
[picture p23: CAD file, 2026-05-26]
cad/print/trixig_redesign/for_bambu/front_end_cap.stl
13.4 x 14.8 x 6.61

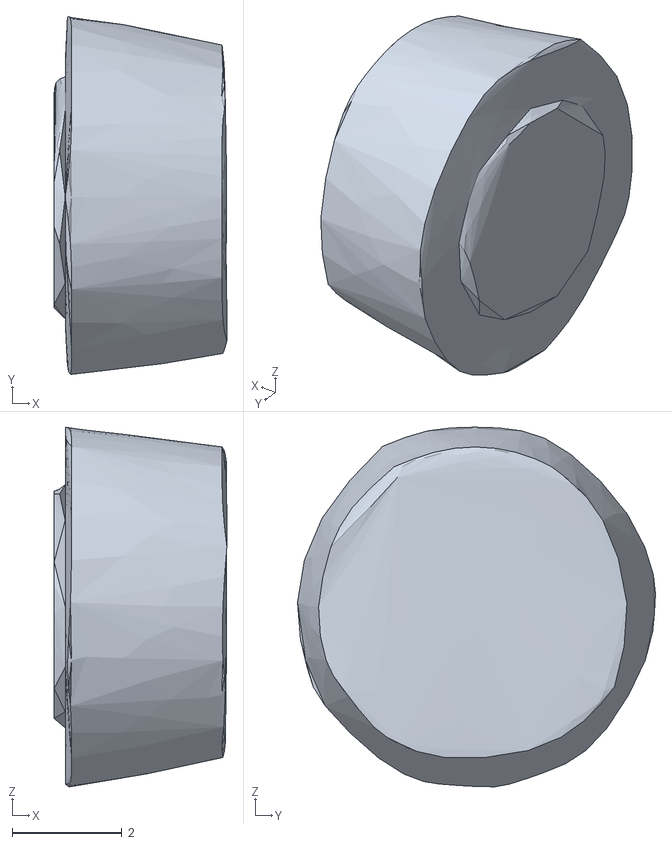
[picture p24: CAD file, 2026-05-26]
cad/print/trixig_redesign/trixig_buildplate_stl_20.stl
3.14 x 6.51 x 6.54

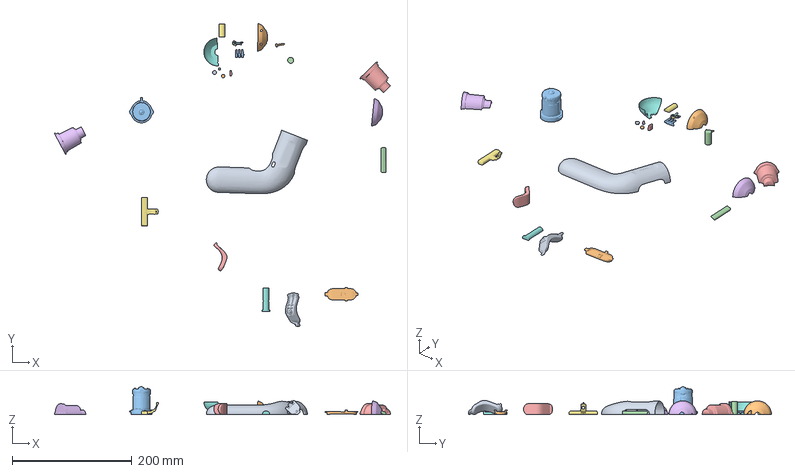
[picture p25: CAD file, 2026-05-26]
cad/print/trixig_redesign/for_bambu/c2.3mf
561.2 x 506.2 x 47.6 mm
bit_holder_cover.stl
direction_switch.stl
front_end_cap.stl
internal_wire.stl
motor_gear_module.stl
rear_end_cap.stl
screw_M3x12_01.stl
screw_M3x12_02.stl
screw_M3x12_03.stl
screw_M3x12_04.stl
screw_M3x12_05.stl
screw_M3x12_06.stl
trigger_button.stl
Tupp.stl_A
base (5).stl
cast.stl_A
cast.stl_B
Tupp.stl_B
Merged Parts
Assembly_B_A
Assembly_rB_B
shaft_collar_assy.stl
tripo_node_9914a911-da01-4db0-adc4-9d06aea56dff
4.stl

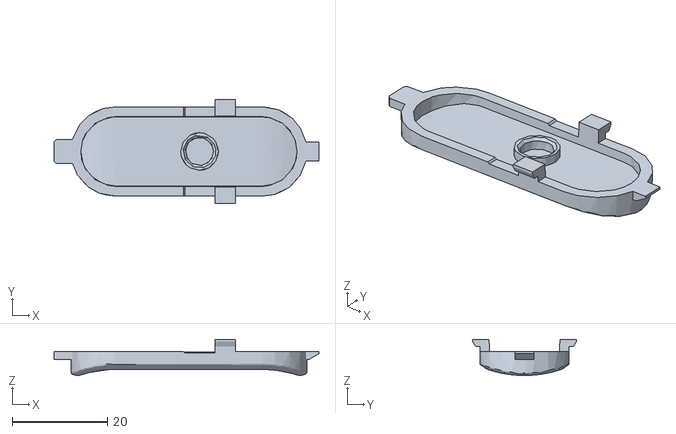
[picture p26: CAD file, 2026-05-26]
cad/print/trixig_redesign/for_bambu/pcba_board.stl
55.7 x 21.8 x 7.67

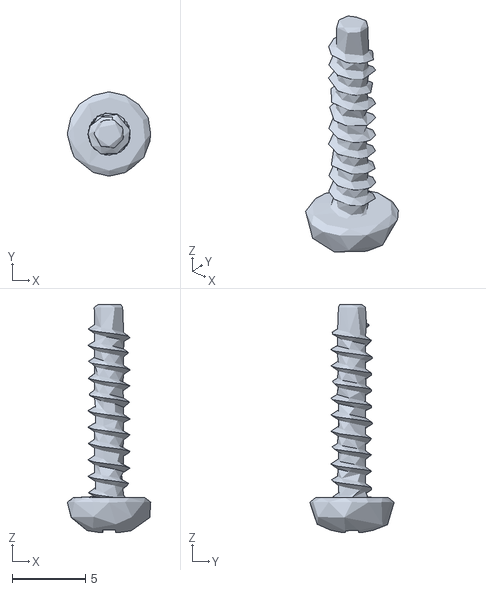
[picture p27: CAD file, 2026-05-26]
cad/print/trixig_redesign/trixig_buildplate_stl_13.stl
5.69 x 5.75 x 15.5

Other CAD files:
cad/print/trixig_redesign/for_bambu/bit_holder_cover.stl
cad/print/trixig_redesign/trixig_buildplate.3mf
cad/print/trixig_redesign/2.stl
cad/print/trixig_redesign/4.stl
cad/fusion/pcb_battery_asset/trixig_pcb_battery_scaled.blend
cad/fusion/pcb_battery_asset/trixig_pcb_battery_simplified_print_mm.blend
cad/print/trixig_redesign/1.stl
cad/print/trixig_redesign/3.stl
cad/print/trixig_redesign/cap_slim.stl
cad/print/trixig_redesign/cap_slim_duplicate.stl
cad/print/trixig_redesign/cast.stl
cad/print/trixig_redesign/cast_for_bambu.stl
cad/print/trixig_redesign/for_bambu/2.3mf
cad/print/trixig_redesign/for_bambu/direction_switch.stl
cad/print/trixig_redesign/for_bambu/housing_bottom_grip.stl
cad/print/trixig_redesign/for_bambu/housing_bottom_tip.stl
cad/print/trixig_redesign/for_bambu/housing_top_grip.stl
cad/print/trixig_redesign/for_bambu/housing_top_tip.stl
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

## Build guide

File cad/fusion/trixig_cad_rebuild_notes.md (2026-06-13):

# TRIXIG 3.6 — parametric CAD completion (2026-06-12)

Fusion document: **"IKEA TRIXIG 3.6 original"** (project *IKEA Redesign GK4*), saved v3+.
Part Design document → parts are **named bodies at root** (Part Design docs cannot hold
components/occurrences; insert this part into a separate assembly design if needed).

## What was completed this session (via Fusion MCP scripting)

1. **Split + shells** — `Body_Main` split on the XZ plane (Y=0 parting plane) into
   `Body_Front` (+Y) / `Body_Back` (−Y); both shelled to **1.6 mm** wall
   (2.0 / 1.8 mm offsets fail on the screw-well and pocket geometry — 1.6 is
   consistent with the real product's molding).
2. **Screw system** — back half got six Ø8.6 × 10 mm bosses on the screw axes;
   Ø2.4 pilots re-drilled through front wall + bosses from the original
   `Screw_Pilots` sketch. (Pilot + strap-pin features had to be removed before
   shelling — Ø2.4/Ø3.0 features cannot be offset inward 1.6 mm — then re-created.)
3. **Strap pin** re-added on `Body_Back` (clip bail wraps it).
4. **Badge + IKEA wordmark** — raised rounded-rect badge (38 × 13 mm, R3.5, ~0.7–1.3 mm
   proud, rim fillet R0.8) on the +Y shell at centre (−237, 110.8); wordmark debossed
   0.4 mm from `ikea.svg` path data (33 mm wide, A-counter island preserved).
   Sketches: `Badge_Outline`, `Wordmark`.
5. **Fwd/rev rocker** — through-slot (9.4 × 5.2 pill) + `Switch_FwdRev` bar body
   (8.8 × 4.6 × 43, rounded ends) at scan position X −234.4…−225.6, Z 93.2…97.8.
6. **USB-C opening** — 9.2 × 3.4 pill cut in the handle base at (−171.5, 0), per scan.
7. **Appearances** — custom `TRIXIG Brown ABS` (62,46,40) shells,
   `TRIXIG Accent GrayBlue` (198,206,212) for panel/buttons/clip/rocker,
   Stainless Steel Satin bit holder, matte black screws/LED.

## Reference dimensions extracted from the Blender concept model (mm)

- Overall 170 × 46.1 × 133.6; parting plane Y=0; drive axis Z = 110.5.
- Barrel Ø45.6 shoulder → Ø44.7, front face X −308.7, nose cone to Ø16.4;
  elbow bend starts ~X −223, centreline bend R≈25.8, turn ≈71°.
- Grip oval 44.4 × 33.0, raked ~17–19° from vertical; domed base.
- Screw positions (X, Z): (−295.7, 98.4), (−295.7, 122.7), (−211.7, 121.1),
  (−196.8, 44.0), (−187.7, 91.5), (−163.2, 12.8); thread Ø2.8 × 13, head Ø5.6 × 2.2.
- Bit holder: shaft Ø10.1, flange Ø12.7, ¼″ hex socket 6.5 AF × 13, tip at X −323.
- Wire bail Ø3.5, hairpin to X −9, legs ≈Z 10.4 / 17→22.

## Known simplifications

- Grip cross-sections are ellipses (≤1 mm fuller than the scanned egg-profile at the
  front shoulders).
- Front screw holes use the original Ø2.4 pilot size (no separate Ø3.4 clearance).
- Panel/buttons are drop-in fits; no snap clips modeled.

## Fusion MCP scripting gotchas (hard-won)

- A script that throws **rolls back everything it did** — guard verification code.
- `Path.create()` needs occurrence **proxies** (`createForAssemblyContext`) for curves
  inside components; root-level curves are fine.
- Loft rails pinned to scan silhouettes beat centerlines for accuracy; loft tangency
  conditions only accept **BRepEdge** sections.
- Shell fails (`ASM_LOP_TWK_*`) on any face that can't offset by the wall thickness:
  holes < 2×wall, knife-edge pocket walls, raised badge pads → do those features
  **after** the shell.
- Part Design documents cannot create occurrences via API.
- A modal command dialog (e.g. MOVE/COPY) blocks **every** MCP call until closed.

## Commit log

2026-04-28 me-startar-med-å-rydde-i-
    [Trixig_plus.scad]
2026-04-28 git add -A git commit -m "Organiser prosjektfiler" git push origin main
    [Trixig_plus.scad]
2026-05-26 Clean up TRIXIG repo structure
    [1.stl, 2.3mf, 2.stl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]
2026-06-04 fs
    sd
    [pcb_battery_simplified_print_mm.stl, trixig_pcb_battery_simplified_print_mm.blend, trixig_pcb_battery_simplified_print_mm.stl]
